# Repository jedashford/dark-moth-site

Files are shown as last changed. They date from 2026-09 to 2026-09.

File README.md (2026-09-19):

# Dark Moth — R6 integrated prototype

R6 combines the confirmed **ESP32-C3 SuperMini**, power electronics and five LED
drivers on one **18-column × 24-row (A–X) isolated-pad carrier**. The case has a
left-side button, the original faceted moth, a removable front diffuser and a
battery bay sized around the user's **67 × 36 × 10 mm, 3000 mAh protected pack**.

[Inspect the complete product](index.html#explore) ·
[Build the carrier in 3D](perfboard.html?board=carrier#workbench) ·
[Exact wiring instructions](CARRIER_GUIDE.md) ·
[Print setup](print.html) ·
[Download the R6 pack](dark-moth-r6-print-pack.zip)

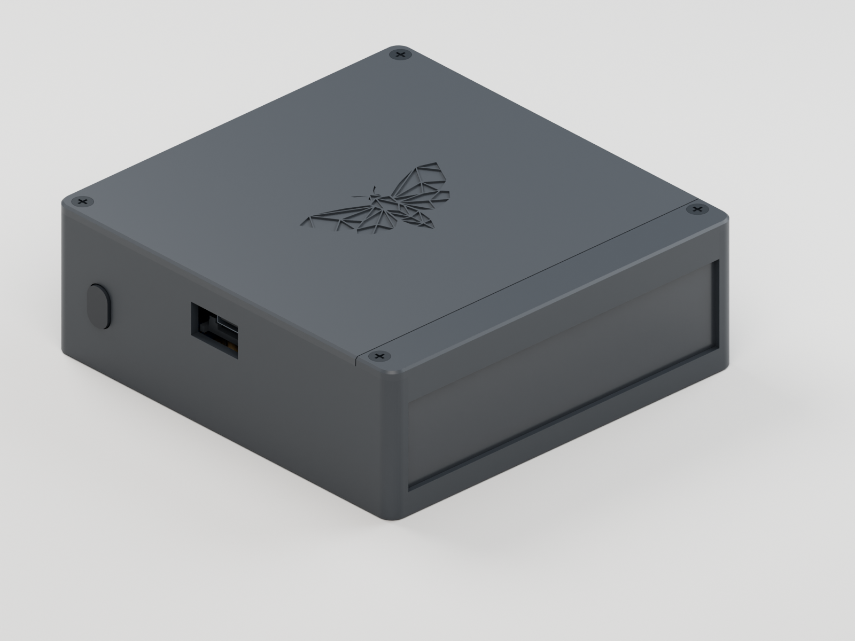
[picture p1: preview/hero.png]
R6 CAD assembly


**Prototype status:** digital checks, source-linked models and firmware builds do
not establish a working physical product. Purchased-part fit, actual battery
lead ratings, low-voltage operation, charging, thermal behavior and optical output
need the bench checks in [the electrical plan](PRODUCT_ELECTRICAL_PLAN.md).
Current evidence is recorded in [VERIFICATION.md](VERIFICATION.md) and
[verification-summary.json](verification-summary.json).

## What changed together

- A removable carrier cassette and raised module supports replace the old
  manufactured latch PCB and separate floor-mounted modules.
- The user's UMLIFE mini USB-C charger, separate regulated 5 V/12 V converters,
  a low-voltage supervisor and low-gate-voltage MOSFETs replace the earlier power arrangement.
  **New parts are required**; use the carrier guide's exact purchasing list.
- Five identical driver groups align on rows C/G/K/O/S. The underside carries
  insulated connections; the guide identifies every solder window and hole.
- The external harness uses **BATTERY 2-pin, BUTTON 2-pin and LIGHTS 6-pin**.
  The light connector is +12 V, green, red, blue, warm white, cool white.
- The ground-contact button uses an isolated active-LOW input. R6 firmware and
  R5 button wiring are incompatible. Flash only the revision you assembled.
- The case retains the original moth and **104 × 28 × 3 mm** removable diffuser.
  A removable insert supports the smaller **42 × 25 × 10 mm** battery.

## Build in this order

1. Read the [carrier guide](CARRIER_GUIDE.md) and check the actual board, module
   markings, battery and connector sizes. The blank is nominally 47.78 × 63.02 mm;
   the user confirmed the hole count, not the measured board outline.
2. Obtain the listed replacements and assemble one board first. Use the 3D
   inspector, hole tables and underside net view together. Shared ground means
   one electrically continuous network; unrelated positive rails and LED returns
   remain separate.
3. Follow the staged, current-limited electrical bring-up before connecting the
   battery. Do not build a batch from an untested first unit.
4. Load [R6 C3 firmware](FIRMWARE_GUIDE.md). Remove the internal 5 V service shunt
   before attaching the ESP's programming USB. The separate charging port faces
   the outside; programming access is with the lid removed.
5. Print and test the [coupon](prints/coupon.stl), then follow the
   [per-part print instructions](PRINT_GUIDE.md). All STL units are millimetres;
   exported files already have their intended bed orientation.
6. Install the carrier, battery restraint, remote button, three plug pairs and
   diffuser. Check the physical wiring and clearances before closing the lid.

## Battery and connectors

The user's battery has a factory 1.25 mm connector. The selected build replaces
only that connector with the kit's two-pin XH-style plug while retaining the
factory wires, protection circuit and sealed pouch. Change one conductor at a
time and insulate its completed contact before cutting the other. Use recessed
contacts on the battery side. Measure polarity before mating; wire colors and
housing orientation do not prove polarity.

The kit marked XH2.54 is not automatically the same geometry or rating as genuine
JST XH (2.5 mm). Use matched contacts/housings from the same kit and confirm their
fit and wire range. The connector model is a nominal fit allowance. Battery and
button are both two-pin: label both mating halves and keep them in their separate
case locations. Never swap them.

## Charge with the device off

Hold the side button for two seconds until the red cue, then release to shut
both regulated rails and the controller down. Only then connect charging USB.
Leave the button alone while charging; disconnect USB before switching the
device on again. A short tap or a Bluetooth "off" command only blacks out the
LEDs and is not the complete shutdown required for charging.

The smaller charger has no implemented automatic USB lockout or system
power-sharing circuit. This is the user-selected **off-while-charging** build.
Its battery terminals B+/B− and system terminals OUT+/OUT− have distinct roles;
the complete carrier ground goes to OUT−, never across the protection path.

Use the electrical guide's supervised open-case first-charge checks. Identify
and measure the actual charge setting, cell temperature, termination and
low-voltage cutoff before enclosing a unit. No pack-temperature sensor is
connected to this generic charger. [The charger review](CHARGER_REVIEW.md)
records the supplied module and limits.

## Print and service

[PRINT_GUIDE.md](PRINT_GUIDE.md) lists supports and orientation for every part.
[cad/parts.json](cad/parts.json) is the printable inventory. The downloadable
native support projects are unsliced reference setups; choose your real printer,
material and nozzle and inspect generated support paths before printing.

The diffuser is **purchased smoked acrylic**. `diffuser.stl` is its cutting/fit
template, not a recommendation to block the light with opaque black PETG.
Remove the two front rail screws to withdraw the sheet without opening the
main electronics lid. The dark stock previously described for the older case
was only about 94.8 mm wide; confirm the actual sheet before cutting 104 mm.

Disconnect battery and charging USB before lifting the electronics cassette.
Printed supports and the insulating liner must never press exposed solder joints
against metal hardware or the battery pouch. Wires need service slack and
strain relief at the plug saddles.

## Reproduce the design

Run from `v3-button/enclosure/`, or the extracted `dark-moth-r6/` directory.
Install OpenSCAD, Blender, Bambu Studio, Arduino CLI/ESP32 core and the Python
requirements. Geometry, slicing, firmware and browser checks use local temporary
workspaces; no command below uploads firmware or sends a print job.

```sh
python tools/build_perfboard_layout.py
python tools/build_perfboard_worksheets.py
python tools/verify_r6_electronics.py
python tools/build_firmware.py
python tools/build.py
python tests/verify.py
python tests/verify_variants.py
python tests/test_printability.py
python tools/slice_check.py
python tools/build_print_project.py
python tools/build_guide.py
/Applications/Blender.app/Contents/MacOS/Blender --background --python tools/render.py
python tests/test_full_assembly.py
python tests/audit_full_assembly.py
node --test tests/test_*.mjs
python tools/package.py
python -m unittest discover -s tests -p 'test_*.py'
```

The browser test requires Playwright and Chromium; set `PLAYWRIGHT_MODULE` if
using an existing installation. The release pack includes the exact compiled
firmware source and rejects stale source hashes or missing verification.

Run `python site/serve.py --port 8000` and open
[the local website](http://localhost:8000/). The deployed site is
[Dark Moth](https://jedashford.github.io/dark-moth-site/).

Historical KiCad files and earlier latch/driver worksheets are reference inputs
only. **CARRIER_GUIDE.md, the R6 carrier data and R6 firmware define this build.**

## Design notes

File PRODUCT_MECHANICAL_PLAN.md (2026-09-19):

# Dark Moth R6 mechanical implementation

This file describes the implemented R6 CAD in `cad/`, replacing the earlier
proposal. It is a **nominal printable prototype**, not a measured fit approval.
The actual purchased perfboard outline, connector housings, C3 clone and battery
remain unmeasured. Digital checks do not certify electrical performance, battery
charging, temperature, optical diffusion, or physical print fit.

The selected UMLIFE mini USB-C charger is used with the complete device off
while charging. The charger holder and model use the seller's provisional
18 × 14 × 5 mm dimensions and 1.5 mm USB overhang. There is no modeled NTC
connection or inherited BQ25185 power-path/temperature function.

## Preserved product features

- Dark faceted moth: original 44 mm mark, 0.5 mm recess.
- Captive side button and removable switch daughterboard carrier.
- Removable 104 × 28 × 3 mm smoked acrylic. Remove the front two screws and rail
  to lift the rigid sheet; the taller rail includes a lower retaining ceiling.
- Existing front LED rib, with a second bottom wire passage on the right.

The interior is 106.2 × 110.2 × 35.2 mm. The 2.4 mm shell/floor/lid produces a
**111 × 115 × 40 mm** closed outer envelope. The extra 12 mm rear space holds
three removable plug pairs; the extra 4 mm height accommodates the module tier.
The unchanged diffuser sits at case `[1.1, -1, 3.2]`, with its 28 mm axis vertical.
The button center moves rearward to `[0, 97, 15.5]`.

## Coordinate and parts contract

Case X points right, Y rearward, Z upward; the inside floor is Z=0. Coordinates
below are millimetres. `cad/parts.json` is the common printable inventory used
by CAD exports, assembled exports, slicing, rendering, and packaging. The full
scene is `preview/full-assembly.glb`; its item metadata is
`preview/assembly-parts.json`. Actual printable STL meshes are imported unchanged
into that scene. Nominal purchased hardware is labeled separately.

<!-- markdownlint-disable MD013 -->

| Item | Case placement / size | Retention and clearance |
| --- | --- | --- |
| Carrier | PCB underside `[3,22,8.2]`; 47.78 × 63.02 × 1.6 | Removable cassette, edge ledges, rear keeper |
| Hole grid | 18 columns × 24 rows, 2.54 pitch, nominal 0.9 drills | 432 isolated pads; X/Y hole origins read independently |
| C3 SuperMini | PCB underside `[2,23,21.8]`; 22.5 × 18 × 1.6 | Insulating rim, left keepers, removable right clamp with USB notch |
| UMLIFE charger | PCB underside `[4,50.875,21.8]`; outline 18 × 14 | Seller envelope, nominal left USB, removable clamp |
| 5 V regulator | PCB underside `[4,76,21.8]`; 13.1 × 8.1 | Separate rim and clamp |
| 12 V regulator | PCB underside `[21,76,21.8]`; 13.1 × 8.1 | Separate rim and clamp |
| Protected battery | `[62,19,1]`; 36 × 67 × 10 | Smooth 1 mm pad, loose bridge and lateral stops |
| Button pair | `[21,92,3]`; reserved 18 × 10 × 8 | Removable insulating strap through saddle slots |
| Battery pair | `[43,92,3]`; reserved 18 × 10 × 8 | Separate labeled saddle position |
| LED pair | `[69,88,3]`; reserved 20 × 20 × 8 | Six contacts; separate labeled saddle position |

<!-- markdownlint-enable MD013 -->

The current board outline assumes a 2.3 mm margin to the outer hole centers.
This **does not establish the purchased blank dimensions**: an 18 × 24 hole
board may have a larger outline. Confirm outside width/length and both edge-to-
first-hole offsets before printing the fitted cassette. Update the canonical
carrier data and CAD capture dimensions together if the stock differs.

All module PCB undersides are 12 mm above the carrier component face. The C3
uses unfitted/removed long headers and insulated pigtails. This geometry does
not fit an arbitrary stack of long module headers. Carrier adapter PCBs stand
3 mm above the carrier, with their total package tops at 5.8 mm; the tallest
specified lower-tier component is the 8.6 mm service header/shunt. The W16/W17
service header sits beside the tier and must be removed before programming USB.

## Printable fixtures and assembly

The inventory contains 17 printable exports: body, lid, rail, button,
switch_carrier, diffuser template, coupon, carrier_tray, carrier_keeper,
module_tier, four module clamps, connector_saddles, battery_bridge, and
battery_insert. The insert is optional and hidden in the normal assembled view.

The tray is fixed at `[24,19]`, `[54.5,25]`, `[54.5,82]`. The carrier rests at
Z=8.2, with a removable 0.4 mm insulating liner at Z=2.2. Its canonical wiring
reserve extends from 5.3 to 1.6 mm below the carrier top, leaving 1.9 mm between
the reserved lowest point and the liner. This reserve already includes wire
radius. Remove the module tier, tray screws and cassette before sliding the
board out through the rear with its keeper removed.

The module tier mounts at `[8,19.5]`, `[46,19.5]`, `[15,87.75]`, and
`[46,87.75]`. Its open rims support PCB edge lands. Retaining lips and removable
clamps capture the edges with nominal 0.25 mm vertical play; clamp screw bosses
have 0.25 mm nominal lateral clearance to the substrate. Inspect actual copper,
solder and components before using these edge lands. The left charger USB edge
is open. Do not clamp a solder joint or place metal screws over the antenna.

The battery bridge has no screw over the pouch. Its roof underside is Z=13.5,
2.5 mm above the nominal pack. Use a smooth removable soft restraint to prevent
rattle without squeezing the pack. Screws sit outside the battery at X60/X100,
Y52. No thermistor is installed: the selected charger exposes no verified
pack-temperature input.
The optional insert positions a 42 × 25 × 10 mm smaller protected pack.
Remove it for the 67 × 36 × 10 mm pack. Pack lead exit and bend space occupy
the rear of the battery bay. Preserve the pack's factory protection and leads when
reterminating its connector, following the electrical guide.

Three mated connector pairs are included in the model. Their dimensions are
**reservations for the user's kit**, not a verified genuine JST XH footprint.
Saddles support the housings; removable insulating straps restrain the housing
rather than loading its latch. Disconnect and release the straps before lifting
the tier. Do not interchange the two similar two-pin pairs.

The model includes 28 nominal screws: four M2.5 × 10 case screws, two M2 × 8
side-switch screws, three M2 × 4 tray screws, four M2 × 6 tier screws,
two M2 × 6
keeper screws, eight M2 × 4 clamp screws, three M2 × 4 connector-saddle screws,
and two M2 × 16 battery-bridge screws. Blind pilots continue 1.8 mm into the
2.4 mm floor, retaining 0.6 mm exterior skin. Actual screw head/thread geometry
and printed pilot fit require the coupon and a trial assembly.

## USB and wiring service

The charger window is 16 × 9 mm centered at Y57.875, Z25.0 in the left wall.
Its USB mouth is provisionally at X2.5, using the seller's stated 1.5 mm
overhang. Shell height, pad locations and cable plug dimensions remain nominal.
C3 programming USB is accessed
with the lid removed, after removing the service shunt. Do not assume exterior
access to this internal right-facing connector.

The full 3D model includes carrier component leads, canonical underside jumpers,
39 intermediate solder joints (32 retained component leads and seven separate
risers), module pigtails, three connector-pair harnesses, LED wiring, battery
leads. These wires reserve volume and service slack. They do not
prove conductor-to-conductor separation or the purchased wire bend radius.
Power and common-ground harnesses use a conservative 1.6 mm outer diameter
reservation. The collision audit fails if any visible wire cannot be tested.

All charger, C3 and Pololu physical pad assignments remain unverified. Their
module harness ends are visibly parked loose above each module and
marked `physical_endpoint_unresolved`. Their logical destinations remain in the
electrical manifest. This prevents a plausible-looking model from inventing a
supplier pinout. Complete these assignments after identifying actual stock.

## Validation and print procedure

Installed tools: OpenSCAD 2026.06.12, Blender 4.5.2 LTS, Bambu Studio 02.08.02.61.
OrcaSlicer is not installed. Python uses the isolated
`/tmp/dark-moth-perfboard-venv` environment with trimesh/manifold/scipy.

The reproducible checks are:

1. `tools/build.py`: export every print and assembly STL from current CAD,
   regenerate the drilled carrier substrate, and create portable plate layouts.
2. `tests/verify.py`: solid/manifold, installed-part clashes, nominal hardware
   clearance, board/keeper motion, button travel, acrylic removal/retention,
   screw access, and portable plate bounds.
3. `tests/test_printability.py` and `tests/verify_variants.py`: orientation,
   first-layer contact, moth recess, and specified fit variants.
4. `tools/slice_check.py`: actually slice every printable part with isolated
   reference P1S / 0.4 mm / PETG / 0.2 mm profiles. Require no slicing warnings
   or effective-setting mismatches. Support is required for body, button and
   carrier_tray. The battery bridge prints roof-down with vertical bores.
5. `tools/build_print_project.py`: create and round-trip the three native
   support-bearing reference projects. Delivered projects contain no G-code.
6. `tools/render.py`, `tests/test_full_assembly.py`, and
   `tests/audit_full_assembly.py`: export real geometry, inspect GLB buffers and
   inventory/positions, audit solid hardware/wires against every installed
   printed obstacle, and render six views from the actual model.

The collision report explicitly lists excluded non-solid label/emitter
surface fragments; carrier copper pads are solid rings. It is a partial audit
against printed parts; it does not certify
module-to-module or conductor-to-conductor fit. Keep the limitations with the
reports and release. Final current results live in `build/verification.json`,
`build/slice/report.json`, `profiles/manifest.json`, `build/full-assembly-tests.json`,
and `build/full-assembly-collision-audit.json`; their hashes must match the
packaged sources.

Before printing the fitted parts, measure board outline/offsets, battery
including seam/protection/lead exit, both connector pair types, C3 USB/header
configuration, actual module underside projections, and acrylic thickness.
Print the coupon first. After fitting, verify plug insertion/removal, tier lift
with service slack, battery restraint without compression, USB access, button
return, and diffuser removal. Electrical bench qualification
is separate and is specified in `PRODUCT_ELECTRICAL_PLAN.md` and `CARRIER_GUIDE.md`.

## Verification state

The compact UMLIFE charger geometry passes 734 nominal CAD/assembly checks,
979 parameter-variant checks, all 17 actual STL slices, and all three native
support-bearing print-project round-trips. Ten actual-GLB tests verify the
169-part inventory, source positions, all 39 intermediate solder-joint contacts,
and the order of the exploded stack. The solid collision audit checks 153
logical parts, including all 55 wire groups, against all 15 installed printed
obstacles with zero intersections. Seven items have excluded label/emitter
surface fragments; no wire group is skipped.

These are digital prototype results. They do not establish the purchased blank
outline, actual connector fit, module pad identities, printer tolerances,
wire-to-wire clearance, temperature or electrical operation. No physical
prototype has been printed. The final render manifest records the current six
views and their source hashes; the release gate verifies those hashes together
with the CAD, slicing, model and browser reports before packaging.

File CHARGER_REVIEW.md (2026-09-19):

# User-supplied mini USB-C charger — compatibility review

**Selected for R6: manually switch the complete device off while charging.** The
user selected this simpler operating mode. The UMLIFE module replaces the
previous Adafruit BQ25185. Current wiring and assembly steps are in
[CARRIER_GUIDE.md](CARRIER_GUIDE.md); low-battery shutdown uses the separate
TLV803EA30DBZR supervisor described in
[PRODUCT_ELECTRICAL_PLAN.md](PRODUCT_ELECTRICAL_PLAN.md).

## What the supplied listing establishes

The supplied screenshot matches the
[UMLIFE B0BRXYZTWN listing](https://www.amazon.com/dp/B0BRXYZTWN). The seller
describes a 14 × 18 × 5 mm board, with the USB-C socket protruding about 1.5 mm.
The screenshot's inch conversions are inconsistent, so the metric dimensions
remain provisional until the actual board is measured.

The seller specifies 1 A linear charging, 4.2 V final voltage, 100 mA
termination, recharge at 4.05 V, and 100 mA precharge below 2.9 V. It also
claims 2.4 V over-discharge protection and a 4 A protection threshold. Those
thresholds are not a continuous-current rating or validation of the purchased
board, battery, connectors or wire. The listing says input power may be needed
to activate the protection circuit initially.

The photograph shows separate B− and OUT− pads, input pads and two positive
pads. This resembles a 4056-family charger plus a separate protection circuit.
The exact IC identity, resistor settings, protection wiring, pad coordinates and
USB-C implementation are not established by the photograph. Do not infer the
right-hand positive pad assignments from perspective alone.

## Why the charging behavior matters

A battery charger with current-based charge termination needs to distinguish
cell charging current from the device's operating load. A system load connected
across the charging output can prevent or disturb termination. The
[Top Power TP4056 datasheet](https://www.toppwr.com/uploadfile/file/20240913/66e3a367981a1.pdf)
establishes the behavior of that particular IC; it does not establish which IC
is fitted to this generic module.
[Microchip AN1149](https://www.microchip.com/en-us/application-notes/an1149)
explains separate system power paths for simultaneous operation and charging.

The selected and rejected operating paths are:

1. **Selected: turn the complete device off while charging.** The smaller module
   may be usable after verifying its actual pads, charge-current setting, cell
   limits and protection behavior. The complete device must be off, not merely
   commanded to black LEDs. The existing latch and separate 5 V / 12 V
   regulators still perform necessary functions.
2. **Not selected: operate the light while charging.** This would need a
   power-path charger or a separately designed and qualified power-sharing
   circuit. The smaller module's protection circuit alone is not evidence of
   this function. A direct USB-to-battery or USB-to-latched-supply jumper is not
   an acceptable substitution.

For a module with battery protection in its negative path, battery-side negative
and protected output negative are distinct circuit nodes. They must not be
casually joined through the carrier ground or programming USB. The protected
battery's external leads remain intact apart from the user-requested connector
replacement; no access to raw cell tabs or removal of pack protection is
required.

## Integration consequences

After identifying the actual pads, the selected protected-module arrangement is
pack external positive/negative to **B+/B−**, output positive to the latch's
**SYS**, and **OUT−** to the carrier's complete system ground. The pack's own
protection does not make module B− and OUT− interchangeable. Confirm whether IN−
is connected to OUT− on the purchased PCB; do not assume it or bridge the two
negative nodes. Check the two positive pads for continuity and their labels
before selecting either one. Programming USB ground must remain on the system
side of the protection path, following the revised service-isolation procedure.

| Required behavior | Minimum change in principle | Qualification still needed |
| --- | --- | --- |
| Manually off during charging, bench prototype | No extra load-sharing components; retain the latch and both regulators. Shut the latch down completely before charging and leave the button alone. | This procedure does not prevent a button press from powering the load. Verify termination with the complete load actually off. |
| Automatically forced off whenever charging USB is attached | A USB-present hardware inhibit that overrides both START and HOLD; merely forcing firmware HOLD LOW does not defeat the held START contact. | The inhibit must respect the module's ground domains. A discrete transistor clamp is a candidate, not an implemented circuit or assigned carrier footprint. |
| Light usable while charging | A separate source-selection/power-path stage, or retain the BQ25185. | A P-channel MOSFET, Schottky diode and pull-down are the core of the [AN1149 approach](https://ww1.microchip.com/downloads/en/appnotes/01149a.pdf); actual device ratings, supply budget and transient behavior require a complete design. These three parts alone do not restore all BQ25185 functions. |

The replacement removes the BQ25185's approximately 3.0 V battery cutoff. The
selected Pololu converters can continue operating below their startup voltage,
down to a specified 1.3 V input. R6 now adds a TLV803EA30DBZR supervisor that
clamps the hold transistor below a specified 3.0184–3.1416 V on the switched
battery rail. Actual trip, rail collapse and absence of restart require bench
qualification; the listing's 2.4 V protection claim is not a substitute. The
clamp works with START released; a held button bypasses it. The MCU has no
battery ADC, and this is not a measured cutoff result.
[Pololu regulator specification](https://www.pololu.com/product/4941)

At the seller's stated 1 A charging current, a linear charger would dissipate
approximately (5 − 3.7) × 1 = **1.3 W** at a 3.7 V cell, before other losses.
This is a calculation, not a measured temperature or proof of sustained current
on the small PCB. The actual chip, charge-setting resistor and thermal behavior
must be identified before prescribing a resistor change. Do not transfer the
BQ25185's 250 mA jumpers, NTC connection, timer or temperature behavior to this
module. The pack's 1C discharge claim does not specify its permitted charge
rate.

For simultaneous use, USB must supply both system load and charging current.
Verify the actual USB-C CC implementation and compatibility with the intended
cable/source; a Type-C receptacle alone establishes neither successful C-to-C
attachment nor an available current budget.

## Purchased-hardware checks before assembly

Verify the actual module's silkscreen, chip marking, dimensions, USB overhang
and charge setting. The small module does not expose an established
pack-temperature connection. No pack temperature sensor or charge inhibit is
fitted. Follow the supervised, open-case, independently monitored 15–30°C
prototype charging procedure until cell limits and thermal behavior are
qualified. Do not transfer BQ25185 pad names, ground arrangement, current
jumpers, NTC or timer claims.

The canonical circuit now uses CHG.OUT+/OUT− for the latch/system supply and
CHG.B+/B− for the factory-protected pack's external leads. Mechanical and viewer
artifacts are regenerated from that contract. Both ground domains remain
distinct, and all physical pad positions remain unmeasured.

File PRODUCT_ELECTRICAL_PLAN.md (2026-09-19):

# R6 electrical design and physical acceptance

The implemented R6 prototype uses the confirmed ESP32-C3 SuperMini, the owned
UMLIFE mini USB-C charger with the complete device off during charging, separate
regulated 5 V and 12 V supplies, a parallel P-MOSFET latch, an isolated
active-LOW button sense stage and five logic-level LED MOSFETs. Its exact holes,
purchasable parts and assembly procedure are in
[CARRIER_GUIDE.md](CARRIER_GUIDE.md). The canonical generated circuit is the
`carrier` board in [perfboard-layout.json](electronics/perfboard-layout.json).
The legacy latch, driver and combined boards remain historical references.

**Status: design and nominal layout verified; physical product qualification
pending.** A render, compiler result or graph check cannot establish working
charging, thermal capacity, minimum dim level or fit of purchased parts.

## Circuit and parts

```text
Protected 1S pack → CHG B+/B−     USB-C → CHG USB (device OFF)
                         CHG OUT+ (SYS)
                              ↓
                    2 × DMP2035U in parallel
                              ↓ SW_SYS
                 ┌────────────┴─────────────┐
           U3V16F5 / 5 V              U3V16F12 / 12 V
                 ↓                         ↓
            service shunt             LED common +
                 ↓                         ↓
          C3 SuperMini VIN          five DMG2302UK sinks
```

Both DMP2035U sources connect to SYS, drains to SW_SYS and gates to P_GATE. A
100 kΩ source-to-gate resistor turns them off. START is pulled to ground by the
remote normally-open button; a 1N4148 (anode P_GATE, cathode through 1 kΩ to
START) initiates power. A 2N3904 pulls the gates down through 1 kΩ while its
base receives ESP HOLD through 10 kΩ; a 100 kΩ base-emitter resistor prevents
floating hold drive. Use the low-leakage 1N4148, not an unqualified power
Schottky whose leakage could falsely pull the floating START node.

Button sensing uses a separate 2N3906 emitter at SYS, base pulled to SYS by 100
kΩ and to START by 22 kΩ. Its collector drives a second 2N3904 base through 10
kΩ, with a 100 kΩ base-emitter resistor. That NPN emitter is grounded and its
collector connects to BUTTON, pulled up **only to ESP 3V3** through 10 kΩ. Thus
the unpowered GPIO has no raw battery divider or steering diode attached.

Each DMG2302UK has gate pin 1 through its own 100 Ω PWM resistor, source pin 2
to ground, drain pin 3 to one LED return and a separate 10 kΩ gate-source
pull-down. The five rows remain aligned. Both selected SOT23 parts have pin
order 1 G, 2 S, 3 D. TO92 stock parts require manufacturer-specific pinout
identification and formed/sleeved role leads.

Final external plugs are BATTERY 2 (+/−), BUTTON 2 (START/GND), LED 6
(+12V/G/R/B/WW/CW). The former OUT+/BTN_N button harness is incompatible. System
ground is **CHG.OUT−**; the protected pack external negative connects only to
**CHG.B−**. These negative domains must not be bridged. A removable 5 V shunt at
W16/W17 isolates REG5 from ESP VIN before USB programming; no reverse-current
blocking is assumed for the clone.

## Module and adapter evidence

| Part | Selected source | Established fact and limit |
| --- | --- | --- |
| CHG | [UMLIFE owned module](https://www.amazon.com/dp/B0BRXYZTWN) | Seller claims 18 × 14 × 5 mm, 1.5 mm USB overhang, 1 A charging; actual pads, settings, limits and dimensions unmeasured. |
| REG5 | [Pololu U3V16F5 #4941](https://www.pololu.com/product/4941) | 5 V, 13.1 × 8.1 × 3 mm without headers; output-current graphs are typical and depend on input and temperature. |
| REG12 | [Pololu U3V16F12 #4945](https://www.pololu.com/product/4945) | 12 V version, same envelope; 2.7 V startup requirement. |
| QP ×2 | [Diodes DMP2035U-7](https://www.diodes.com/datasheet/download/DMP2035U.pdf) | RDS(on) maximum 45 mΩ at −2.5 V and 62 mΩ at −1.8 V under the 25°C test conditions. |
| LED Q ×5 | [Diodes DMG2302UK-7](https://www.diodes.com/datasheet/download/DMG2302UK.pdf) | RDS(on) maximum 120 mΩ at 2.5 V; Qg 1.4 nC typical at 4.5 V, Ciss 130 pF typical. |
| Adapters ×7 | [Adafruit 1230](https://www.adafruit.com/product/1230) | Each retail set includes five SOT23 boards; buy two sets for one product, or ceil(7 × product count / 5) for a batch. |
| Service header | [Harwin M20-9990246](https://www.harwin.com/products/M20-9990246) | 2-pin 2.54 mm header; separately obtain matching shunt and check its actual height. |
| UUV | [TI TLV803EA30DBZR](https://www.ti.com/product/TLV803E/part-details/TLV803EA30DBZR) | Standard DBZ open-drain supervisor, 3.08 V nominal falling threshold; 100 nF ceramic supply bypass. |

The
[adapter Eagle drawing](https://github.com/adafruit/Adafruit-SMT-Breakout-PCBs/blob/9c2437974968b6cbf8347792d0e2a7c5c77a9249/6-pin%20SOT-23.brd)
establishes its 10.16 × 7.62 mm outline, header grid and actual Q1/Q2 net
mapping. Copper traces are 0.3048 mm wide; thickness is unspecified. There is
**no manufacturer adapter current/thermal rating** to transfer to this assembly.
Ideal equal sharing at 2 A total and 45 mΩ per device gives 0.09 W total channel
loss at 25°C; this calculation excludes traces, joints, unequal sharing and hot
RDS(on). A package absolute current rating does not qualify adapter copper.

The charger uses an 18 mm USB-axis length and 14 mm transverse width from the
supplied seller image. The inch conversions in that image are wrong; metric
dimensions, 5 mm total height and 1.5 mm USB overhang remain nominal. USB faces
left; no physical pad centre or chip identity is inferred. All four modules sit
on a removable tier with PCB undersides 12 mm above the carrier top. C3 antenna
keepout and purchased module fit require physical checks.

## Hardware low-battery cutoff

UUV is **TLV803EA30DBZR**, the standard SOT23 DBZ pinout: pin 1 GND at Q4, pin 2
active-LOW open-drain RESET at R4/H_BASE, pin 3 VDD at R7/SW_SYS. The R/V pinout
alternatives and push-pull TLV809E are not substitutes. CUV, a nonpolar 100 nF
ceramic capacitor at U7/U8, bypasses SW_SYS to GND. No battery ADC or extra GPIO
is connected.

The [TI datasheet](https://www.ti.com/lit/ds/symlink/tlv803e.pdf) specifies 3.08
V nominal falling threshold, ±2% across its stated temperature range
(**3.0184–3.1416 V**), 0.9–1.5% hysteresis and 130–270 ms release delay. Its
open-drain output specifies at most 0.3 V at 500 µA with VDD=1.7 V; RH=10 kΩ
supplies at most 330 µA from 3.3 V. It clamps the hold transistor's base without
driving it high. The selected supply is downstream of the latch, so loss of the
held supply continues to hold RESET low while the rail collapses. Below 0.7 V
the output state is unspecified; qualification must verify the ESP hold signal
has collapsed and no restart occurs.

This is a circuit design inference from the specified parts: with START
released, the clamp turns QH off and lets RKEEP turn QP off. Confirm it with
actual transistor leakage, rail capacitance, load transients and temperature. A
held START contact can bypass the clamp; do not keep holding the button or
repeatedly restart a depleted pack. Startup requires holding about one second,
including the supervisor release delay and firmware boot. The module's claimed
2.4 V protection threshold is a backup limit, not the normal cutoff.

## Load, battery and charging limits

The local supplier PDF
`old/yuji_rgbww50505/F318000x.26-2.3_YJ-BC-HRB-RGBWW5050-xxV.pdf`, page 9,
implies 2.88 W typical and 3.19 W table-maximum for 100 mm of the specified 12 V
RGBWW strip. Reserve 0.27 A at 12 V including simultaneous five-channel
operation. This is a supplier-derived expectation, not measured strip current.
Reserve 0.5 A at 5 V for ESP startup/transients until measured. The 5.69 W
combined budget at **assumed** 85% conversion efficiency and 3.3 V requires
about 2.03 A before charger, switch and wiring losses. Qualify the complete path
for at least 2.5 A and measure actual peak/inrush; otherwise reduce the
permitted brightness/load according to measured limits.

The user-selected JLJLUP LP103665 listing states protected 1S, 3.7 V, 3000
mAh/11.1 Wh, 1C and 67 × 36 × 10 mm. That listing does not qualify the factory
wire, protector or replacement contacts. The user authorized replacing the
factory connector with their XH-style 2-pin connector while preserving factory
leads, protection and pouch. The guide records one-conductor-at-a-time
termination, insulated/recessed battery contacts and polarity verification.

The charger is used only with the complete device switched off. A black LED
command is insufficient because ESP and converter load can disturb charge
termination. There is no automatic USB-present lockout. Release the shutdown
button, verify both regulated supplies are off, then plug in charger USB; unplug
it before switching on. See [CHARGER_REVIEW.md](CHARGER_REVIEW.md).

The seller claims 4.2 V charging at 1 A, 100 mA termination and protection at
2.4 V/4 A. These are not validated specifications for the purchased unit or
continuous-current ratings. At 5 V input and 3.7 V cell, 1 A linear charging
implies about 1.3 W chip dissipation before other losses; this calculation is
not a temperature measurement. Identify actual IC/current setting and confirm
the pack's permitted charge rate before prescribing resistor changes. No
previous BQ25185 jumper, 250 mA, timer or pack-NTC instruction applies.

No pack temperature sensor is fitted. Until actual cell charge limits and module
thermal behavior are qualified, charge **open-case and supervised, with
independently monitored pack temperature at 15–30°C**, stopping outside that
range. Enclosed/unattended charging remains unqualified. Measure off-state
battery current with charging USB absent/present and at full/low battery;
charger/protector standby draw and indicator behavior remain unmeasured.

## Firmware contract and rejected alternatives

C3 GPIOs are HOLD 3, BUTTON 4, G 5, R 6, B 7, WW 10, CW 20. HOLD is active HIGH
and must assert before serial/BLE delays. BUTTON is digital active LOW; old ADC
thresholds are obsolete. Keep gates LOW during boot. Consume the boot press
until release. Long-hold shutdown takes effect on release because a held START
contact forces power on. A firmware crash with HOLD high needs battery
disconnection; crash-independent forced-off requires a different controller.

The retained 2 kHz/14-bit PWM has a 30.5 ns least pulse. Datasheet DC resistance
and compiler success cannot establish optical response at that pulse width.
Measure gate, drain and optical output, select the minimum reliable pulse and
recalibrate. Battery percentage remains unavailable without a separately safe
measurement circuit; do not connect raw battery to an unpowered ADC.

| Alternative | Decision |
| --- | --- |
| SS8550 main pass | Existing base drive does not guarantee low loss at the expected current. |
| Raw 1S to ESP VIN / 3V3 | VIN regulator headroom is unestablished; 4.2 V on 3V3 exceeds chip supply limits. |
| BS170 directly from 3V3 | No applicable guaranteed on-resistance. |
| BS170 with three dual gate-driver DIP ICs | Can be engineered but requires more parts, decoupling and area than the selected adapters. |
| AO3400A output MOSFET | DC-capable alternative with larger typical gate charge; not selected. |
| Simultaneous use with the mini charger | Not selected by user; would need a separately designed power path and source budget. |
| One combined 5 V charger/boost feeding 12 V | Shared 1 A-class output reduces headroom compared with separate branches. |
| Historic 24 V manufactured PCB BOM | Different assembly; it is not evidence that this hand-built circuit works. |

## Bench acceptance record required

Use a current-limited source for initial SYS tests with cell/charger detached. A
sink-capable battery simulator is required for charger tests; an ordinary
source-only bench supply must not absorb charging current.

| Check | Record and acceptance |
| --- | --- |
| Unpowered | Verify every named pad/net; no copper short across PWM resistors, between supply outputs, or across removed JSV. Confirm diode/FET orientation and connector polarity. |
| Latch/button | Repeat starts at 4.2/3.7/3.3 V, short/held/bouncing presses; release holds power, shutdown removes both rails, GPIO remains within device limits throughout. |
| ESP supply | Scope VIN/3V3 at boot, BLE radio activity and LED load steps. Target 3V3 3.15–3.45 V without resets, subject to exact board specifications. |
| LED supply | 12 V meets strip/module limits for individual and all-channel load. Record current, ripple, inrush and lowest functioning battery voltage. |
| QP/adapter | Measure each branch current, total drop and temperature at low-cell maximum load. No claimed rating from the SOT23 absolute current limit. |
| Optical | Measure minimum reliable pulse/light, monotonicity, zero-state glow and transitions; re-run calibration for the new MOSFETs. |
| Low battery  | Sweep loaded SW_SYS through 3.0184–3.1416 V; record actual trip, rail collapse and no automatic restart after rebound with START released. |
| Charging | Verify actual charge current, pack limits, termination/recharge, off-state USB insertion/removal and temperatures; no operation while charging. |
| Temperature  | Test final allowed load/charging modes to equilibrium at declared maximum ambient; measure pack, charger, converters, adapter and case with margin to exact limits. |
| Service/off  | Measure off current, GPIO/USB backfeed and repeated flashing with JSV removed; verify reconnect procedure. |
| Mechanics/RF | Actual parts fit, protected wires, no cell compression, accessible shunt, antenna keepout and closed-case BLE. |

[verification.json](electronics/verification.json) reports independent
declared-net, role and nominal-envelope checks with input hashes. It explicitly
retains `physical_validation: false` until real measurements are recorded
separately.

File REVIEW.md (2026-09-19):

# Dark Moth R6 — design review

R6 integrates the 18 × 24 carrier, selected C3, compact UMLIFE charger, two
regulated supplies and three removable plugs into the Dark Moth case. The
original faceted moth, side button and removable smoked diffuser are retained.
The larger protected battery has a dedicated bay, smooth pad, removable bridge
and an optional insert for the smaller pack.

## Mechanical decisions

<!-- markdownlint-disable MD013 -->

| Requirement | Implemented R6 decision |
| --- | --- |
| Preserve the original appearance | Original 44-path moth, 44 mm wide and 0.5 mm recessed; dark case and smoked front sheet. |
| Fit the integrated carrier | Removable tray, insulating liner and rear keeper for the nominal 47.78 × 63.02 × 1.6 mm board; no invented carrier mounting holes. |
| Fit the selected modules above the discrete circuit | Open insulating tier with individual rims and removable clamps; PCB undersides 12 mm above the carrier top. |
| Use the user's compact charger | Nominal UMLIFE 18 × 14 × 5 mm envelope, left-facing USB, compact holder. Full device must be off while charging. |
| Fit the larger protected pack | 67 × 36 × 10 mm nominal pack with 1 mm smooth pad, restraint screws outside the pouch and rear lead clearance. |
| Make external connections removable | Two-pin battery, two-pin button and six-pin LED plug pairs, each labeled and retained in a saddle. |
| Keep the side control serviceable | Captive key centered at Y97, Z15.5; 0.35 mm nominal travel and a separate retained switch daughterboard. |
| Replace the diffuser independently | 104 × 28 × 3 mm sheet in side grooves and a lower stop; remove two front screws and the rail. |
| Avoid a long printed front bridge | Open-top body window; the removable rail supplies its lintel. |
| Show every specified assembly item | One canonical model inventory with 169 selectable groups, including 33 carrier assemblies, 28 screws, six plug halves and 55 wire groups. |
| Keep print exports and rendering consistent | Import exact assembly STLs into the full model; shared `cad/parts.json` drives print and assembled-part inventories. |

<!-- markdownlint-enable MD013 -->

The case is 111 × 115 × 40 mm outside. The original 9.2 mm LED-to-acrylic gap
is retained without claiming optical uniformity. The side charger window is
16 × 9 mm; ESP programming USB is reached with the lid off and service shunt
removed. [The mechanical plan](PRODUCT_MECHANICAL_PLAN.md) records placements,
fixture details and outstanding measurements.

## Electrical representation

The current source is the integrated carrier in `electronics/perfboard-layout.json`.
The model contains its 432 drilled isolated pads, all 33 placed component
assemblies and their leads, 17 underside conductors, and all 39 intermediate
solder joints. The seven added riser wires are distinct from the 32 retained
component leads. A low-battery supervisor and nonpolar bypass capacitor are
included in the revised carrier.

The current build no longer uses the manufactured KiCad main PCB, BQ25185
charger, its NTC arrangement, or the former TP4056/MT3608 placement. The UMLIFE
module has distinct battery and output negative nodes; the model and guide
preserve that distinction. The authoritative instructions are
[CARRIER_GUIDE.md](CARRIER_GUIDE.md) and
[PRODUCT_ELECTRICAL_PLAN.md](PRODUCT_ELECTRICAL_PLAN.md).

Purchased modules, connector housings, screws and wiring are nominal models.
The C3 details are illustrative clone geometry; the charger and regulator
models do not invent unidentified chips or physical pad coordinates. Module
wire ends are explicitly marked unresolved and parked loose above each module
until the actual labeled pads are identified. The complete device must be
switched off before charging; no automatic charging lockout is claimed.

The full model preserves every wire. The Inside view hides wiring to expose
the mechanical arrangement, while the wiring and exploded views retain it.
The exploded stack is checked so modules appear above their tier and clamps
above the modules. Rendered smoke/transmission and other materials are
illustrative; the views are unlit geometry evidence.

## Verification and physical boundary

Current compact-charger checks pass: 734 default geometry checks, 979 parameter
checks, 17 actual slices and three support-project round-trips. Ten GLB tests
inspect actual mesh buffers for inventory, placement, drill rings, component
leads, solder-joint contacts and the exploded order.

The solid collision audit checks 153 logical groups, including **all 55 wire
groups**, against all 15 installed printed parts, with zero intersections above
0.01 mm³. Seven items contain excluded label/emitter surface fragments; no wire
is skipped. This is a partial check against printed obstacles, not a supplier
fit or conductor-to-conductor clearance certificate.

All 17 printable exports are connected solids with connected first layers.
[Printability](PRINTABILITY.md) identifies the three support-bearing parts and
[Verification](VERIFICATION.md) links the reports. Actual carrier outline,
module projections, connector dimensions, screw forms, acrylic thickness and
battery seams/lead exit still require measurement and dry fit. The retained
nominal carrier outline must not be inferred solely from the 18 × 24 hole count.

No physical print or operating electrical prototype has been qualified.
Charging, cutoff behavior, temperature, switch feel, connector retention,
support removal and light output require the staged physical checks in the
build guides. This release supplies a digitally checked prototype for that
first-build process.

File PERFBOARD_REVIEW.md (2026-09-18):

# Perfboard circuit review

This is an electrical review of the inherited R5 circuit, not a new circuit design or physical approval. The perfboard layout transfers its existing connections to isolated solder pads. Follow [the build guide](PERFBOARD_GUIDE.md) for assembly; use this review to qualify one powered prototype before repeating it.

## What is established

- The corrected KiCad board's 34 pads match [pcb-pads.json](electronics/pcb-pads.json). Its component roles, values and net names are the source for the latch layout.
- The five independent low-side drivers and both MCU pin maps are recorded in [interconnects.json](electronics/interconnects.json). The [driver reference layout](electronics/driver-layout.json) defines its component holes.
- The R5 firmware reads the 100 kΩ / 100 kΩ button divider through the ADC, with 1000 mV press and 500 mV release thresholds. It initializes attenuation before reading and disables optional battery telemetry by default.
- No physical perfboard assembly, measured cold start, full-load thermal test or batch qualification has been supplied. A connectivity check or a 3D model does not establish those results.

## 1. SS8550 load and voltage loss

QP carries **both the boost input current and the ESP supply current**. Its 330 Ω base resistor allows less than `4.2 V / 330 Ω = 12.7 mA` even before subtracting transistor voltage drops. The [onsemi SS8550 datasheet](https://www.onsemi.com/download/data-sheet/pdf/ss8550-d.pdf), page 2, specifies its 800 mA saturation voltage using **80 mA base current**. Therefore that saturation voltage is not guaranteed by this circuit. The 1.5 A absolute current rating is not proof of low loss or acceptable enclosed temperature.

The repository's primary Yuji strip datasheet, `old/yuji_rgbww50505/F318000x.26-2.3_YJ-BC-HRB-RGBWW5050-xxV.pdf`, page 9, gives 7.2 W/m typical per white channel and 4.8 W/m per RGB channel. For the specified 100 mm strip, all five together are **2.88 W typical**, or **3.19 W** using that table's maxima.

At an **assumed, unmeasured** 90% boost efficiency, 2.88 W requires about 0.865 A from 3.7 V or 1.067 A from 3.0 V. That excludes the ESP and any reduction in boost input voltage caused by QP. Actual conversion efficiency, strip current and simultaneous channel settings must be measured. The older claim that total battery draw is “well under 1 A” is not an established limit.

Measure QP emitter-to-collector loss, input current and temperature across the intended battery/load range. Unstable operation, excessive loss or temperature requires resolving the circuit limitation before batch construction; a brief successful light-up is insufficient.

## 2. ESP power through its VIN regulator

The inherited path is `protected cell OUT+ → QP → VSW → ESP 5V/VIN → onboard regulator → 3V3`. Its margin depends on the exact clone's regulator, any series diode and wiring loss. A regulator intended to deliver 3.3 V needs its specified input headroom after those losses.

The [ESP32-C3 datasheet](https://documentation.espressif.com/ESP32-C3_Datasheet_en.pdf) and [ESP32-S3 datasheet](https://www.espressif.com/sites/default/files/documentation/esp32-s3_datasheet_en.pdf) specify the chips' supply requirements. They do **not** qualify an unidentified SuperMini board's VIN path. Identify the regulator and measure 3V3 during cold boot, BLE activity and changing LED load, including the lowest intended cell voltage.

Do not substitute a raw-cell connection to 3V3: a charged 1S cell reaches 4.2 V. Keep external power disconnected during USB flashing until the actual module's reverse-power behavior is established.

## 3. Button voltage reaches an unpowered GPIO

While pressed, the existing path is `OUT+ → switch → Db → Rbtn 1 kΩ → GATE`. GATE is connected to **both QL gate and the ESP latch GPIO**. It receives voltage before ESP power has risen. The 100 kΩ / 100 kΩ SENSE divider also receives button voltage during startup.

Rbtn limits current but provides neither isolation nor a defined logic-voltage clamp. Unpowered GPIO behavior can affect startup and may back-power the ESP. At full cell voltage, the direct latch input also needs checking after the ESP has started. The ESP datasheets give powered input-voltage limits relative to the relevant VDD domain; this review has not established an allowed power-off injection current for this arrangement.

Measure latch-GPIO voltage, its current path and the 3V3 rail during cold start and full-charge button presses. Do not treat an observed protection-diode clamp as proof of safe operation. Correct firmware button sensing does not resolve this hardware question. Battery telemetry is disabled, avoiding an additional raw-cell divider path into an unpowered input.

## 4. BS170 drivers at 3.3 V

The [onsemi BS170 datasheet](https://www.onsemi.com/download/data-sheet/pdf/mmbf170-d.pdf), page 2, specifies on-resistance at **10 V gate drive and 200 mA drain current**. Its 0.8–3 V threshold range is tested at only **1 mA**. Neither provides a guaranteed low on-resistance at ESP gate voltage. Its 500 mA absolute current limit is not a 3.3 V drive rating.

For the specified 100 mm strip, the primary Yuji typical figures imply about **60 mA per white channel and 40 mA per RGB channel at 12 V**. This is a source-derived expectation, not a measurement of the user's strip or MOSFETs. Verify the actual manufacturer, part marking and pin assignment, then measure each channel's drain-to-source voltage, current and temperature at its intended maximum output. QL is also a BS170, so its actual gate drive and resulting PNP base current need measurement.

Do not reuse the older assertion that a BS170 is generally good for 0.2–0.3 A at 3.3 V. The current guide retains the source circuit but makes no such guarantee.

## Qualify one prototype

Use a current-limited bench supply in place of the battery for initial circuit tests. Leave all untested modules disconnected and record the settings and readings for the actual parts.

| Stage | Test and record |
| --- | --- |
| Unpowered | Every listed jumper has continuity; no unintended solder bridges; component values, diode stripe and transistor roles match; switch opens on release |
| Latch alone | Feed protected-supply input OUT+/GND at intended cell-range voltages; check QP/QL nodes and VSW while pressing/releasing; record current |
| Latch plus ESP | Boost disconnected; observe startup GPIO and 3V3 behavior before and during boot, release-to-latch, repeated cold starts, short press and long-hold-release shutdown |
| Boost separately | Adjust and measure 12.0 V before attaching the strip; confirm terminal polarity |
| One channel at a time | Confirm channel identity, true off, current, drain voltage and temperature; begin at low brightness and increase gradually |
| Combined intended load | Record input current, QP voltage loss, 3V3 stability, boost output and component temperatures at the intended supply range and duty cycle; repeat after thermal stabilization |
| Off state | Verify shutdown and measure remaining current; check for power arriving through USB or a signal wire |
| Battery/charger separately | Identify cell specification and charger current setting; confirm protected outputs; initially charge with the light off |

Compare recorded values with the identified parts' operating limits, allowing margin for temperature and part variation. Resolve out-of-spec or unexplained results before approving the assembly for repetition. This review does not prescribe a replacement transistor, new resistor value or revised supply arrangement.

## Connections that must remain distinct

System GND is the protected charger's **OUT−**. The protection MOSFETs operate in the cell-negative path: connecting **BAT− directly to OUT− bypasses that switching**. The manufacturer's [DW01A application circuit](https://www.ic-fortune.com/upload/Download/DW01A-DS-12_EN.pdf) illustrates the intended separation. Confirm the actual TP4056 module includes that protection circuit and separately marked battery/output terminals.

Each LED driver's gate and drain are private to that channel. Share the source ground bus, not gate resistors or pulldowns. The remote button connects **OUT+ to BTN_N**, not GND. The +12 V strip common never connects to an ESP or latch terminal.

The copied printed PCB's `SW` footprint has a repeated-pad-number/contact-group conflict; R5 leaves it empty and uses a verified remote contact pair. A fresh perfboard has no such copper footprint, so do not recreate that conflict. Identify the actual switch's normally-open pair with a meter.

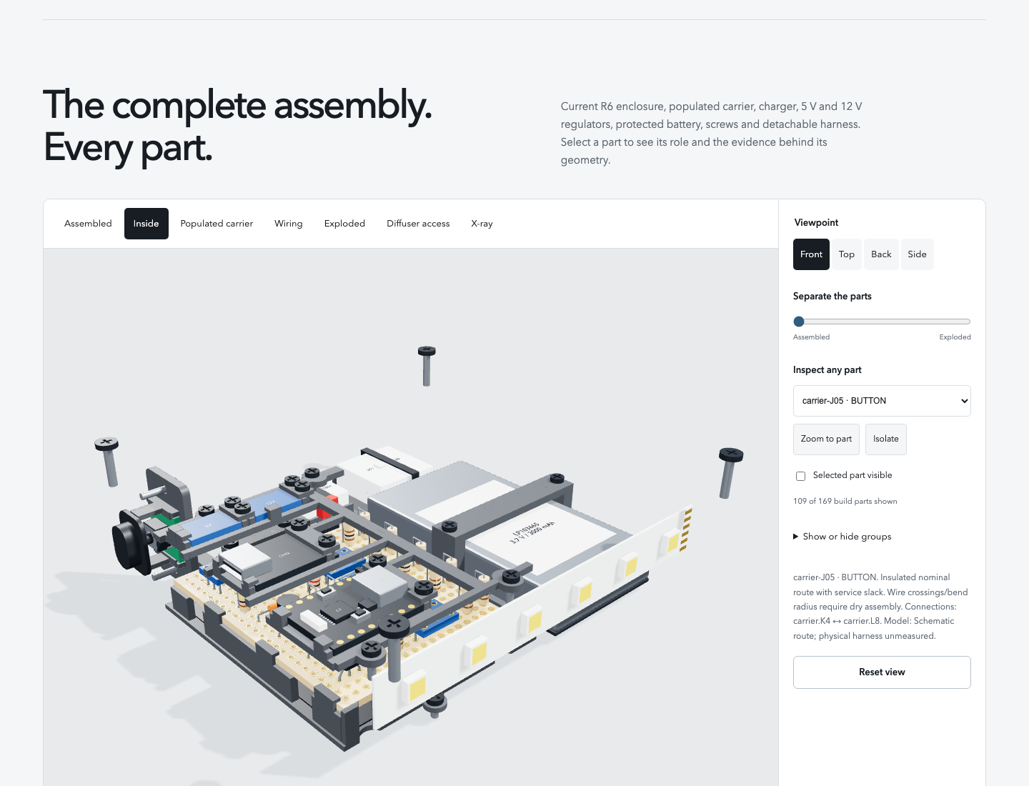
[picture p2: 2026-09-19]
preview/site/r6/internals.png

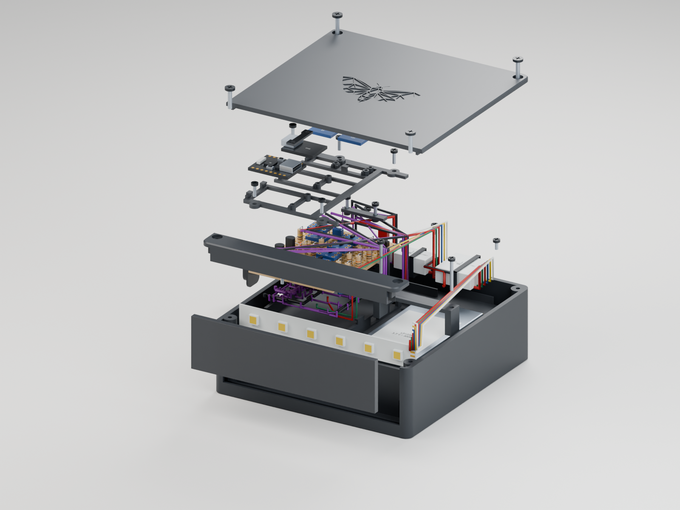
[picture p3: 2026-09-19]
preview/exploded.png

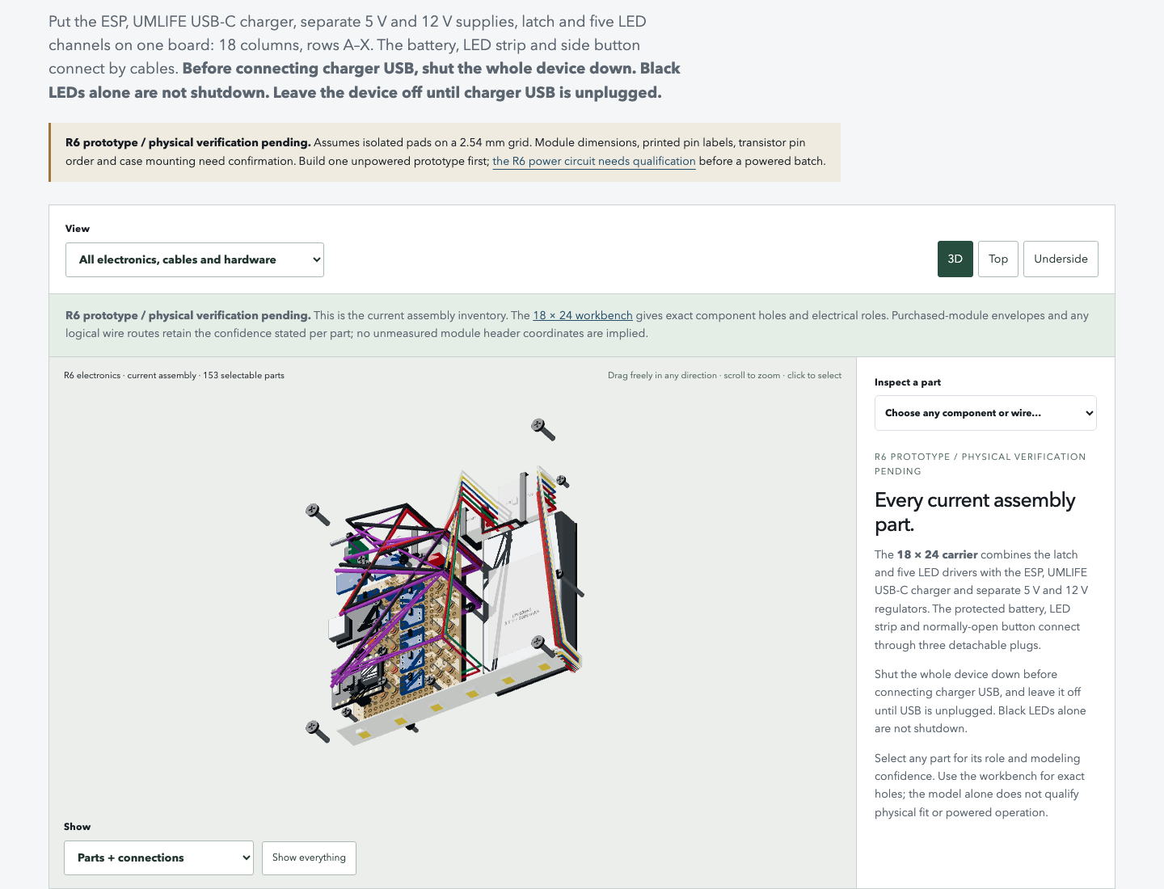
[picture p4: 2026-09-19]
preview/site/perfboard/system.png

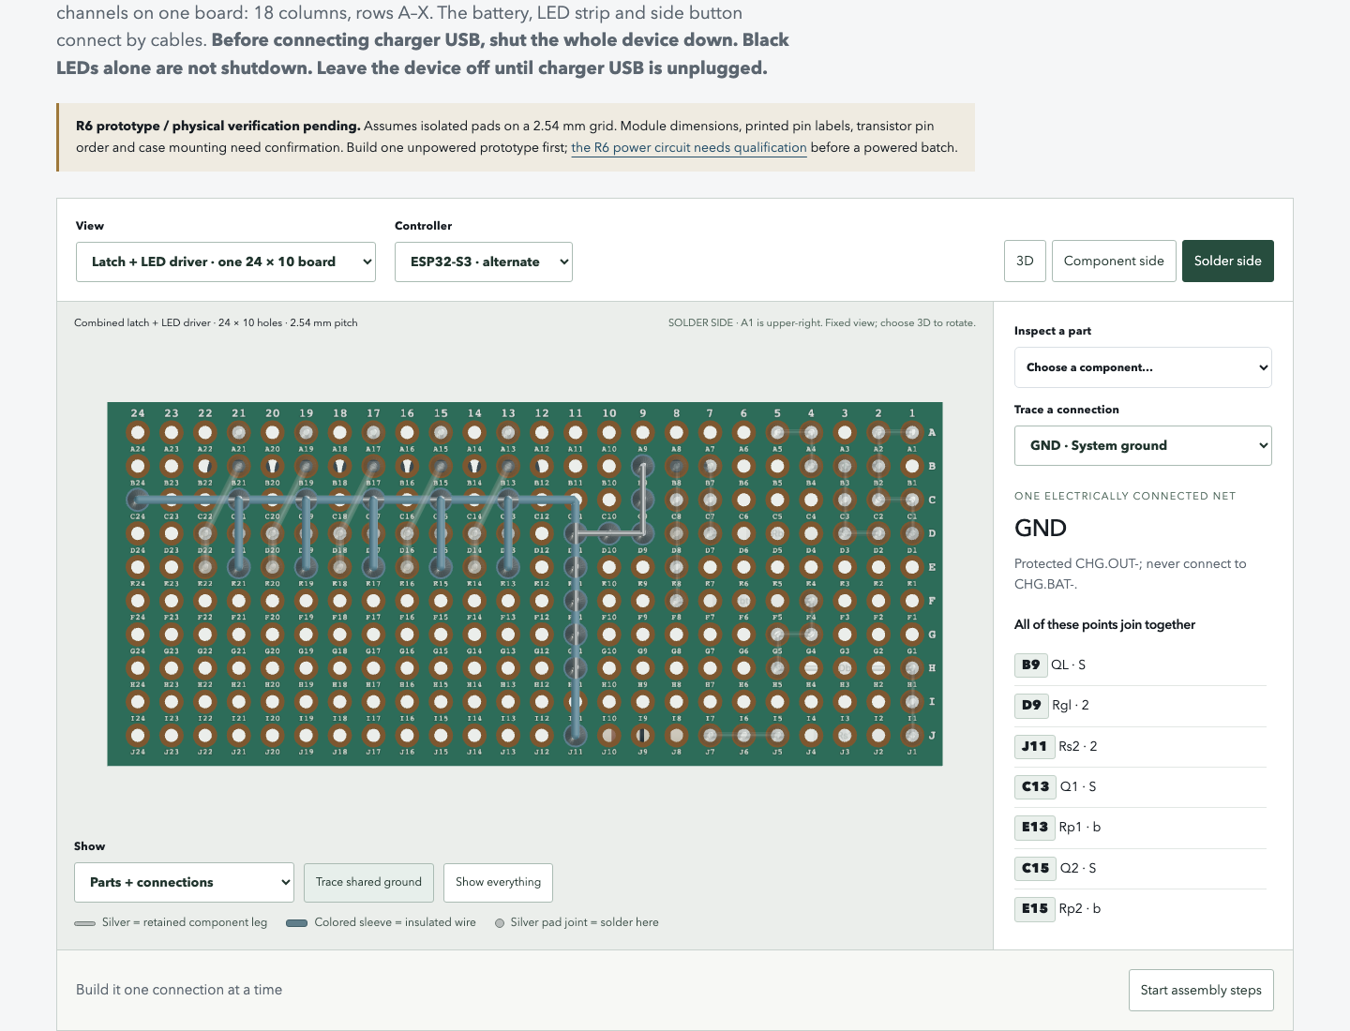
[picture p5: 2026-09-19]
preview/site/perfboard/combined-ground-bottom.png

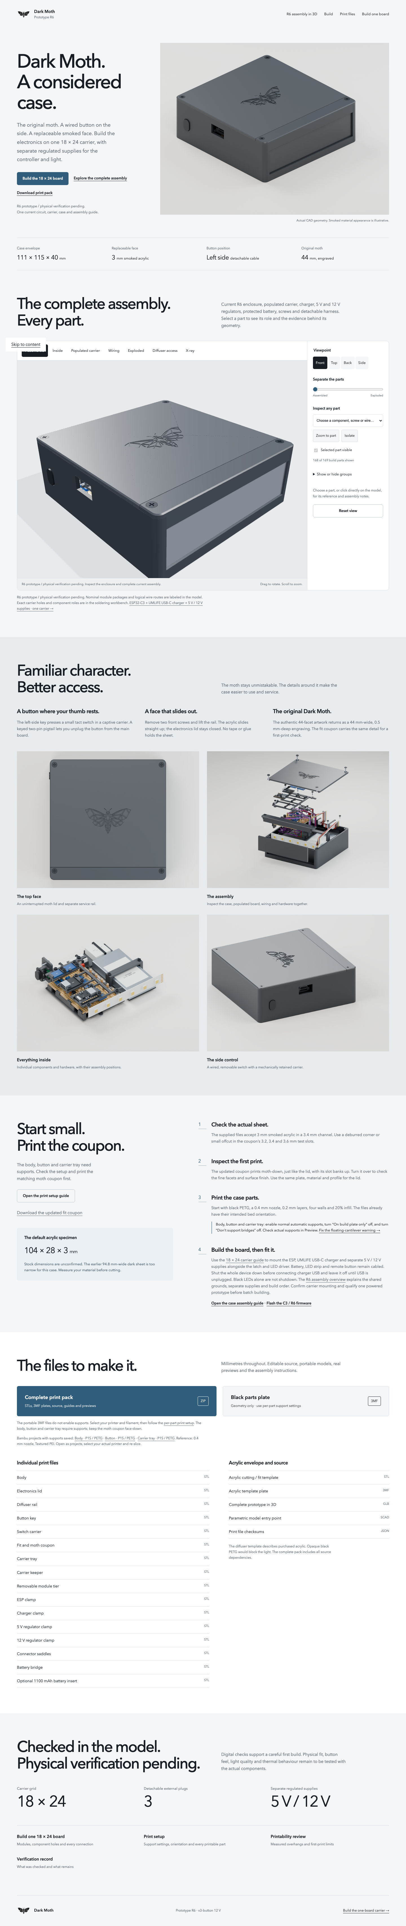
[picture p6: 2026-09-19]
preview/site/r6/desktop.png

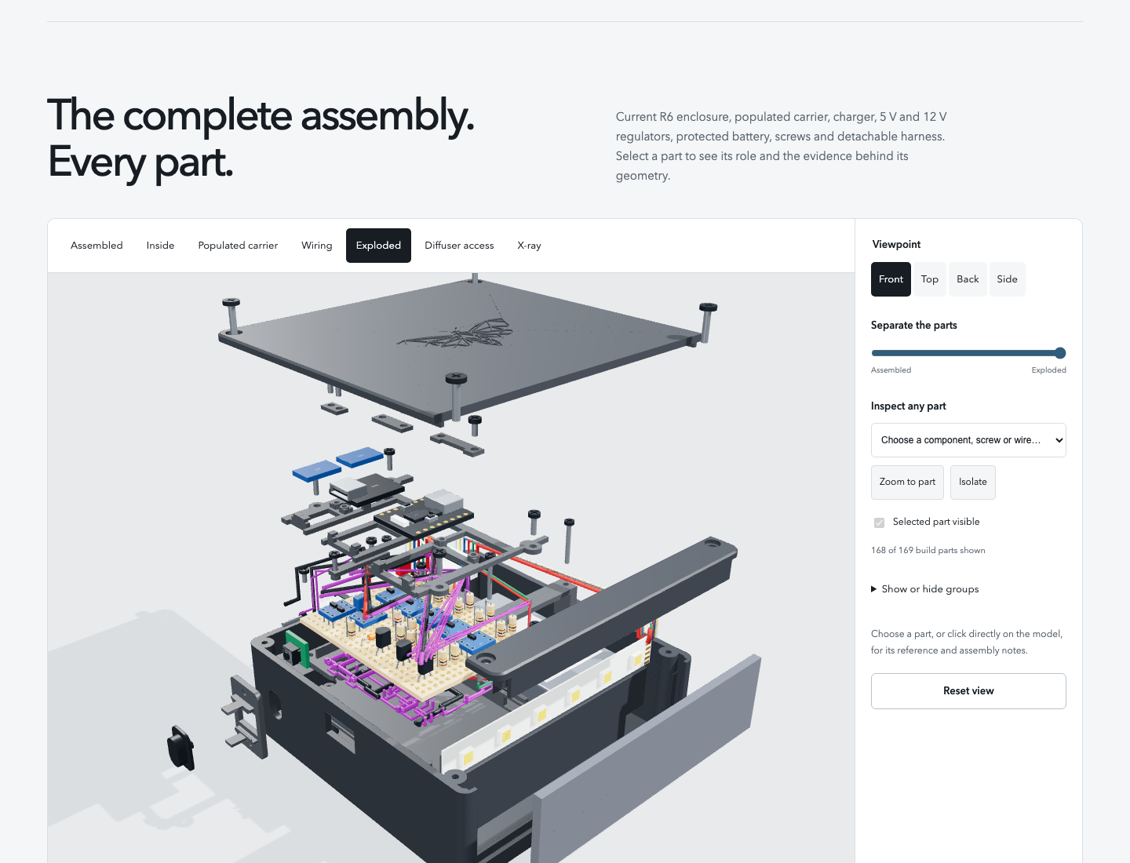
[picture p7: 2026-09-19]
preview/site/r6/exploded.png

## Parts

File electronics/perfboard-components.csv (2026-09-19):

board | ref | value | kind | role | hole | net | orientation_notes
latch | QP | SS8550 | TO92 | E | B2 | OUT+ | formed_role_leads; PNP high-side switch: E to protected OUT+, B to PB, C to VSW.; Identify actual manufacturer pin roles before insertion. The drawing does not specify flat-face left-to-right order. Form and insulate leads to the role-labelled holes; visual body entry points are schematic.; ; Do not trim E; retain at least 7.08 mm below the seated board for latch-L02. Use an insulated link if too short.; Do not trim B; retain at least 7.08 mm below the seated board for latch-L04. Use an insulated link if too short.; Do not trim C; retain at least 7.08 mm below the seated board for latch-L05. Use an insulated link if too short.
latch | QP | SS8550 | TO92 | B | B3 | PB | formed_role_leads; PNP high-side switch: E to protected OUT+, B to PB, C to VSW.; Identify actual manufacturer pin roles before insertion. The drawing does not specify flat-face left-to-right order. Form and insulate leads to the role-labelled holes; visual body entry points are schematic.; ; Do not trim E; retain at least 7.08 mm below the seated board for latch-L02. Use an insulated link if too short.; Do not trim B; retain at least 7.08 mm below the seated board for latch-L04. Use an insulated link if too short.; Do not trim C; retain at least 7.08 mm below the seated board for latch-L05. Use an insulated link if too short.
latch | QP | SS8550 | TO92 | C | B4 | VSW | formed_role_leads; PNP high-side switch: E to protected OUT+, B to PB, C to VSW.; Identify actual manufacturer pin roles before insertion. The drawing does not specify flat-face left-to-right order. Form and insulate leads to the role-labelled holes; visual body entry points are schematic.; ; Do not trim E; retain at least 7.08 mm below the seated board for latch-L02. Use an insulated link if too short.; Do not trim B; retain at least 7.08 mm below the seated board for latch-L04. Use an insulated link if too short.; Do not trim C; retain at least 7.08 mm below the seated board for latch-L05. Use an insulated link if too short.
latch | QL | BS170 | TO92 | D | B7 | LDRV | formed_role_leads; Latch MOSFET: D sinks LDRV, G is latch control, S is system GND.; Identify actual manufacturer pin roles before insertion. The drawing does not specify flat-face left-to-right order. Form and insulate leads to the role-labelled holes; visual body entry points are schematic.; ; Do not trim G; retain at least 7.08 mm below the seated board for latch-L07. Use an insulated link if too short.; Do not trim S; retain at least 7.08 mm below the seated board for latch-L09. Use an insulated link if too short.
latch | QL | BS170 | TO92 | G | B8 | GATE | formed_role_leads; Latch MOSFET: D sinks LDRV, G is latch control, S is system GND.; Identify actual manufacturer pin roles before insertion. The drawing does not specify flat-face left-to-right order. Form and insulate leads to the role-labelled holes; visual body entry points are schematic.; ; Do not trim G; retain at least 7.08 mm below the seated board for latch-L07. Use an insulated link if too short.; Do not trim S; retain at least 7.08 mm below the seated board for latch-L09. Use an insulated link if too short.
latch | QL | BS170 | TO92 | S | B9 | GND | formed_role_leads; Latch MOSFET: D sinks LDRV, G is latch control, S is system GND.; Identify actual manufacturer pin roles before insertion. The drawing does not specify flat-face left-to-right order. Form and insulate leads to the role-labelled holes; visual body entry points are schematic.; ; Do not trim G; retain at least 7.08 mm below the seated board for latch-L07. Use an insulated link if too short.; Do not trim S; retain at least 7.08 mm below the seated board for latch-L09. Use an insulated link if too short.
latch | Rbe | 100k | axial_resistor | 1 | D1 | OUT+ | upright; 100k pulls QP base toward its emitter to turn power off.; ; ; Do not trim 1; retain at least 9.62 mm below the seated board for latch-L01. Use an insulated link if too short.; Do not trim 2; retain at least 4.54 mm below the seated board for latch-L03. Use an insulated link if too short.
latch | Rbe | 100k | axial_resistor | 2 | D2 | PB | upright; 100k pulls QP base toward its emitter to turn power off.; ; ; Do not trim 1; retain at least 9.62 mm below the seated board for latch-L01. Use an insulated link if too short.; Do not trim 2; retain at least 4.54 mm below the seated board for latch-L03. Use an insulated link if too short.
latch | Rb | 330 | axial_resistor | 1 | D3 | PB | horizontal; 330 ohm limits QP base current between PB and LDRV.; ; ; Do not trim 2; retain at least 7.08 mm below the seated board for latch-L06. Use an insulated link if too short.
latch | Rb | 330 | axial_resistor | 2 | D7 | LDRV | horizontal; 330 ohm limits QP base current between PB and LDRV.; ; ; Do not trim 2; retain at least 7.08 mm below the seated board for latch-L06. Use an insulated link if too short.
latch | Rgl | 100k | axial_resistor | 1 | D8 | GATE | upright; 100k pulls the latch gate to GND when not driven.; ; ; Do not trim 2; retain at least 7.08 mm below the seated board for latch-L10. Use an insulated link if too short.
latch | Rgl | 100k | axial_resistor | 2 | D9 | GND | upright; 100k pulls the latch gate to GND when not driven.; ; ; Do not trim 2; retain at least 7.08 mm below the seated board for latch-L10. Use an insulated link if too short.
latch | Rbtn | 1k | axial_resistor | 1 | F8 | GATE | horizontal; 1k limits button-to-latch gate current.; ; ; Do not trim 1; retain at least 7.08 mm below the seated board for latch-L08. Use an insulated link if too short.; Do not trim 2; retain at least 9.62 mm below the seated board for latch-L11. Use an insulated link if too short.
latch | Rbtn | 1k | axial_resistor | 2 | F4 | BTN_DIO | horizontal; 1k limits button-to-latch gate current.; ; ; Do not trim 1; retain at least 7.08 mm below the seated board for latch-L08. Use an insulated link if too short.; Do not trim 2; retain at least 9.62 mm below the seated board for latch-L11. Use an insulated link if too short.
latch | Db | 1N4148 | axial_diode | K | H5 | BTN_DIO | horizontal; Black band = cathode K at H5 (BTN_DIO); unbanded anode A at H1 (BTN_N).; ; ; Do not trim A; retain at least 7.08 mm below the seated board for latch-L12. Use an insulated link if too short.
latch | Db | 1N4148 | axial_diode | A | H1 | BTN_N | horizontal; Black band = cathode K at H5 (BTN_DIO); unbanded anode A at H1 (BTN_N).; ; ; Do not trim A; retain at least 7.08 mm below the seated board for latch-L12. Use an insulated link if too short.
latch | Rs1 | 100k | axial_resistor | 1 | J1 | BTN_N | horizontal; 100k upper half of the analog button divider.; ; ; Do not trim 2; retain at least 7.08 mm below the seated board for latch-L13. Use an insulated link if too short.
latch | Rs1 | 100k | axial_resistor | 2 | J5 | SENSE | horizontal; 100k upper half of the analog button divider.; ; ; Do not trim 2; retain at least 7.08 mm below the seated board for latch-L13. Use an insulated link if too short.
latch | Rs2 | 100k | axial_resistor | 1 | J7 | SENSE | horizontal; 100k lower half of the analog button divider.
latch | Rs2 | 100k | axial_resistor | 2 | J11 | GND | horizontal; 100k lower half of the analog button divider.
driver | Q1 | BS170 | TO92 | D | A2 | LED_G | formed_role_leads; Low-side switch: drain to LED return, source to GND.; Identify actual manufacturer pin roles before insertion. The drawing does not specify flat-face left-to-right order. Form and insulate leads to the role-labelled holes; visual body entry points are schematic.
driver | Q1 | BS170 | TO92 | G | B2 | GATE_G | formed_role_leads; Low-side switch: drain to LED return, source to GND.; Identify actual manufacturer pin roles before insertion. The drawing does not specify flat-face left-to-right order. Form and insulate leads to the role-labelled holes; visual body entry points are schematic.
driver | Q1 | BS170 | TO92 | S | C2 | GND | formed_role_leads; Low-side switch: drain to LED return, source to GND.; Identify actual manufacturer pin roles before insertion. The drawing does not specify flat-face left-to-right order. Form and insulate leads to the role-labelled holes; visual body entry points are schematic.
driver | Rg1 | 100 | axial_resistor | a | D2 | PWM_G | upright; 100 ohm gate series resistor. Body at a; insulated return leg at b. Either electrical direction.
driver | Rg1 | 100 | axial_resistor | b | D3 | GATE_G | upright; 100 ohm gate series resistor. Body at a; insulated return leg at b. Either electrical direction.
driver | Rp1 | 10k | axial_resistor | a | E3 | GATE_G | upright; 10k gate pulldown. Body at a; insulated return leg at b. Either electrical direction.
driver | Rp1 | 10k | axial_resistor | b | E2 | GND | upright; 10k gate pulldown. Body at a; insulated return leg at b. Either electrical direction.
driver | Q2 | BS170 | TO92 | D | A4 | LED_R | formed_role_leads; Low-side switch: drain to LED return, source to GND.; Identify actual manufacturer pin roles before insertion. The drawing does not specify flat-face left-to-right order. Form and insulate leads to the role-labelled holes; visual body entry points are schematic.
driver | Q2 | BS170 | TO92 | G | B4 | GATE_R | formed_role_leads; Low-side switch: drain to LED return, source to GND.; Identify actual manufacturer pin roles before insertion. The drawing does not specify flat-face left-to-right order. Form and insulate leads to the role-labelled holes; visual body entry points are schematic.
driver | Q2 | BS170 | TO92 | S | C4 | GND | formed_role_leads; Low-side switch: drain to LED return, source to GND.; Identify actual manufacturer pin roles before insertion. The drawing does not specify flat-face left-to-right order. Form and insulate leads to the role-labelled holes; visual body entry points are schematic.
driver | Rg2 | 100 | axial_resistor | a | D4 | PWM_R | upright; 100 ohm gate series resistor. Body at a; insulated return leg at b. Either electrical direction.
driver | Rg2 | 100 | axial_resistor | b | D5 | GATE_R | upright; 100 ohm gate series resistor. Body at a; insulated return leg at b. Either electrical direction.
driver | Rp2 | 10k | axial_resistor | a | E5 | GATE_R | upright; 10k gate pulldown. Body at a; insulated return leg at b. Either electrical direction.
driver | Rp2 | 10k | axial_resistor | b | E4 | GND | upright; 10k gate pulldown. Body at a; insulated return leg at b. Either electrical direction.
driver | Q3 | BS170 | TO92 | D | A6 | LED_B | formed_role_leads; Low-side switch: drain to LED return, source to GND.; Identify actual manufacturer pin roles before insertion. The drawing does not specify flat-face left-to-right order. Form and insulate leads to the role-labelled holes; visual body entry points are schematic.
driver | Q3 | BS170 | TO92 | G | B6 | GATE_B | formed_role_leads; Low-side switch: drain to LED return, source to GND.; Identify actual manufacturer pin roles before insertion. The drawing does not specify flat-face left-to-right order. Form and insulate leads to the role-labelled holes; visual body entry points are schematic.
driver | Q3 | BS170 | TO92 | S | C6 | GND | formed_role_leads; Low-side switch: drain to LED return, source to GND.; Identify actual manufacturer pin roles before insertion. The drawing does not specify flat-face left-to-right order. Form and insulate leads to the role-labelled holes; visual body entry points are schematic.
driver | Rg3 | 100 | axial_resistor | a | D6 | PWM_B | upright; 100 ohm gate series resistor. Body at a; insulated return leg at b. Either electrical direction.
driver | Rg3 | 100 | axial_resistor | b | D7 | GATE_B | upright; 100 ohm gate series resistor. Body at a; insulated return leg at b. Either electrical direction.
driver | Rp3 | 10k | axial_resistor | a | E7 | GATE_B | upright; 10k gate pulldown. Body at a; insulated return leg at b. Either electrical direction.
driver | Rp3 | 10k | axial_resistor | b | E6 | GND | upright; 10k gate pulldown. Body at a; insulated return leg at b. Either electrical direction.
driver | Q4 | BS170 | TO92 | D | A8 | LED_WW | formed_role_leads; Low-side switch: drain to LED return, source to GND.; Identify actual manufacturer pin roles before insertion. The drawing does not specify flat-face left-to-right order. Form and insulate leads to the role-labelled holes; visual body entry points are schematic.
driver | Q4 | BS170 | TO92 | G | B8 | GATE_WW | formed_role_leads; Low-side switch: drain to LED return, source to GND.; Identify actual manufacturer pin roles before insertion. The drawing does not specify flat-face left-to-right order. Form and insulate leads to the role-labelled holes; visual body entry points are schematic.
driver | Q4 | BS170 | TO92 | S | C8 | GND | formed_role_leads; Low-side switch: drain to LED return, source to GND.; Identify actual manufacturer pin roles before insertion. The drawing does not specify flat-face left-to-right order. Form and insulate leads to the role-labelled holes; visual body entry points are schematic.
driver | Rg4 | 100 | axial_resistor | a | D8 | PWM_WW | upright; 100 ohm gate series resistor. Body at a; insulated return leg at b. Either electrical direction.
driver | Rg4 | 100 | axial_resistor | b | D9 | GATE_WW | upright; 100 ohm gate series resistor. Body at a; insulated return leg at b. Either electrical direction.
driver | Rp4 | 10k | axial_resistor | a | E9 | GATE_WW | upright; 10k gate pulldown. Body at a; insulated return leg at b. Either electrical direction.
driver | Rp4 | 10k | axial_resistor | b | E8 | GND | upright; 10k gate pulldown. Body at a; insulated return leg at b. Either electrical direction.
driver | Q5 | BS170 | TO92 | D | A10 | LED_CW | formed_role_leads; Low-side switch: drain to LED return, source to GND.; Identify actual manufacturer pin roles before insertion. The drawing does not specify flat-face left-to-right order. Form and insulate leads to the role-labelled holes; visual body entry points are schematic.
driver | Q5 | BS170 | TO92 | G | B10 | GATE_CW | formed_role_leads; Low-side switch: drain to LED return, source to GND.; Identify actual manufacturer pin roles before insertion. The drawing does not specify flat-face left-to-right order. Form and insulate leads to the role-labelled holes; visual body entry points are schematic.
driver | Q5 | BS170 | TO92 | S | C10 | GND | formed_role_leads; Low-side switch: drain to LED return, source to GND.; Identify actual manufacturer pin roles before insertion. The drawing does not specify flat-face left-to-right order. Form and insulate leads to the role-labelled holes; visual body entry points are schematic.
driver | Rg5 | 100 | axial_resistor | a | D10 | PWM_CW | upright; 100 ohm gate series resistor. Body at a; insulated return leg at b. Either electrical direction.
driver | Rg5 | 100 | axial_resistor | b | D11 | GATE_CW | upright; 100 ohm gate series resistor. Body at a; insulated return leg at b. Either electrical direction.
driver | Rp5 | 10k | axial_resistor | a | E11 | GATE_CW | upright; 10k gate pulldown. Body at a; insulated return leg at b. Either electrical direction.
driver | Rp5 | 10k | axial_resistor | b | E10 | GND | upright; 10k gate pulldown. Body at a; insulated return leg at b. Either electrical direction.
combined | QP | SS8550 | TO92 | E | B2 | OUT+ | formed_role_leads; PNP high-side switch: E to protected OUT+, B to PB, C to VSW.; Identify actual manufacturer pin roles before insertion. The drawing does not specify flat-face left-to-right order. Form and insulate leads to the role-labelled holes; visual body entry points are schematic.; ; Do not trim E; retain at least 7.08 mm below the seated board for combined-L02. Use an insulated link if too short.; Do not trim B; retain at least 7.08 mm below the seated board for combined-L04. Use an insulated link if too short.; Do not trim C; retain at least 7.08 mm below the seated board for combined-L05. Use an insulated link if too short.
combined | QP | SS8550 | TO92 | B | B3 | PB | formed_role_leads; PNP high-side switch: E to protected OUT+, B to PB, C to VSW.; Identify actual manufacturer pin roles before insertion. The drawing does not specify flat-face left-to-right order. Form and insulate leads to the role-labelled holes; visual body entry points are schematic.; ; Do not trim E; retain at least 7.08 mm below the seated board for combined-L02. Use an insulated link if too short.; Do not trim B; retain at least 7.08 mm below the seated board for combined-L04. Use an insulated link if too short.; Do not trim C; retain at least 7.08 mm below the seated board for combined-L05. Use an insulated link if too short.
combined | QP | SS8550 | TO92 | C | B4 | VSW | formed_role_leads; PNP high-side switch: E to protected OUT+, B to PB, C to VSW.; Identify actual manufacturer pin roles before insertion. The drawing does not specify flat-face left-to-right order. Form and insulate leads to the role-labelled holes; visual body entry points are schematic.; ; Do not trim E; retain at least 7.08 mm below the seated board for combined-L02. Use an insulated link if too short.; Do not trim B; retain at least 7.08 mm below the seated board for combined-L04. Use an insulated link if too short.; Do not trim C; retain at least 7.08 mm below the seated board for combined-L05. Use an insulated link if too short.
combined | QL | BS170 | TO92 | D | B7 | LDRV | formed_role_leads; Latch MOSFET: D sinks LDRV, G is latch control, S is system GND.; Identify actual manufacturer pin roles before insertion. The drawing does not specify flat-face left-to-right order. Form and insulate leads to the role-labelled holes; visual body entry points are schematic.; ; Do not trim G; retain at least 7.08 mm below the seated board for combined-L07. Use an insulated link if too short.; Do not trim S; retain at least 7.08 mm below the seated board for combined-L09. Use an insulated link if too short.
combined | QL | BS170 | TO92 | G | B8 | GATE | formed_role_leads; Latch MOSFET: D sinks LDRV, G is latch control, S is system GND.; Identify actual manufacturer pin roles before insertion. The drawing does not specify flat-face left-to-right order. Form and insulate leads to the role-labelled holes; visual body entry points are schematic.; ; Do not trim G; retain at least 7.08 mm below the seated board for combined-L07. Use an insulated link if too short.; Do not trim S; retain at least 7.08 mm below the seated board for combined-L09. Use an insulated link if too short.
combined | QL | BS170 | TO92 | S | B9 | GND | formed_role_leads; Latch MOSFET: D sinks LDRV, G is latch control, S is system GND.; Identify actual manufacturer pin roles before insertion. The drawing does not specify flat-face left-to-right order. Form and insulate leads to the role-labelled holes; visual body entry points are schematic.; ; Do not trim G; retain at least 7.08 mm below the seated board for combined-L07. Use an insulated link if too short.; Do not trim S; retain at least 7.08 mm below the seated board for combined-L09. Use an insulated link if too short.
combined | Rbe | 100k | axial_resistor | 1 | D1 | OUT+ | upright; 100k pulls QP base toward its emitter to turn power off.; ; ; Do not trim 1; retain at least 9.62 mm below the seated board for combined-L01. Use an insulated link if too short.; Do not trim 2; retain at least 4.54 mm below the seated board for combined-L03. Use an insulated link if too short.
combined | Rbe | 100k | axial_resistor | 2 | D2 | PB | upright; 100k pulls QP base toward its emitter to turn power off.; ; ; Do not trim 1; retain at least 9.62 mm below the seated board for combined-L01. Use an insulated link if too short.; Do not trim 2; retain at least 4.54 mm below the seated board for combined-L03. Use an insulated link if too short.
combined | Rb | 330 | axial_resistor | 1 | D3 | PB | horizontal; 330 ohm limits QP base current between PB and LDRV.; ; ; Do not trim 2; retain at least 7.08 mm below the seated board for combined-L06. Use an insulated link if too short.
combined | Rb | 330 | axial_resistor | 2 | D7 | LDRV | horizontal; 330 ohm limits QP base current between PB and LDRV.; ; ; Do not trim 2; retain at least 7.08 mm below the seated board for combined-L06. Use an insulated link if too short.
combined | Rgl | 100k | axial_resistor | 1 | D8 | GATE | upright; 100k pulls the latch gate to GND when not driven.; ; ; Do not trim 2; retain at least 7.08 mm below the seated board for combined-L10. Use an insulated link if too short.
combined | Rgl | 100k | axial_resistor | 2 | D9 | GND | upright; 100k pulls the latch gate to GND when not driven.; ; ; Do not trim 2; retain at least 7.08 mm below the seated board for combined-L10. Use an insulated link if too short.
combined | Rbtn | 1k | axial_resistor | 1 | F8 | GATE | horizontal; 1k limits button-to-latch gate current.; ; ; Do not trim 1; retain at least 7.08 mm below the seated board for combined-L08. Use an insulated link if too short.; Do not trim 2; retain at least 9.62 mm below the seated board for combined-L11. Use an insulated link if too short.
combined | Rbtn | 1k | axial_resistor | 2 | F4 | BTN_DIO | horizontal; 1k limits button-to-latch gate current.; ; ; Do not trim 1; retain at least 7.08 mm below the seated board for combined-L08. Use an insulated link if too short.; Do not trim 2; retain at least 9.62 mm below the seated board for combined-L11. Use an insulated link if too short.
combined | Db | 1N4148 | axial_diode | K | H5 | BTN_DIO | horizontal; Black band = cathode K at H5 (BTN_DIO); unbanded anode A at H1 (BTN_N).; ; ; Do not trim A; retain at least 7.08 mm below the seated board for combined-L12. Use an insulated link if too short.
combined | Db | 1N4148 | axial_diode | A | H1 | BTN_N | horizontal; Black band = cathode K at H5 (BTN_DIO); unbanded anode A at H1 (BTN_N).; ; ; Do not trim A; retain at least 7.08 mm below the seated board for combined-L12. Use an insulated link if too short.
combined | Rs1 | 100k | axial_resistor | 1 | J1 | BTN_N | horizontal; 100k upper half of the analog button divider.; ; ; Do not trim 2; retain at least 7.08 mm below the seated board for combined-L13. Use an insulated link if too short.
combined | Rs1 | 100k | axial_resistor | 2 | J5 | SENSE | horizontal; 100k upper half of the analog button divider.; ; ; Do not trim 2; retain at least 7.08 mm below the seated board for combined-L13. Use an insulated link if too short.
combined | Rs2 | 100k | axial_resistor | 1 | J7 | SENSE | horizontal; 100k lower half of the analog button divider.
combined | Rs2 | 100k | axial_resistor | 2 | J11 | GND | horizontal; 100k lower half of the analog button divider.
combined | Q1 | BS170 | TO92 | D | A13 | LED_G | formed_role_leads; Low-side switch: drain to LED return, source to GND.; Identify actual manufacturer pin roles before insertion. The drawing does not specify flat-face left-to-right order. Form and insulate leads to the role-labelled holes; visual body entry points are schematic.
combined | Q1 | BS170 | TO92 | G | B13 | GATE_G | formed_role_leads; Low-side switch: drain to LED return, source to GND.; Identify actual manufacturer pin roles before insertion. The drawing does not specify flat-face left-to-right order. Form and insulate leads to the role-labelled holes; visual body entry points are schematic.
combined | Q1 | BS170 | TO92 | S | C13 | GND | formed_role_leads; Low-side switch: drain to LED return, source to GND.; Identify actual manufacturer pin roles before insertion. The drawing does not specify flat-face left-to-right order. Form and insulate leads to the role-labelled holes; visual body entry points are schematic.
combined | Rg1 | 100 | axial_resistor | a | D13 | PWM_G | upright; 100 ohm gate series resistor. Body at a; insulated return leg at b. Either electrical direction.
combined | Rg1 | 100 | axial_resistor | b | D14 | GATE_G | upright; 100 ohm gate series resistor. Body at a; insulated return leg at b. Either electrical direction.
combined | Rp1 | 10k | axial_resistor | a | E14 | GATE_G | upright; 10k gate pulldown. Body at a; insulated return leg at b. Either electrical direction.
combined | Rp1 | 10k | axial_resistor | b | E13 | GND | upright; 10k gate pulldown. Body at a; insulated return leg at b. Either electrical direction.
combined | Q2 | BS170 | TO92 | D | A15 | LED_R | formed_role_leads; Low-side switch: drain to LED return, source to GND.; Identify actual manufacturer pin roles before insertion. The drawing does not specify flat-face left-to-right order. Form and insulate leads to the role-labelled holes; visual body entry points are schematic.
combined | Q2 | BS170 | TO92 | G | B15 | GATE_R | formed_role_leads; Low-side switch: drain to LED return, source to GND.; Identify actual manufacturer pin roles before insertion. The drawing does not specify flat-face left-to-right order. Form and insulate leads to the role-labelled holes; visual body entry points are schematic.
combined | Q2 | BS170 | TO92 | S | C15 | GND | formed_role_leads; Low-side switch: drain to LED return, source to GND.; Identify actual manufacturer pin roles before insertion. The drawing does not specify flat-face left-to-right order. Form and insulate leads to the role-labelled holes; visual body entry points are schematic.
combined | Rg2 | 100 | axial_resistor | a | D15 | PWM_R | upright; 100 ohm gate series resistor. Body at a; insulated return leg at b. Either electrical direction.
combined | Rg2 | 100 | axial_resistor | b | D16 | GATE_R | upright; 100 ohm gate series resistor. Body at a; insulated return leg at b. Either electrical direction.
combined | Rp2 | 10k | axial_resistor | a | E16 | GATE_R | upright; 10k gate pulldown. Body at a; insulated return leg at b. Either electrical direction.
combined | Rp2 | 10k | axial_resistor | b | E15 | GND | upright; 10k gate pulldown. Body at a; insulated return leg at b. Either electrical direction.
combined | Q3 | BS170 | TO92 | D | A17 | LED_B | formed_role_leads; Low-side switch: drain to LED return, source to GND.; Identify actual manufacturer pin roles before insertion. The drawing does not specify flat-face left-to-right order. Form and insulate leads to the role-labelled holes; visual body entry points are schematic.
combined | Q3 | BS170 | TO92 | G | B17 | GATE_B | formed_role_leads; Low-side switch: drain to LED return, source to GND.; Identify actual manufacturer pin roles before insertion. The drawing does not specify flat-face left-to-right order. Form and insulate leads to the role-labelled holes; visual body entry points are schematic.
combined | Q3 | BS170 | TO92 | S | C17 | GND | formed_role_leads; Low-side switch: drain to LED return, source to GND.; Identify actual manufacturer pin roles before insertion. The drawing does not specify flat-face left-to-right order. Form and insulate leads to the role-labelled holes; visual body entry points are schematic.
combined | Rg3 | 100 | axial_resistor | a | D17 | PWM_B | upright; 100 ohm gate series resistor. Body at a; insulated return leg at b. Either electrical direction.
combined | Rg3 | 100 | axial_resistor | b | D18 | GATE_B | upright; 100 ohm gate series resistor. Body at a; insulated return leg at b. Either electrical direction.
combined | Rp3 | 10k | axial_resistor | a | E18 | GATE_B | upright; 10k gate pulldown. Body at a; insulated return leg at b. Either electrical direction.
combined | Rp3 | 10k | axial_resistor | b | E17 | GND | upright; 10k gate pulldown. Body at a; insulated return leg at b. Either electrical direction.
combined | Q4 | BS170 | TO92 | D | A19 | LED_WW | formed_role_leads; Low-side switch: drain to LED return, source to GND.; Identify actual manufacturer pin roles before insertion. The drawing does not specify flat-face left-to-right order. Form and insulate leads to the role-labelled holes; visual body entry points are schematic.
combined | Q4 | BS170 | TO92 | G | B19 | GATE_WW | formed_role_leads; Low-side switch: drain to LED return, source to GND.; Identify actual manufacturer pin roles before insertion. The drawing does not specify flat-face left-to-right order. Form and insulate leads to the role-labelled holes; visual body entry points are schematic.
combined | Q4 | BS170 | TO92 | S | C19 | GND | formed_role_leads; Low-side switch: drain to LED return, source to GND.; Identify actual manufacturer pin roles before insertion. The drawing does not specify flat-face left-to-right order. Form and insulate leads to the role-labelled holes; visual body entry points are schematic.
combined | Rg4 | 100 | axial_resistor | a | D19 | PWM_WW | upright; 100 ohm gate series resistor. Body at a; insulated return leg at b. Either electrical direction.
combined | Rg4 | 100 | axial_resistor | b | D20 | GATE_WW | upright; 100 ohm gate series resistor. Body at a; insulated return leg at b. Either electrical direction.
combined | Rp4 | 10k | axial_resistor | a | E20 | GATE_WW | upright; 10k gate pulldown. Body at a; insulated return leg at b. Either electrical direction.
combined | Rp4 | 10k | axial_resistor | b | E19 | GND | upright; 10k gate pulldown. Body at a; insulated return leg at b. Either electrical direction.
combined | Q5 | BS170 | TO92 | D | A21 | LED_CW | formed_role_leads; Low-side switch: drain to LED return, source to GND.; Identify actual manufacturer pin roles before insertion. The drawing does not specify flat-face left-to-right order. Form and insulate leads to the role-labelled holes; visual body entry points are schematic.
combined | Q5 | BS170 | TO92 | G | B21 | GATE_CW | formed_role_leads; Low-side switch: drain to LED return, source to GND.; Identify actual manufacturer pin roles before insertion. The drawing does not specify flat-face left-to-right order. Form and insulate leads to the role-labelled holes; visual body entry points are schematic.
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

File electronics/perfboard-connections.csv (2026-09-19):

board | kind | id | net | from | to_C3 | to_S3 | side | notes | conductor_id | joined_holes | source_pin | retained_lead_mm
latch | retained component leg | latch-L01 | OUT+ | latch.D1 | latch.B2 | latch.B2 | bottom | Reuse Rbe.1; retain at least 9.62 mm below the seated board. Bend and solder at ALL named holes: D1 → C1 → C2 → B2. Trim only beyond the final joint after soldering. If too short or stiff, use an insulated link. Crossings do not join unless listed. | latch-L01 | D1 → C1 → C2 → B2 | Rbe.1 | 9.62
latch | retained component leg | latch-L02 | OUT+ | latch.B2 | latch.A1 | latch.A1 | bottom | Reuse QP.E; retain at least 7.08 mm below the seated board. Bend and solder at ALL named holes: B2 → A2 → A1. Trim only beyond the final joint after soldering. If too short or stiff, use an insulated link. Crossings do not join unless listed. | latch-L02 | B2 → A2 → A1 | QP.E | 7.08
latch | retained component leg | latch-L03 | PB | latch.D2 | latch.D3 | latch.D3 | bottom | Reuse Rbe.2; retain at least 4.54 mm below the seated board. Bend and solder at ALL named holes: D2 → D3. Trim only beyond the final joint after soldering. If too short or stiff, use an insulated link. Crossings do not join unless listed. | latch-L03 | D2 → D3 | Rbe.2 | 4.54
latch | retained component leg | latch-L04 | PB | latch.B3 | latch.D3 | latch.D3 | bottom | Reuse QP.B; retain at least 7.08 mm below the seated board. Bend and solder at ALL named holes: B3 → C3 → D3. Trim only beyond the final joint after soldering. If too short or stiff, use an insulated link. Crossings do not join unless listed. | latch-L04 | B3 → C3 → D3 | QP.B | 7.08
latch | retained component leg | latch-L05 | VSW | latch.B4 | latch.A5 | latch.A5 | bottom | Reuse QP.C; retain at least 7.08 mm below the seated board. Bend and solder at ALL named holes: B4 → A4 → A5. Trim only beyond the final joint after soldering. If too short or stiff, use an insulated link. Crossings do not join unless listed. | latch-L05 | B4 → A4 → A5 | QP.C | 7.08
latch | retained component leg | latch-L06 | LDRV | latch.D7 | latch.B7 | latch.B7 | bottom | Reuse Rb.2; retain at least 7.08 mm below the seated board. Bend and solder at ALL named holes: D7 → C7 → B7. Trim only beyond the final joint after soldering. If too short or stiff, use an insulated link. Crossings do not join unless listed. | latch-L06 | D7 → C7 → B7 | Rb.2 | 7.08
latch | retained component leg | latch-L07 | GATE | latch.B8 | latch.D8 | latch.D8 | bottom | Reuse QL.G; retain at least 7.08 mm below the seated board. Bend and solder at ALL named holes: B8 → C8 → D8. Trim only beyond the final joint after soldering. If too short or stiff, use an insulated link. Crossings do not join unless listed. | latch-L07 | B8 → C8 → D8 | QL.G | 7.08
latch | retained component leg | latch-L08 | GATE | latch.F8 | latch.D8 | latch.D8 | bottom | Reuse Rbtn.1; retain at least 7.08 mm below the seated board. Bend and solder at ALL named holes: F8 → E8 → D8. Trim only beyond the final joint after soldering. If too short or stiff, use an insulated link. Crossings do not join unless listed. | latch-L08 | F8 → E8 → D8 | Rbtn.1 | 7.08
latch | retained component leg | latch-L09 | GND | latch.B9 | latch.D9 | latch.D9 | bottom | Reuse QL.S; retain at least 7.08 mm below the seated board. Bend and solder at ALL named holes: B9 → C9 → D9. Trim only beyond the final joint after soldering. If too short or stiff, use an insulated link. Crossings do not join unless listed. | latch-L09 | B9 → C9 → D9 | QL.S | 7.08
latch | retained component leg | latch-L10 | GND | latch.D9 | latch.D11 | latch.D11 | bottom | Reuse Rgl.2; retain at least 7.08 mm below the seated board. Bend and solder at ALL named holes: D9 → D10 → D11. Trim only beyond the final joint after soldering. If too short or stiff, use an insulated link. Crossings do not join unless listed. | latch-L10 | D9 → D10 → D11 | Rgl.2 | 7.08
latch | retained component leg | latch-L11 | BTN_DIO | latch.F4 | latch.H5 | latch.H5 | bottom | Reuse Rbtn.2; retain at least 9.62 mm below the seated board. Bend and solder at ALL named holes: F4 → G4 → G5 → H5. Trim only beyond the final joint after soldering. If too short or stiff, use an insulated link. Crossings do not join unless listed. | latch-L11 | F4 → G4 → G5 → H5 | Rbtn.2 | 9.62
latch | retained component leg | latch-L12 | BTN_N | latch.H1 | latch.J1 | latch.J1 | bottom | Reuse Db.A; retain at least 7.08 mm below the seated board. Bend and solder at ALL named holes: H1 → I1 → J1. Trim only beyond the final joint after soldering. If too short or stiff, use an insulated link. Crossings do not join unless listed. | latch-L12 | H1 → I1 → J1 | Db.A | 7.08
latch | retained component leg | latch-L13 | SENSE | latch.J5 | latch.J7 | latch.J7 | bottom | Reuse Rs1.2; retain at least 7.08 mm below the seated board. Bend and solder at ALL named holes: J5 → J6 → J7. Trim only beyond the final joint after soldering. If too short or stiff, use an insulated link. Crossings do not join unless listed. | latch-L13 | J5 → J6 → J7 | Rs1.2 | 7.08
latch | ground bus | latch-ground | GND | latch.J11 | latch.D11 | latch.D11 | bottom | One dedicated ground conductor; solder windows/taps at J11 → I11 → H11 → G11 → F11 → E11 → D11. Keep spans insulated and size the conductor for measured return current; do not use a resistor leg as the load-current backbone. | latch-ground | J11 → I11 → H11 → G11 → F11 → E11 → D11
latch | terminal | CHARGER_POS | OUT+ | latch.A1 | CHG.OUT+ | CHG.OUT+ | external harness | Lap-solder at this joint; one inserted component leg per hole. Strain-relieve the insulated harness wire.; insulate and strain-relieve the wire. Reciprocal board-terminal rows describe the same cable, not a second cable.
latch | terminal | BUTTON_PLUS | OUT+ | latch.A2 | BUTTON_PLUG.OUT+ → SW_REMOTE.contact_A | BUTTON_PLUG.OUT+ → SW_REMOTE.contact_A | external harness | Lap-solder at this joint; one inserted component leg per hole. Strain-relieve the insulated harness wire.; insulate and strain-relieve the wire. Reciprocal board-terminal rows describe the same cable, not a second cable.
latch | terminal | BOOST_POS | VSW | latch.A4 | BOOST.VIN+ | BOOST.VIN+ | external harness | Lap-solder at this joint; one inserted component leg per hole. Strain-relieve the insulated harness wire.; insulate and strain-relieve the wire. Reciprocal board-terminal rows describe the same cable, not a second cable.
latch | terminal | ESP_POWER | VSW | latch.A5 | ESP.5V / VIN | ESP.5V / VIN | external harness | Lap-solder at this joint; one inserted component leg per hole. Strain-relieve the insulated harness wire.; insulate and strain-relieve the wire. Reciprocal board-terminal rows describe the same cable, not a second cable.
latch | terminal | BUTTON_RETURN | BTN_N | latch.H1 | BUTTON_PLUG.BTN_N → SW_REMOTE.contact_B | BUTTON_PLUG.BTN_N → SW_REMOTE.contact_B | external harness | Lap-solder at this joint; one inserted component leg per hole. Strain-relieve the insulated harness wire.; insulate and strain-relieve the wire. Reciprocal board-terminal rows describe the same cable, not a second cable.
latch | terminal | CHARGER_GND | GND | latch.E11 | CHG.OUT- (not BAT-) | CHG.OUT- (not BAT-) | external harness | Lap-solder at this joint; one inserted component leg per hole. Strain-relieve the insulated harness wire.; insulate and strain-relieve the wire. Reciprocal board-terminal rows describe the same cable, not a second cable.
latch | terminal | ESP_GND | GND | latch.F11 | ESP.GND | ESP.GND | external harness | Lap-solder at this joint; one inserted component leg per hole. Strain-relieve the insulated harness wire.; insulate and strain-relieve the wire. Reciprocal board-terminal rows describe the same cable, not a second cable.
latch | terminal | BOOST_GND | GND | latch.G11 | BOOST.VIN- | BOOST.VIN- | external harness | Lap-solder at this joint; one inserted component leg per hole. Strain-relieve the insulated harness wire.; insulate and strain-relieve the wire. Reciprocal board-terminal rows describe the same cable, not a second cable.
latch | terminal | BOOST_OUT_GND | GND | latch.H11 | BOOST.VOUT- | BOOST.VOUT- | external harness | Lap-solder at this joint; one inserted component leg per hole. Strain-relieve the insulated harness wire.; insulate and strain-relieve the wire. Reciprocal board-terminal rows describe the same cable, not a second cable.
latch | terminal | DRIVER_GND | GND | latch.I11 | Driver C13 / GND | Driver C13 / GND | external harness | Lap-solder at this joint; one inserted component leg per hole. Strain-relieve the insulated harness wire.; insulate and strain-relieve the wire. Reciprocal board-terminal rows describe the same cable, not a second cable.
latch | terminal | LATCH_GPIO | GATE | latch.B8 | ESP GPIO3 | ESP GPIO9 | external harness | Lap-solder at this joint; one inserted component leg per hole. Strain-relieve the insulated harness wire.; insulate and strain-relieve the wire. Reciprocal board-terminal rows describe the same cable, not a second cable.
latch | terminal | SENSE_GPIO | SENSE | latch.J7 | ESP GPIO4 | ESP GPIO8 | external harness | Lap-solder at this joint; one inserted component leg per hole. Strain-relieve the insulated harness wire.; insulate and strain-relieve the wire. Reciprocal board-terminal rows describe the same cable, not a second cable.
driver | insulated wire | driver-J01 | GATE_G | driver.B2 | driver.D3 | driver.D3 | bottom | Insulated span; solder only the two named pads. Crossings do not join. | driver-J01 | B2 → D3
driver | insulated wire | driver-J02 | GATE_G | driver.D3 | driver.E3 | driver.E3 | bottom | Insulated span; solder only the two named pads. Crossings do not join. | driver-J02 | D3 → E3
driver | insulated wire | driver-J03 | GND | driver.C2 | driver.E2 | driver.E2 | bottom | Insulated span; solder only the two named pads. Crossings do not join. | driver-J03 | C2 → E2
driver | insulated wire | driver-J04 | GATE_R | driver.B4 | driver.D5 | driver.D5 | bottom | Insulated span; solder only the two named pads. Crossings do not join. | driver-J04 | B4 → D5
driver | insulated wire | driver-J05 | GATE_R | driver.D5 | driver.E5 | driver.E5 | bottom | Insulated span; solder only the two named pads. Crossings do not join. | driver-J05 | D5 → E5
driver | insulated wire | driver-J06 | GND | driver.C4 | driver.E4 | driver.E4 | bottom | Insulated span; solder only the two named pads. Crossings do not join. | driver-J06 | C4 → E4
driver | insulated wire | driver-J07 | GATE_B | driver.B6 | driver.D7 | driver.D7 | bottom | Insulated span; solder only the two named pads. Crossings do not join. | driver-J07 | B6 → D7
driver | insulated wire | driver-J08 | GATE_B | driver.D7 | driver.E7 | driver.E7 | bottom | Insulated span; solder only the two named pads. Crossings do not join. | driver-J08 | D7 → E7
driver | insulated wire | driver-J09 | GND | driver.C6 | driver.E6 | driver.E6 | bottom | Insulated span; solder only the two named pads. Crossings do not join. | driver-J09 | C6 → E6
driver | insulated wire | driver-J10 | GATE_WW | driver.B8 | driver.D9 | driver.D9 | bottom | Insulated span; solder only the two named pads. Crossings do not join. | driver-J10 | B8 → D9
driver | insulated wire | driver-J11 | GATE_WW | driver.D9 | driver.E9 | driver.E9 | bottom | Insulated span; solder only the two named pads. Crossings do not join. | driver-J11 | D9 → E9
driver | insulated wire | driver-J12 | GND | driver.C8 | driver.E8 | driver.E8 | bottom | Insulated span; solder only the two named pads. Crossings do not join. | driver-J12 | C8 → E8
driver | insulated wire | driver-J13 | GATE_CW | driver.B10 | driver.D11 | driver.D11 | bottom | Insulated span; solder only the two named pads. Crossings do not join. | driver-J13 | B10 → D11
driver | insulated wire | driver-J14 | GATE_CW | driver.D11 | driver.E11 | driver.E11 | bottom | Insulated span; solder only the two named pads. Crossings do not join. | driver-J14 | D11 → E11
driver | insulated wire | driver-J15 | GND | driver.C10 | driver.E10 | driver.E10 | bottom | Insulated span; solder only the two named pads. Crossings do not join. | driver-J15 | C10 → E10
driver | ground bus | driver-J16 | GND | driver.C2 | driver.C13 | driver.C13 | bottom | One dedicated ground conductor; solder windows/taps at C2 → C4 → C6 → C8 → C10 → C13. Keep spans insulated and size the conductor for measured return current; do not use a resistor leg as the load-current backbone. | driver-ground | C2 → C4 → C6 → C8 → C10 → C13
driver | terminal | PWM_G | PWM_G | driver.D2 | ESP GPIO5 | ESP GPIO5 | external harness | lap-solder to the resistor lead underneath; no second inserted conductor; insulate and strain-relieve the wire. Reciprocal board-terminal rows describe the same cable, not a second cable.
driver | terminal | LED_G | LED_G | driver.A2 | LED.G | LED.G | external harness | lap-solder to drain lead underneath; no second inserted conductor; insulate and strain-relieve the wire. Reciprocal board-terminal rows describe the same cable, not a second cable.
driver | terminal | PWM_R | PWM_R | driver.D4 | ESP GPIO6 | ESP GPIO4 | external harness | lap-solder to the resistor lead underneath; no second inserted conductor; insulate and strain-relieve the wire. Reciprocal board-terminal rows describe the same cable, not a second cable.
driver | terminal | LED_R | LED_R | driver.A4 | LED.R | LED.R | external harness | lap-solder to drain lead underneath; no second inserted conductor; insulate and strain-relieve the wire. Reciprocal board-terminal rows describe the same cable, not a second cable.
driver | terminal | PWM_B | PWM_B | driver.D6 | ESP GPIO7 | ESP GPIO6 | external harness | lap-solder to the resistor lead underneath; no second inserted conductor; insulate and strain-relieve the wire. Reciprocal board-terminal rows describe the same cable, not a second cable.
driver | terminal | LED_B | LED_B | driver.A6 | LED.B | LED.B | external harness | lap-solder to drain lead underneath; no second inserted conductor; insulate and strain-relieve the wire. Reciprocal board-terminal rows describe the same cable, not a second cable.
driver | terminal | PWM_WW | PWM_WW | driver.D8 | ESP GPIO10 | ESP GPIO10 | external harness | lap-solder to the resistor lead underneath; no second inserted conductor; insulate and strain-relieve the wire. Reciprocal board-terminal rows describe the same cable, not a second cable.
driver | terminal | LED_WW | LED_WW | driver.A8 | LED.WW | LED.WW | external harness | lap-solder to drain lead underneath; no second inserted conductor; insulate and strain-relieve the wire. Reciprocal board-terminal rows describe the same cable, not a second cable.
driver | terminal | PWM_CW | PWM_CW | driver.D10 | ESP GPIO20 | ESP GPIO11 | external harness | lap-solder to the resistor lead underneath; no second inserted conductor; insulate and strain-relieve the wire. Reciprocal board-terminal rows describe the same cable, not a second cable.
driver | terminal | LED_CW | LED_CW | driver.A10 | LED.CW | LED.CW | external harness | lap-solder to drain lead underneath; no second inserted conductor; insulate and strain-relieve the wire. Reciprocal board-terminal rows describe the same cable, not a second cable.
driver | terminal | SYSTEM_GND | GND | driver.C13 | Compact latch I11 / protected CHG.OUT- | Compact latch I11 / protected CHG.OUT- | external harness | dedicated solder pad; insulate and strain-relieve the wire. Reciprocal board-terminal rows describe the same cable, not a second cable.
combined | retained component leg | combined-L01 | OUT+ | combined.D1 | combined.B2 | combined.B2 | bottom | Reuse Rbe.1; retain at least 9.62 mm below the seated board. Bend and solder at ALL named holes: D1 → C1 → C2 → B2. Trim only beyond the final joint after soldering. If too short or stiff, use an insulated link. Crossings do not join unless listed. | combined-L01 | D1 → C1 → C2 → B2 | Rbe.1 | 9.62
combined | retained component leg | combined-L02 | OUT+ | combined.B2 | combined.A1 | combined.A1 | bottom | Reuse QP.E; retain at least 7.08 mm below the seated board. Bend and solder at ALL named holes: B2 → A2 → A1. Trim only beyond the final joint after soldering. If too short or stiff, use an insulated link. Crossings do not join unless listed. | combined-L02 | B2 → A2 → A1 | QP.E | 7.08
combined | retained component leg | combined-L03 | PB | combined.D2 | combined.D3 | combined.D3 | bottom | Reuse Rbe.2; retain at least 4.54 mm below the seated board. Bend and solder at ALL named holes: D2 → D3. Trim only beyond the final joint after soldering. If too short or stiff, use an insulated link. Crossings do not join unless listed. | combined-L03 | D2 → D3 | Rbe.2 | 4.54
combined | retained component leg | combined-L04 | PB | combined.B3 | combined.D3 | combined.D3 | bottom | Reuse QP.B; retain at least 7.08 mm below the seated board. Bend and solder at ALL named holes: B3 → C3 → D3. Trim only beyond the final joint after soldering. If too short or stiff, use an insulated link. Crossings do not join unless listed. | combined-L04 | B3 → C3 → D3 | QP.B | 7.08
combined | retained component leg | combined-L05 | VSW | combined.B4 | combined.A5 | combined.A5 | bottom | Reuse QP.C; retain at least 7.08 mm below the seated board. Bend and solder at ALL named holes: B4 → A4 → A5. Trim only beyond the final joint after soldering. If too short or stiff, use an insulated link. Crossings do not join unless listed. | combined-L05 | B4 → A4 → A5 | QP.C | 7.08
combined | retained component leg | combined-L06 | LDRV | combined.D7 | combined.B7 | combined.B7 | bottom | Reuse Rb.2; retain at least 7.08 mm below the seated board. Bend and solder at ALL named holes: D7 → C7 → B7. Trim only beyond the final joint after soldering. If too short or stiff, use an insulated link. Crossings do not join unless listed. | combined-L06 | D7 → C7 → B7 | Rb.2 | 7.08
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

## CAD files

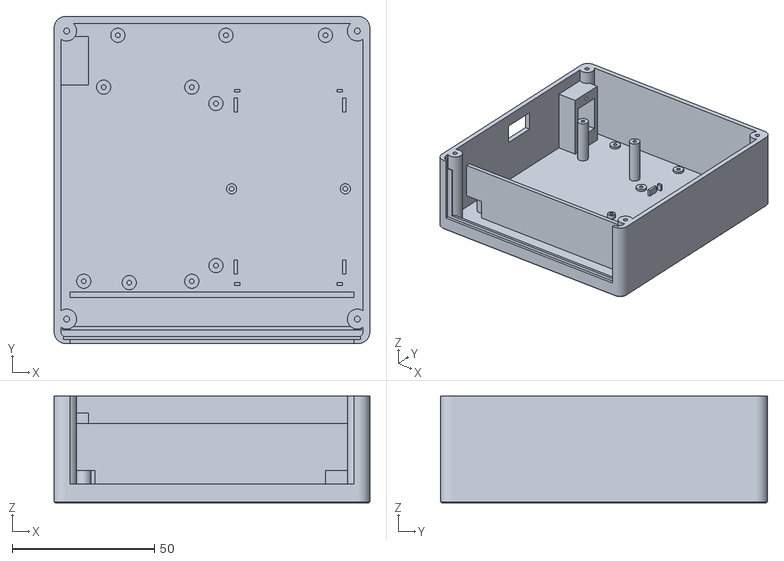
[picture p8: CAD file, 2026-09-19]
prints/body.stl
111.0 x 115.0 x 37.6

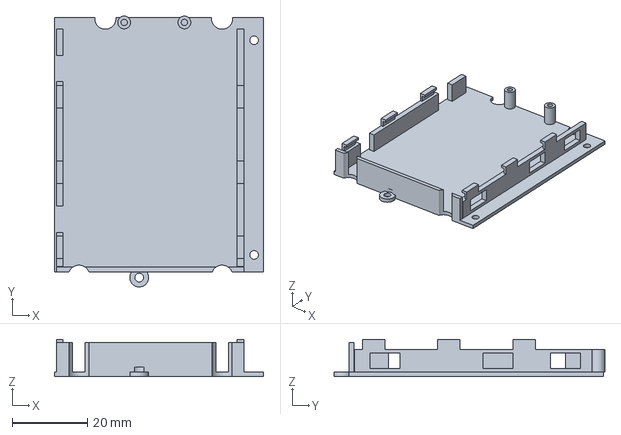
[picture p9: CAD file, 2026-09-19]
profiles/carrier_tray-p1s-petg.3mf
55.5 x 71.9 x 9.85 mm

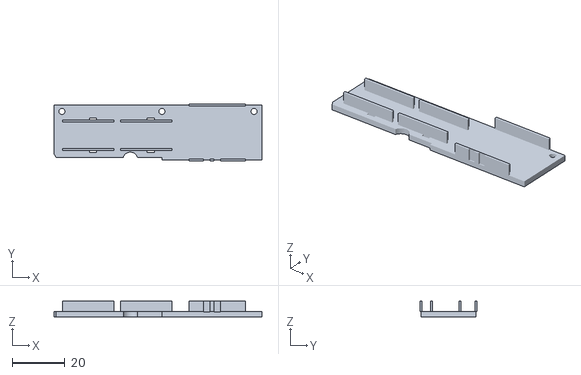
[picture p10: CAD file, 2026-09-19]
prints/connector_saddles.stl
79.0 x 21.6 x 6.00

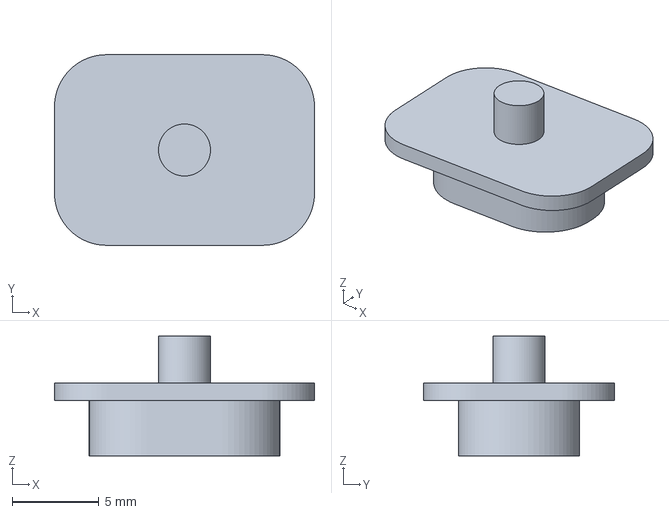
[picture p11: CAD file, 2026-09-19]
profiles/button-p1s-petg.3mf
15.0 x 11.0 x 6.90 mm

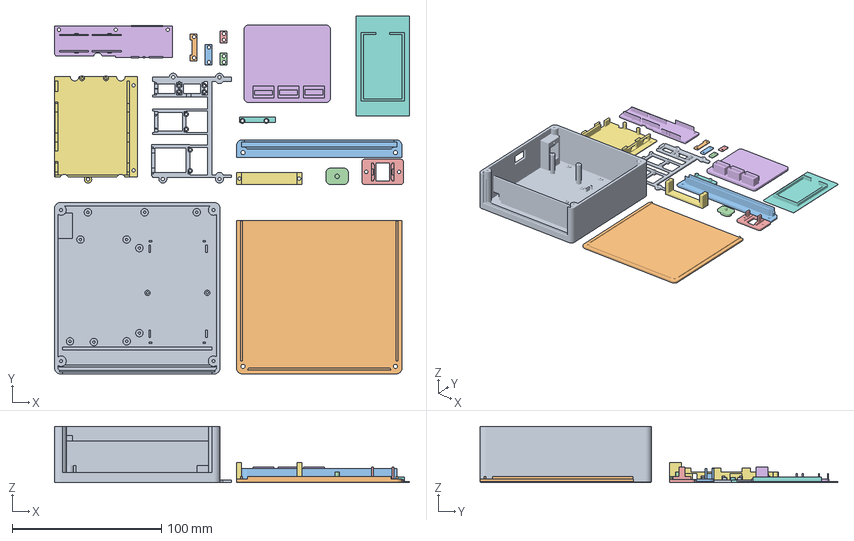
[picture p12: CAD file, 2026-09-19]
prints/black-parts.3mf
238.0 x 240.0 x 37.6 mm
lid
rail
button
switch_carrier
coupon
carrier_tray
carrier_keeper
module_tier
clamp_esp
clamp_charger
clamp_reg5
clamp_reg12
connector_saddles
battery_bridge
battery_insert

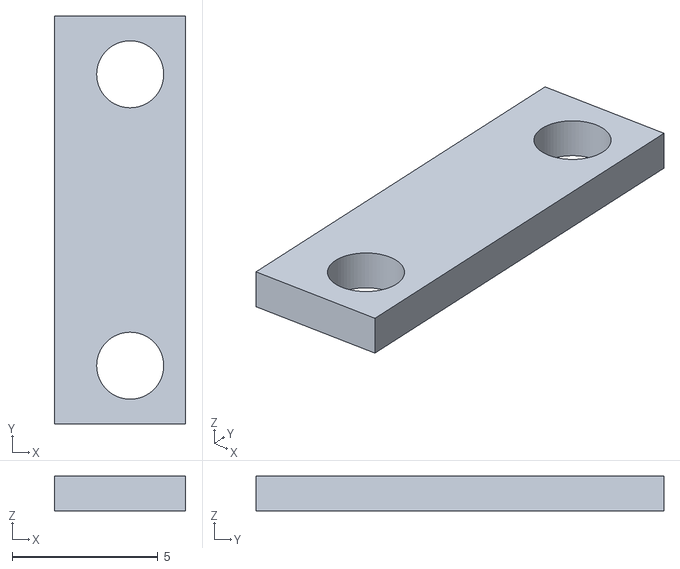
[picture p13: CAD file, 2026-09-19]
prints/clamp_charger.stl
4.50 x 14.0 x 1.20

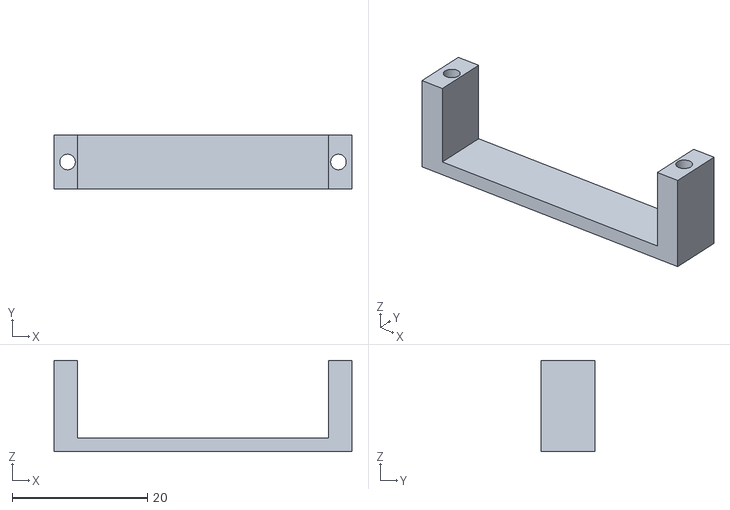
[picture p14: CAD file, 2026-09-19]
prints/battery_bridge.stl
44.0 x 8.00 x 13.5

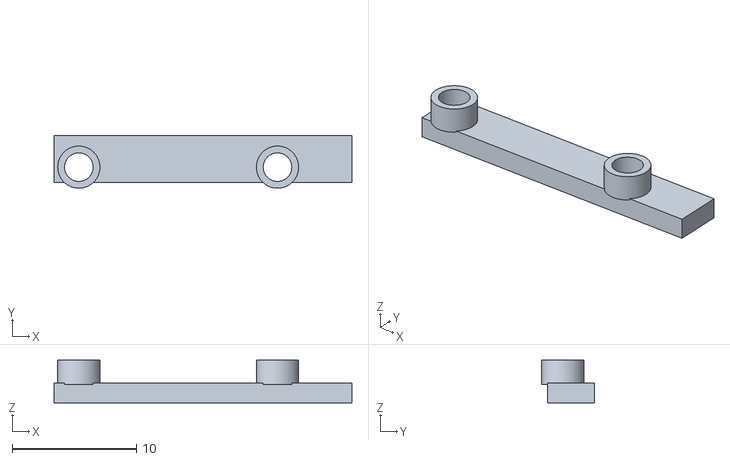
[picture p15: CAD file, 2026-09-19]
prints/carrier_keeper.stl
24.0 x 4.23 x 3.45

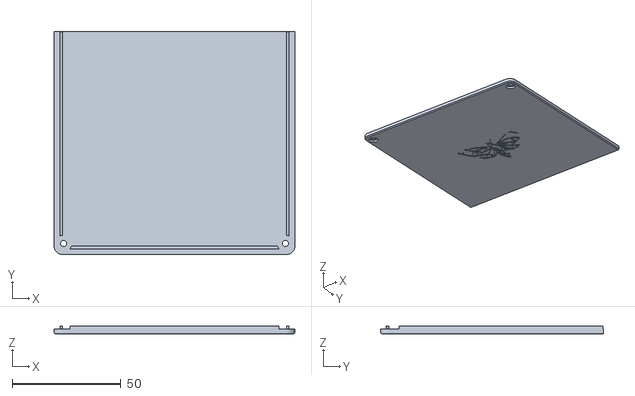
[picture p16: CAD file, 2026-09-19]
prints/lid.stl
111.0 x 102.7 x 3.90

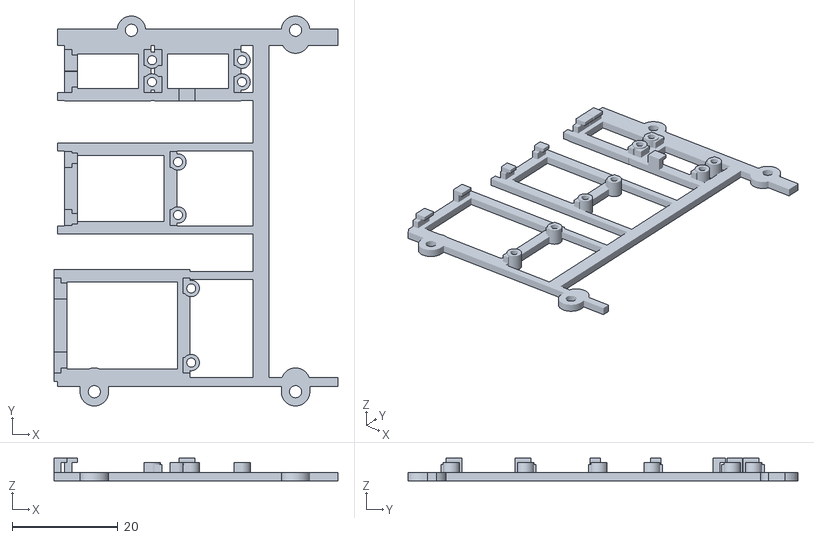
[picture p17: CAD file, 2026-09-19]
prints/module_tier.stl
53.6 x 73.6 x 4.25

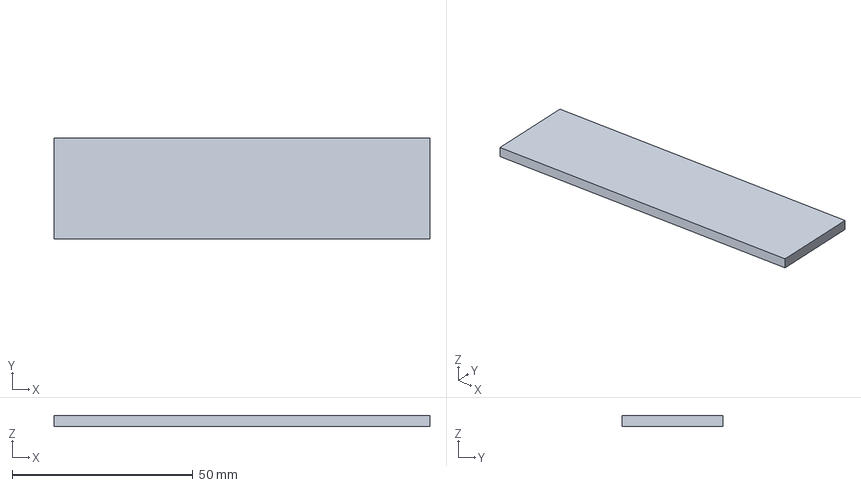
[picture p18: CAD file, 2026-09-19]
prints/diffuser-template.3mf
104.0 x 28.0 x 3.00 mm

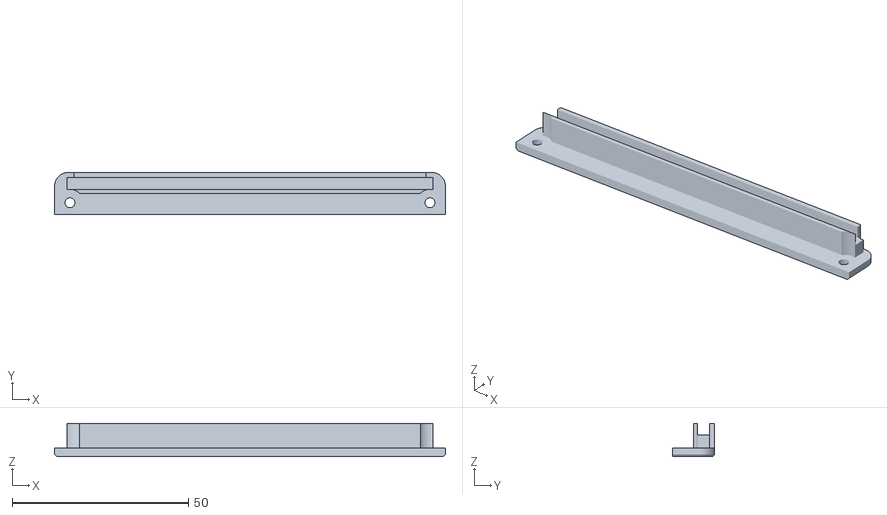
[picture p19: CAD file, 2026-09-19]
prints/rail.stl
111.0 x 12.0 x 9.40

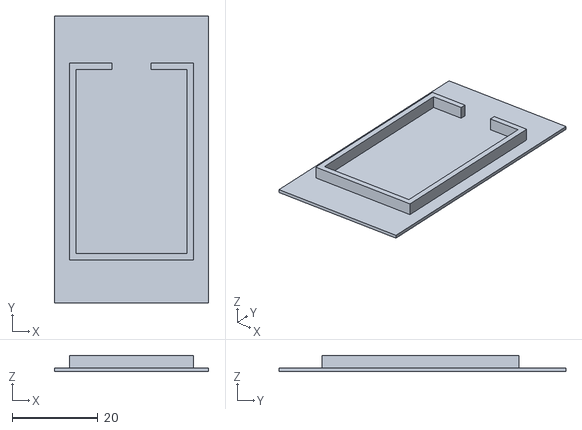
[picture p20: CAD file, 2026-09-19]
prints/battery_insert.stl
36.0 x 67.0 x 3.80

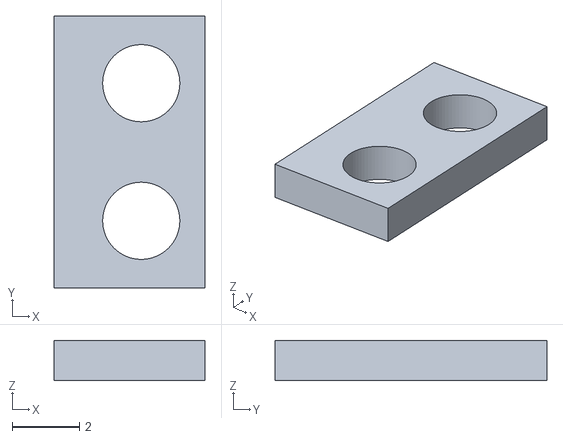
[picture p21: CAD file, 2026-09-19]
prints/clamp_reg12.stl
4.50 x 8.10 x 1.20

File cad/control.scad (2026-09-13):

module control_frame() {
    translate([key_x,key_y,key_z]) rotate([0,-90,0]) children();
}
module button_local() {
    // Captive between the sidewall and carrier; press toward local -w / global +X.
    translate([0,0,-key_flange_t]) prism(key_flange_w,key_flange_d,key_flange_t,3);
    translate([0,0,-0.01]) prism(key_w,key_d,wall+key_proud+0.01,3.3);
    translate([0,0,key_tip]) cylinder(d=3,h=-key_flange_t-key_tip+0.05);
}
module button() { control_frame() button_local(); }
module button_opening() {
    control_frame() translate([0,0,-0.1])
        prism(key_w+2*fit,key_d+2*fit,wall+0.2,3.5);
}
module switch_carrier_local() {
    difference() {
        union() {
            translate([0,0,carrier_bottom]) prism(carrier_w,carrier_d,carrier_t,2);
            // Slide a 12 mm daughterboard under these retaining lips from either end.
            // Body cradle rails close the ends when this carrier is screwed in place.
            for(s=[-1,1]) {
                translate([s*6.85-0.6,-6,carrier_bottom+carrier_t-0.02])
                    cube([1.2,12,2.02]);
                translate([s > 0 ? 5.5 : -7.45,-5,carrier_bottom+carrier_t+remote_pcb_t+0.1])
                    cube([1.95,10,0.5]);
                // Hard stops under key flange; key_travel sets maximum inward motion.
                translate([s*6.85-0.6,-2,carrier_bottom+carrier_t-0.02])
                    cube([1.2,4,key_stop-carrier_bottom-carrier_t+0.02]);
            }
        }
        for(u=[-mount_offset,mount_offset]) translate([u,0,carrier_bottom-0.1])
            cylinder(d=2.3,h=carrier_t+0.2);
        // Lead/solder clearance below the center, board rests at its edges.
        translate([-4.5,-6.1,carrier_bottom-0.1]) cube([9,12.2,carrier_t+0.2]);
    }
}
module switch_carrier() { control_frame() switch_carrier_local(); }
module control_cradle() {
    // Floor-rooted rails support a 12.5 mm bridge above the key, keeping overhangs
    // short without blocking the plunger or electronics. Pilot bores face inward.
    difference() {
        union() {
            for(s=[-1,1]) translate([-0.2,key_y+(s>0 ? cradle_inner : -cradle_outer),-0.1])
                cube([cradle_depth+0.2,cradle_outer-cradle_inner,cradle_top+0.1]);
            translate([-0.2,key_y-cradle_inner,-0.1])
                cube([cradle_depth+0.2,2*cradle_inner,key_z-mount_offset+mount_radius+0.1]);
            translate([-0.2,key_y-cradle_inner,key_z+mount_offset-mount_radius])
                cube([cradle_depth+0.2,2*cradle_inner,2*mount_radius]);
        }
        for(z=[key_z-mount_offset,key_z+mount_offset])
            translate([cradle_depth+0.1,key_y,z]) rotate([0,-90,0]) cylinder(d=1.7,h=6.3);
    }
}
module diffuser() {
    translate([cx-sheet_w/2,sheet_y,sheet_z]) cube([sheet_w,sheet_t,sheet_h]);
}
module coupon() {
    difference() {
        translate([0,0,0]) prism(58,52,2.4,3);
        // Match the lid's bed-facing 0.5 mm recess, including its printed Y flip.
        // Slot banks stay upright; inspect the moth on the underside after printing.
        translate([0,4,-0.1]) linear_extrude(logo_depth+0.1)
            mirror([0,1,0]) moth();
    }
    // Slot bank: insert a corner of real stock; nominal thickness + 0.2/0.4/0.6.
    for(i=[0:2]) translate([-23+i*17,-23,2.4]) difference() {
        cube([14,8,8]);
        translate([1,2,2]) cube([12,sheet_t+0.2+i*0.2,7]);
    }
}

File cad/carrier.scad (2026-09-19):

// R6 removable carrier, insulating module tier and service fixtures.
// Supports touch PCB edge lands only. All sockets, wires and fitted stock need dry fit.
module small_post(p,h,r=2.5) {
    translate([p[0],p[1],0]) difference() {
        cylinder(r=r,h=h);
        translate([0,0,-1.8]) cylinder(d=1.7,h=h+1.9);
    }
}
module product_body_mounts() {
    for(p=tray_mounts) small_post(p,1);
    for(p=tier_mounts) small_post(p,tier_z-1.6);
    for(p=battery_mounts) small_post(p,2,r=1.8);
    for(p=connector_mounts) small_post(p,1);
    // Smooth low pouch stops: no clamp pressure or screws over the pouch.
    for(p=[[61,18],[97,18],[61,86],[97,86]])
        translate([p[0],p[1],0]) cube([2,1,3]);
    for(x=[60.8,99]) for(y=[22,79])
        translate([x,y,0]) cube([1.2,5,3]);
}
module carrier_tray() {
    difference() {
        union() {
            translate([1.5,20.5,1]) cube([55.5,67.5,1.2]);
            for(p=tray_mounts) translate([p[0],p[1],1]) cylinder(r=2.5,h=1.2);
            // Lower ledges and outside walls, interrupted at body retaining tabs.
            for(range=[[22,31],[38,71],[78,85.02]])
                translate([2.0,range[0],2.2]) cube([1.8,range[1]-range[0],bz-2.2]);
            translate([49.98,22,2.2]) cube([1.8,63.02,bz-2.2]);
            for(y=[24,44,64]) {
                translate([2.0,y,bz]) cube([0.75,6,2.15]);
                translate([2.0,y,bz+bt+fit]) cube([1.8,6,0.8]);
                translate([51.03,y,bz]) cube([0.75,6,2.15]);
                translate([49.98,y,bz+bt+fit]) cube([1.8,6,0.8]);
            }
            // Closed front end; rear keeper is removable.
            translate([2,20.5,2.2]) cube([49.78,1.25,bz+bt+fit-2.2]);
            for(x=[20,36]) translate([x,86.75,2.2]) difference() {
                cylinder(r=1.7,h=bz-2.2);
                cylinder(d=1.7,h=12);
            }
        }
        for(p=tray_mounts) {
            translate([p[0],p[1],0.9]) cylinder(d=2.3,h=2);
            translate([p[0],p[1],2.2]) cylinder(r=2.0,h=1.4);
        }
        for(y=[26,56,74]) translate([49, y, 3.2]) cube([4,8,4]);
        // Tier supports rise from case independently of the removable cassette.
        for(p=tier_mounts) translate([p[0],p[1],0]) cylinder(r=2.8,h=40);
    }
}
module carrier_keeper() {
    difference() {
        union() {
            translate([18,84.22,bz+bt+fit]) cube([24,3.78,1.6]);
            for(x=[20,36]) translate([x,86.75,bz]) cylinder(r=1.7,h=bt+fit+0.1);
        }
        for(x=[20,36]) translate([x,86.75,bz-0.1]) cylinder(d=2.3,h=5);
    }
}
module seat_rim(s) {
    x=s[0]; y=s[1]; w=s[2]; d=s[3];
    difference() {
        translate([x-1.6,y-1.6,tier_z-1.6]) cube([w+3.2,d+3.2,1.6]);
        translate([x+0.8,y+0.8,tier_z-1.7]) cube([w-1.6,d-1.6,1.8]);
    }
    // Short charger keepers leave its left-facing USB mouth unobstructed.
    keeper_l=(s==module_seats[1]) ? 2 : 3;
    keeper_inset=(s==module_seats[1]) ? 0.25 : 1;
    if(x < 20) for(yy=[y+keeper_inset,y+d-keeper_inset-keeper_l]) {
        translate([x-1.6,yy,tier_z]) cube([1.35,keeper_l,2.65]);
        translate([x-1.6,yy,tier_z+1.85]) cube([2.4,keeper_l,0.8]);
    }
    else {
        translate([x+3,y-1.6,tier_z]) cube([3,1.35,2.65]);
        translate([x+3,y-1.6,tier_z+1.85]) cube([3,2.4,0.8]);
    }
    // Corner guides stop below the board top. Pigtails leave through open sides.
    for(xx=[x-1.6,x+w+fit]) for(yy=[y,y+d-3])
        translate([xx,yy,tier_z]) cube([1.35,3,1.5]);
}
module module_tier() {
    difference() {
        union() {
            for(s=module_seats) seat_rim(s);
            // One connected insulating perimeter, with the left USB edge open.
            translate([1,20.5,tier_z-1.6]) cube([53,1.7,1.6]);
            translate([38,20.5,tier_z-1.6]) cube([3,67.5,1.6]);
            translate([1,84.9,tier_z-1.6]) cube([53,3.1,1.6]);
            for(y=[40.7,module_seats[1][1]-1.6,module_seats[1][1]+module_seats[1][3]+0.1,74.5,85])
                translate([1,y,tier_z-1.6]) cube([40,1.5,1.6]);
            for(p=tier_mounts) hull() {
                translate([p[0],p[1],tier_z-1.6]) cylinder(r=2.7,h=1.6);
                translate([p[0],p[1]<22 ? 21.3 : 86.1,tier_z-1.6]) cylinder(r=2.7,h=1.6);
            }
            for(s=module_seats) for(y=[s[1]+2,s[1]+s[3]-2])
                translate([s[0]+s[2]+1.8,y,tier_z-1.6]) cylinder(r=1.55,h=3.45);
        }
        for(p=tier_mounts) translate([p[0],p[1],tier_z-2]) cylinder(d=2.3,h=8);
        for(s=module_seats) for(y=[s[1]+2,s[1]+s[3]-2])
            translate([s[0]+s[2]+1.8,y,tier_z-2]) cylinder(d=1.7,h=8);
        // Keep edge overhangs within the left inside face of the body.
        translate([-20,0,0]) cube([20.15,120,50]);
    }
}
module module_clamp(i) {
    s=module_seats[i];
    difference() {
        translate([s[0]+s[2]-0.8,s[1],tier_z+1.85]) cube([4.5,s[3],1.2]);
        if(i==0) translate([s[0]+s[2]-1,s[1]+4,tier_z+1.7]) cube([1.3,10,2]);
        for(y=[s[1]+2,s[1]+s[3]-2])
            translate([s[0]+s[2]+1.8,y,tier_z+1.5]) cylinder(d=2.3,h=4);
    }
}
module connector_saddles() {
    difference() {
        union() {
            translate([17,87.5,1]) cube([79,21,2]);
            for(s=[[21,92,18,10],[43,92,18,10],[69,88,20,20]]) {
                translate([s[0]-0.8,s[1]-0.8,3]) cube([s[2]+1.6,0.8,4]);
                translate([s[0]-0.8,s[1]+s[3],3]) cube([s[2]+1.6,0.8,4]);
                // Open ends allow withdrawal; insulated tie secures housing, not latch.
            }
        }
        for(p=connector_mounts) translate([p[0],p[1],0.9]) cylinder(d=2.3,h=8);
        // Clearance for the two 1.6 mm pack leads ahead of the LED housing.
        for(x=[75,79]) translate([x-1.2,87.1,2.9]) cube([2.4,0.8,4.3]);
        translate([16,87,0.8]) cube([42,1.5,3]);
        for(p=tier_mounts) translate([p[0],p[1],0]) cylinder(r=2.8,h=10);
        for(s=[[21,92,18,10],[43,92,18,10],[69,88,20,20]])
            for(y=[s[1]-1.6,s[1]+s[3]+0.8])
                translate([s[0]+s[2]/2+0.4,y,0.8]) cube([2.8,0.8,2.4]);
    }
}
module battery_bridge() {
    difference() {
        union() {
            translate([58,48,13.5]) cube([44,8,2]);
            translate([58,48,2]) cube([3.5,8,11.5]);
            translate([98.5,48,2]) cube([3.5,8,11.5]);
        }
        for(p=battery_mounts) translate([p[0],p[1],1.9]) cylinder(d=2.3,h=16);
    }
}
module battery_insert() {
    // Optional 42 x 25 x 10 mm pack insert; remove for the 3000 mAh pack.
    translate([62,19,1]) cube([36,67,0.8]);
    translate([65.5,29,1.8]) difference() {
        cube([29,46,3]);
        translate([1.5,1.5,-0.1]) cube([26,43,3.2]);
        translate([10,43,-0.1]) cube([9,4,3.2]);
    }
}
module product_part(p) {
    if(p=="carrier_tray") carrier_tray();
    else if(p=="carrier_keeper") carrier_keeper();
    else if(p=="module_tier") module_tier();
    else if(p=="clamp_esp") module_clamp(0);
    else if(p=="clamp_charger") module_clamp(1);
    else if(p=="clamp_reg5") module_clamp(2);
    else if(p=="clamp_reg12") module_clamp(3);
    else if(p=="connector_saddles") connector_saddles();
    else if(p=="battery_bridge") battery_bridge();
    else if(p=="battery_insert") battery_insert();
}
module product_print(p) {
    if(p=="carrier_tray" || p=="connector_saddles" || p=="battery_insert") translate([0,0,-1]) product_part(p);
    else if(p=="carrier_keeper") translate([0,90,bz+bt+fit+1.6]) rotate([180,0,0]) product_part(p);
    else if(p=="module_tier") translate([0,0,-tier_z+1.6]) product_part(p);
    else if(p=="battery_bridge") translate([0,56,15.5]) rotate([180,0,0]) product_part(p);
    else translate([0,0,-tier_z-1.85]) product_part(p);
}

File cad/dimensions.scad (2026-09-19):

// Dark Moth enclosure R6. Nominal purchased-part dimensions require dry fit.
// X right, Y rearward, Z upward. Interior floor is Z=0; front inside face Y=0.
wall=2.4;
floor_t=2.4;
lid_t=2.4;
ix=106.2;
iy=110.2;
iz=35.2;
corner_r=4;
edge_chamfer=0.6;
seam=0.25;
rail_end=9.6;
lap_h=1.5;
fit=0.25;
// One integrated perfboard; its component face points upward.
bx=3;
by=22;
bz=8.2;
bw=47.78;
bd=63.02;
bt=1.6;
case_holes=[[2,6.2],[104.2,6.2],[2,107.5],[104.2,107.5]];
battery=[62,19,1,36,67,10];
tray_mounts=[[24,19],[54.5,25],[54.5,82]];
tier_mounts=[[8,19.5],[46,19.5],[15,87.75],[46,87.75]];
battery_mounts=[[60,52],[100,52]];
connector_mounts=[[20,106],[58,106],[93,106]];
tier_z=bz+bt+12;
// PCB bottoms at tier_z; module support pockets have an open underside.
module_seats=[[2,23,22.5,18],[4,50.875,18,14],[4,76,13.1,8.1],[21,76,13.1,8.1]];
// Charger USB opening is provisional until the purchased module is measured.
charge_y=57.875;
charge_z=tier_z+3.2;
charge_w=16;
charge_h=9;
// Removable sheet. Default is cut stock, NOT the old pre-cut 94.8 mm sheet.
sheet_w=104;
sheet_h=28;
sheet_t=3;
sheet_z=3.2;
sheet_y=-1;
slot_clear=0.4;
window_w=100;
window_bottom=4.2;
window_top=28.2;
strip_y=11.2; // 9.2 mm behind 3 mm acrylic; optical uniformity requires bench testing.
strip_t=2.5;
rib_y=13.7;
rib_h=25.5;
// Left-side key: local u -> +Z, v -> +Y, w -> -X (outward).
// Local w=0 is the inner sidewall. The two-wire daughterboard faces -X.
key_x=0;
key_y=97;
key_z=15.5;
key_w=11;
key_d=7;
key_proud=0.8;
key_flange_w=15;
key_flange_d=11;
key_flange_t=1;
key_travel=0.35; // 0.25 mm nominal switch depression after the 0.1 mm gap; measure actual tact.
carrier_depth=11.7;
carrier_bottom=-carrier_depth;
carrier_t=2;
carrier_w=28;
carrier_d=17;
mount_offset=11;
mount_radius=2.8;
cradle_inner=6.25;
cradle_outer=carrier_d/2;
cradle_depth=carrier_depth-carrier_t;
cradle_top=key_z+mount_offset+mount_radius;
remote_pcb_t=1.6;
switch_h=4.3;
switch_gap=0.1;
key_tip=carrier_bottom+carrier_t+remote_pcb_t+switch_h+switch_gap;
key_stop=-key_flange_t-key_travel;
logo_w=44;
logo_depth=0.5;
logo_y=54;
cx=ix/2;
cy=iy/2;
outer_w=ix+2*wall;
outer_d=iy+2*wall;

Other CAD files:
prints/carrier_tray.stl
profiles/body-p1s-petg.3mf
prints/clamp_esp.stl
prints/clamp_reg5.stl
cad/enclosure.scad
cad/primitives.scad
cad/shell.scad
prints/button.stl
prints/coupon.stl
prints/diffuser.stl
prints/switch_carrier.stl

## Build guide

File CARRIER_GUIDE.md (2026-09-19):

# R6 carrier build guide

**Revision carrier-r6-2026-09 · ESP32-C3 SuperMini · physical verification
pending.** Use one 18-column × 24-row isolated-pad carrier. The nominal outline
is 47.78 × 63.02 × 1.6 mm at 2.54 mm pitch. Check the actual blank, component
markings and pinouts before assembly. This revision replaces the SS8550, BS170
and MT3608 arrangement and the previous BQ25185 version. The owned UMLIFE
charger requires the complete device to be off while charging.

[Interactive carrier](perfboard.html?board=carrier#workbench) ·
[Component side](electronics/perfboard-carrier-top.svg) ·
[Solder side](electronics/perfboard-carrier-bottom.svg) ·
[Module wiring](electronics/perfboard-carrier-modules.svg) ·
[Electrical decisions and bench checks](PRODUCT_ELECTRICAL_PLAN.md)

## Parts to obtain

| Reference | Part | Quantity | Notes |
| --- | --- | --- | --- |
| CHG | [User-owned UMLIFE mini USB-C charger](https://www.amazon.com/dp/B0BRXYZTWN) | 1 | Owned part; fully switch off before charging. Seller claims 1 A; actual IC, current, pads and cell charge limits require verification. No automatic lockout. |
| REG5 | [Pololu U3V16F5](https://www.pololu.com/product/4941) | 1 | |
| REG12 | [Pololu U3V16F12](https://www.pololu.com/product/4945) | 1 | |
| QP | [Diodes DMP2035U-7](https://www.diodes.com/datasheet/download/DMP2035U.pdf) | 2 | Both footprints of one adapter in parallel; measured current sharing and thermal qualification required. |
| Q1–Q5 | [Diodes DMG2302UK-7](https://www.diodes.com/datasheet/download/DMG2302UK.pdf) | 5 | |
| ADAPTER | [Adafruit 1230 adapter sets (five SOT23 boards per set)](https://www.adafruit.com/product/1230) | 2 | Seven individual SOT23 boards required; two supplier sets provide ten. No SOT23-6 devices fitted. |
| JSV | [Harwin M20-9990246 two-pin 2.54 mm header and matching shunt](https://www.harwin.com/products/M20-9990246) | 1 | Internal 5 V programming disconnect; remove shunt before ESP USB. |
| UUV | [TI TLV803EA30DBZR supervisor](https://www.ti.com/product/TLV803E/part-details/TLV803EA30DBZR) | 1 | Standard DBZ, pin1GND/pin2RESET/pin3VDD; 3.08 V falling threshold and 200 ms typical release. Mount on seventh SOT23 adapter. |
| CUV | 100 nF nonpolar ceramic capacitor, ≥16 V | 1 | Body must fit 5 × 3 × 5 mm reservation; 2.54 mm formed lead pitch. Bypass UUV VDD to GND. |
| STOCK | 2N3904 ×2, 2N3906 ×1, 1N4148 ×1, 20 axial resistors, NO button | 1 | Identify manufacturer pinouts and values. Reuse only correct parts. |
| BATT | User JLJLUP LP103665 protected 1S 3000 mAh | 1 | User image 67 × 36 × 10 mm, 1C / 3 A listing; actual factory wire and protection ratings unverified. Authorized XH re-termination preserves factory wires/protection/pouch. |

Also obtain suitable three-pin/2.54 mm straight header contacts for the seven
adapters (24 populated contacts total), a mating service shunt, insulated 22 AWG
power/return wire, lighter insulated signal wire, sleeving, and the matched
XH-style kit contacts/housings: two 2-pin pairs and one 6-pin pair. Power wire
outer diameter must fit the 1.6 mm reservation; signal wire must fit 1.0 mm.
These are selection limits, not measurements of existing wire.

The 20 resistors are five 100 Ω, two 1 kΩ, eight 10 kΩ, one 22 kΩ and four 100
kΩ. Confirm values by meter. TO92 lead order varies by manufacturer: form and
sleeve E/B/C leads into the role-labelled holes below.

## Adapter preparation and orientation

Use the **Adafruit 1230 SOT23 board**, 10.16 × 7.62 mm, with its SOT23 side up
and the opposite SOT23-6 footprint empty. Two retail sets provide ten SOT23
boards; seven are needed. This is a specified purchased adapter, not an
interchangeable generic breakout. Its
[supplier PCB drawing](https://github.com/adafruit/Adafruit-SMT-Breakout-PCBs/blob/9c2437974968b6cbf8347792d0e2a7c5c77a9249/6-pin%20SOT-23.brd)
defines the following orientation viewed from the component side:

- Q1 footprint is below the board centre. Gate is the middle left header, source
  bottom left, drain bottom right. For each LED adapter populate Q1 only and
  install only these three header contacts; leave the other holes empty.
  Continuity-check before installing the MOSFET.
- Q2 footprint is above centre. Gate is middle right, source top right, drain
  top left. Populate both Q1 and Q2 on the latch adapter QP with DMP2035U
  devices. All six contacts are used and each matching role is joined by the
  carrier wiring. Do not join different roles.
- Both selected SOT23 MOSFETs have physical pins 1 G, 2 S, 3 D. UUV uses the
  same footprint with different roles: standard DBZ pin 1 GND, pin 2 RESET and
  pin 3 VDD. Fit it only on the adapter at Q4/R4/R7. The package lead positions
  and header positions are different objects. Place adapter PCB undersides 3 mm
  above the carrier top; inspect the soldered SMD joints under magnification
  before fitting the adapter.

The adapter has 0.3048 mm-wide traces. The supplier does not specify copper
thickness or a current/thermal rating. Parallel QP devices reduce ideal
conduction loss but do not establish a 2.5 A adapter rating. Measure sharing,
source-to-drain drop and temperature with the actual assembled adapters. Use
separate matched-length 22 AWG connections to each QP source/drain branch where
practical; the listed joints remain mandatory.

## Exact component holes

A1 is upper-left viewed from the component side. On the mirrored solder side it
is upper-right; hole names never change. All five driver adapters share columns
10–13 and rows C/G/K/O/S. Their series resistors are in column 16 and pull-downs
in column 18. Upright resistor bodies sit at the first listed hole; insulate
their folded return leads. Only one component lead passes through each hole.
Pigtails lap-solder onto the same net underneath.

| Assembly | Value | Hole: role / net |
| --- | --- | --- |
| UUV | TLV803EA30DBZR | **Q4**: GND / GND; **R4**: RESET / H_BASE; **R7**: VDD / SW_SYS |
| CUV | 100nF ≥16V ceramic | **U7**: 1 / SW_SYS; **U8**: 2 / GND |
| QP | 2 × DMP2035U | **U2**: G1 / P_GATE; **V2**: S1 / SYS; **V5**: D1 / SW_SYS; **U5**: G2 / P_GATE; **T5**: S2 / SYS; **T2**: D2 / SW_SYS |
| QH | 2N3904 | **C2**: E / GND; **C3**: B / H_BASE; **C4**: C / H_COLL |
| QSP | 2N3906 | **G2**: E / SYS; **G3**: B / SP_BASE; **G4**: C / SP_COLL |
| QSN | 2N3904 | **K2**: E / GND; **K3**: B / SN_BASE; **K4**: C / BUTTON |
| RH | 10k | **C6**: a / HOLD; **D6**: b / H_BASE |
| RHP | 100k | **C8**: a / H_BASE; **D8**: b / GND |
| RHC | 1k | **E6**: a / P_GATE; **F6**: b / H_COLL |
| RSP | 100k | **G6**: a / SYS; **H6**: b / SP_BASE |
| RSW | 22k | **G8**: a / SP_BASE; **H8**: b / START |
| RSN | 10k | **I6**: a / SP_COLL; **J6**: b / SN_BASE |
| RSNP | 100k | **K6**: a / SN_BASE; **L6**: b / GND |
| RBU | 10k | **K8**: a / +3V3; **L8**: b / BUTTON |
| RSTART | 1k | **N8**: a / START_D; **O8**: b / START |
| RKEEP | 100k | **P2**: a / SYS; **Q2**: b / P_GATE |
| DSTART | 1N4148 | **N2**: A / P_GATE; **N6**: K / START_D |
| Q1 | DMG2302UK | **C10**: G / GATE_G; **D10**: S / GND; **D13**: D / LED_G |
| Rg1 | 100 | **C16**: a / PWM_G; **D16**: b / GATE_G |
| Rp1 | 10k | **C18**: a / GATE_G; **D18**: b / GND |
| Q2 | DMG2302UK | **G10**: G / GATE_R; **H10**: S / GND; **H13**: D / LED_R |
| Rg2 | 100 | **G16**: a / PWM_R; **H16**: b / GATE_R |
| Rp2 | 10k | **G18**: a / GATE_R; **H18**: b / GND |
| Q3 | DMG2302UK | **K10**: G / GATE_B; **L10**: S / GND; **L13**: D / LED_B |
| Rg3 | 100 | **K16**: a / PWM_B; **L16**: b / GATE_B |
| Rp3 | 10k | **K18**: a / GATE_B; **L18**: b / GND |
| Q4 | DMG2302UK | **O10**: G / GATE_WW; **P10**: S / GND; **P13**: D / LED_WW |
| Rg4 | 100 | **O16**: a / PWM_WW; **P16**: b / GATE_WW |
| Rp4 | 10k | **O18**: a / GATE_WW; **P18**: b / GND |
| Q5 | DMG2302UK | **S10**: G / GATE_CW; **T10**: S / GND; **T13**: D / LED_CW |
| Rg5 | 100 | **S16**: a / PWM_CW; **T16**: b / GATE_CW |
| Rp5 | 10k | **S18**: a / GATE_CW; **T18**: b / GND |
| JSV | 5 V service shunt  | **W16**: 1 / +5V_REG; **W17**: 2 / +5V_ESP |

DSTART stripe/cathode belongs at N6. JSV W16/W17 is the removable **5 V service
connection**, beside the raised modules for access. Do not add a permanent wire
between its two pads. Its two nets are intentionally separate.

## Underside conductors

Every row below is one electrically continuous net. Solder at **every** listed
hole; keep all other passed pads and wire crossings insulated. The drawing is a
wiring schematic, not a measured cut length or proof that wire envelopes never
overlap. Dry-route, secure and inspect the actual wires. There are no bare
horizontal retained-lead bridges. Each intermediate bus window has an explicit
vertical solder joint so it reaches the board:

- Leave component leads/header tails long until the bus is fitted. At each
  intermediate component hole, retain its lead down to the bus window: 1.5 mm
  below the carrier underside for GND/SYS/SW_SYS, or 2.9 mm for signal nets.
  Solder that lead to the stripped window, then trim only the excess below it.
  The model includes these 32 retained vertical leads. If a supplied lead cannot
  reach, use a soldered sleeved extension and recheck physical clearance.
- At the seven otherwise empty terminal holes **P6, P8, R8, T6, T8, V8 and
  V10**, fit one short solid 22 AWG riser, solder it to the pad, and lap-solder
  its lower end to the same-net bus window 1.5 mm below the board underside.
  Lap-solder module/button pigtails at the named pad; do not add another wire
  through that hole. These are seven extra short wire pieces, not resistors.
- The endpoint wires already rise directly to their pads. At every joint, strip
  only the solder window and keep adjacent spans insulated. Confirm
  metal-to-metal contact before soldering and continuity afterward.
- The nominal orthogonal lanes pass between other-net pin centres. Their 0.7 mm
  lead/riser envelope has at least 0.12 mm computed clearance to the thickest
  modeled insulated lane; actual solder fillets, lead forming, insulation and
  wire crossings still require inspection. Do not leave unmapped long bare tails
  or squeeze wires against neighbouring leads.

| Wire | Net | Solder windows, in route order |
| --- | --- | --- |
| carrier-J05 | BUTTON  | K4 → L8 |
| carrier-J06 | GATE_B  | K10 → L16 → K18 |
| carrier-J07 | GATE_CW | S10 → T16 → S18 |
| carrier-J08 | GATE_G  | C10 → D16 → C18 |
| carrier-J09 | GATE_R  | G10 → H16 → G18 |
| carrier-J10 | GATE_WW | O10 → P16 → O18 |
| carrier-J11 | GND | C2 → D8 → D10 → H10 → L10 → L6 → K2 → Q4 → P8 → R8 → T8 → U8 → V8 → V10 → T10 → P10 → P18 → L18 → H18 → D18 → T18 |
| carrier-J13 | H_BASE  | C3 → D6 → C8 → R4 |
| carrier-J14 | H_COLL  | C4 → F6 |
| carrier-J25 | P_GATE  | E6 → N2 → Q2 → U2 → U5 |
| carrier-J26 | SN_BASE | J6 → K6 → K3 |
| carrier-J27 | SP_BASE | G3 → H6 → G8 |
| carrier-J28 | SP_COLL | G4 → I6 |
| carrier-J29 | START | H8 → O8 |
| carrier-J30 | START_D | N6 → N8 |
| carrier-J31 | SW_SYS  | R6 → R7 → T6 → U7 → V5 → T2 |
| carrier-J32 | SYS | G2 → G6 → P6 → P2 → T5 → V2 |

Use one insulated ground backbone with the listed solder windows. All sources,
pull-downs and module returns join it; no ground enters the LED plug. SYS and
SW_SYS also use 22 AWG. The design reserves wire centre layers at −3.1 mm
(power/ground) and −4.5 mm (signals), measured from the carrier top. The −5.3 mm
lower assembly envelope includes radius and clearance allowance. Clip lead tails
and cover joints without exceeding that envelope. Confirm clearance to the
actual tray and liner before connecting the battery.

## Module tier and pigtails

All four modules attach to removable insulating edge cradles with their PCB
undersides 12 mm above the carrier top. No long downward module headers are
specified. Remove clips and lift the tier with service slack to inspect the
carrier. No drilled module mounting holes or guessed electrical pad coordinates
are used. Labels in the table are electrical destinations; identify the actual
marked module terminal before attaching a wire.

| Module | Carrier-relative envelope XY | USB |
| --- | --- | ----- |
| ESP — ESP32-C3 SuperMini | [-1, 1, 22.5, 18] mm | right |
| CHG — UMLIFE mini USB-C charger | [1, 28.875, 18, 14] mm | left  |
| REG5 — Pololu U3V16F5 · 5 V | [1, 54, 13.1, 8.1] mm | none  |
| REG12 — Pololu U3V16F12 · 12 V  | [18, 54, 13.1, 8.1] mm | none  |

The ESP envelope is nominal for the user-selected clone and still unmeasured.
Its antenna end overhang does not prove RF clearance: identify the antenna
keepout and clear underlying copper/metal before final qualification. Charger
dimensions come from the seller and are unmeasured. Adapter outlines come from
supplier drawings. Regulator envelopes come from supplier specifications;
lead/service clearance remains a fit check.

| Carrier hole | Net | Module terminal or external endpoint |
| --- | --- | --- |
| P6 | SYS | CHG.OUT+ |
| P8 | GND | CHG.OUT- |
| R6 | SW_SYS  | REG5.VIN |
| R8 | GND | REG5.GND |
| W16 | +5V_REG | REG5.VOUT |
| T6 | SW_SYS  | REG12.VIN |
| T8 | GND | REG12.GND |
| W12 | +12V | REG12.VOUT |
| W17 | +5V_ESP | ESP.5V / VIN |
| K8 | +3V3 | ESP.3V3 |
| V8 | GND | ESP.GND |
| O8 | START | BUTTON pin1 → remote contact A |
| V10 | GND | BUTTON pin2 → remote contact B |
| W12 | +12V | LED pin1 → strip +12V |
| C6 | HOLD | ESP GPIO3 |
| K4 | BUTTON  | ESP GPIO4 |
| C16 | PWM_G | ESP GPIO5 |
| D13 | LED_G | LED.G |
| G16 | PWM_R | ESP GPIO6 |
| H13 | LED_R | LED.R |
| K16 | PWM_B | ESP GPIO7 |
| L13 | LED_B | LED.B |
| O16 | PWM_WW  | ESP GPIO10 |
| P13 | LED_WW  | LED.WW |
| S16 | PWM_CW  | ESP GPIO20 |
| T13 | LED_CW  | LED.CW |

Connect BATTERY pin 1 to **CHG.B+**, pin 2 to **CHG.B−**. The battery's factory
protection and external leads remain intact. **System GND connects to CHG.OUT−,
never CHG.B−.** Do not bridge these negative nodes, including through test
equipment or USB grounds. Check actual silkscreen and meter continuity to
identify the two positive pads; do not guess from the render. The model
deliberately assigns no physical charger pad coordinates.

CHG.OUT+ feeds SYS. The parallel P-MOSFET latch feeds both regulator inputs;
REG5 and REG12 outputs remain separate. The charger has no selected pack sensor
or automatic charging lockout. Do not apply previous BQ25185 TH, jumper,
charge-current or timer instructions to it.

UUV senses **SW_SYS** at R7 and sinks **H_BASE** at R4 during undervoltage. Its
ground is Q4. CUV is a nonpolar 100 nF ceramic capacitor between U7 and U8;
either capacitor orientation is electrically valid. Use short insulated
supply/ground branches to the supervisor, without changing the named nets.
Verify actual capacitor body fits the 5 × 3 × 5 mm reservation.

## Three detachable plugs

The kit is described as XH 2.54 mm; genuine JST XH is 2.5 mm. Use matched halves
and contacts from the same kit. Housing appearance is not proof of pitch, mating
compatibility or contact/wire current rating. Contact numbers below are this
project's convention: looking into the board-side mating opening, latch/key up,
count left to right. The opposite face is mirrored. Check mating contacts with a
meter before powering.

| Plug | Project contact order |
| --- | --- |
| BATTERY 2 | 1 protected pack positive / CHG.B+; 2 protected pack negative / CHG.B− |
| BUTTON 2  | 1 START / O8; 2 GND / V10; normally-open switch |
| LED 6 | 1 +12V / W12; 2 G / D13; 3 R / H13; 4 B / L13; 5 WW / P13; 6 CW / T13  |

No ground wire or split-positive splice belongs in the LED plug. Its positive
contact carries the total channel current. Label both halves of BATTERY and
BUTTON and keep them physically distinct to prevent interchanging two 2-pin
plugs.

The user authorized replacing the factory battery connector only. Preserve
factory leads, protection and pouch. Work on **one conductor at a time**: finish
and insulate its contact before cutting the other wire. Use contacts suited to
the actual wire, recessed contacts on the battery side, correct crimp tooling
and strain relief. Verify polarity with a meter before mating. The battery
listing's 1C claim does not qualify the original wires or new contacts.

## Unpowered checks and first power

1. Unplug battery, both USB ports, LED plug and module pigtails; remove JSV.
   Verify isolated blank pads and the adapter mapping before population. With
   parts installed, check every conductor's listed pads are continuous. Use
   resistance/diode readings where components are present: MOSFET body diodes
   and resistors mean a continuity beep alone is not a short diagnosis.
2. Confirm W16 and W17 have no copper connection with JSV removed. Neither may
   have a copper short to W12 (+12 V), SYS, SW_SYS or ground. Check each
   PWM-to-gate path contains its 100 Ω resistor, each gate-to-ground path its 10
   kΩ resistor, and each drain remains distinct from other channels.
3. Confirm START O8 is separate from BUTTON K4. The remote switch closes O8 to
   V10 only when pressed. No raw supply/START conductor touches an ESP signal
   pad. Confirm DSTART orientation and each transistor role.
4. Initially leave charger/cell disconnected and substitute a current-limited
   supply at SYS P6 / GND P8. Begin without LEDs, test latch and regulator
   rails, then attach ESP through JSV. Record startup, radio transients and
   shutdown. Follow the detailed acceptance table in the electrical plan.
5. Before any ESP USB connection, disconnect the battery and charging USB,
   remove JSV, and verify it is removed. Then connect ESP USB for programming.
   USB boot asserts HOLD and can energize the 12 V branch if the battery or
   charging supply remains connected, even with JSV removed. Unplug ESP USB
   before refitting JSV and restoring battery power. Clone reverse-power
   isolation is not assumed.
6. At 4.2, 3.7 and 3.3 V bench input, hold the startup button for about one
   second, then release. UUV keeps the hold transistor disabled for 130–270 ms
   after its supply recovers. A short tap may therefore fail to latch. Sweep the
   loaded SW_SYS rail down slowly: the specified falling threshold is
   **3.0184–3.1416 V**. Record actual shutdown voltage, rail collapse, and no
   repeated restart after rebound. A button held down bypasses the cutoff;
   release it if the device will not remain on, and recharge instead of
   repeatedly restarting. These are required physical tests, not reported
   results.
7. Identify the charger's actual IC, pads and charge-setting resistor. The
   seller claims 1 A charging; this has not been verified and is not a
   demonstrated permitted charge rate for the pack. Use a sink-capable battery
   simulator for charger tests; a source-only supply must not absorb charging
   current. Check termination, recharge, temperature and operation with the
   intended USB cable/source before using the pack.
8. **Fully switch off, release the button, and verify shutdown before plugging
   in charging USB. Do not press the button or use the light while charging.**
   Black LEDs alone do not establish shutdown; both regulated rails must be off
   in the bench check. There is no hardware lockout. Unplug charging USB before
   turning the device on.
9. Until the pack's charge limits and actual board temperatures are qualified,
   charge **open-case, supervised, with pack temperature independently monitored
   at 15–30°C**. Stop outside that range. No pack temperature sensor or
   thermal-charge inhibit is fitted; no unattended or enclosed charging is
   qualified. The former BQ25185 250 mA and six-hour timer claims do not apply
   to this module.
10. Measure battery current with the latch off, both without charging USB and
    with it connected, near full charge and near cutoff. Charger/protector
    current and possible indicator glow remain unmeasured. Do not assume zero
    standby current or a particular storage life. Leave its components fitted.

The generated report checks declared wiring and nominal clearances only. No
assembled current capacity, charging behavior, thermal limit, low-battery
cutoff, radio performance or optical calibration has been measured here.

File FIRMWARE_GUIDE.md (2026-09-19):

# R6 firmware — C3 SuperMini

Use this firmware with the R6 carrier only. Its button input is digital active
LOW and its HOLD output is active HIGH. The historical R5 battery-divider button
wiring is incompatible.

## Pins

| C3 label | Connect to |
| --- | --- |
| 5V | REG5 regulated output through the removable service link |
| GND | Common system ground |
| 3V3 | Button sense pull-up only; never battery positive |
| GPIO3 | HOLD resistor → QH base |
| GPIO4 | Isolated QSN collector / button sense |
| GPIO5 | Green gate resistor |
| GPIO6 | Red gate resistor |
| GPIO7 | Blue gate resistor |
| GPIO10 | Warm-white gate resistor |
| GPIO20 | Cool-white gate resistor |

Use the module's printed labels to identify pins. Do not count pins from a
mirrored underside picture. The carrier guide gives the matching perfboard holes.

## Flash and start

1. Disconnect the battery and charging USB. Remove the REG5-to-ESP 5V service
   link before connecting a computer to the ESP USB. This avoids joining two
   supplies through an unidentified clone's USB/VIN circuit.
2. Unzip `electronics/dark-moth-r6-firmware.zip`. Keep every `.h` file beside
   `dark_moth_ble_v3.ino` in the `dark_moth_ble_v3` folder.
3. Compile for the C3 with USB CDC enabled. Arduino ESP32 core 3.3.8 is the
   build environment used for this release.

   ```sh
   arduino-cli compile --fqbn esp32:esp32:esp32c3:CDCOnBoot=cdc dark_moth_ble_v3
   arduino-cli upload --fqbn esp32:esp32:esp32c3:CDCOnBoot=cdc -p YOUR_PORT dark_moth_ble_v3
   ```

4. Disconnect the computer USB before restoring the service link. Complete the
   electrical guide's current-limited bring-up before installing the battery.
5. With charging USB disconnected, hold the side button for about one second
   to allow controller startup and the voltage supervisor’s release delay, then
   release. The initial press is consumed. The light starts off; a subsequent short tap turns it on.

## Charging is a complete shutdown

Hold the button for two seconds, wait for the red cue and release **before**
connecting the charger USB. Leave the button alone until charging USB is
unplugged. A short tap or the Bluetooth power-off value turns the LEDs black
but leaves the controller powered; neither is the charging shutdown.

The firmware does not detect charger USB or automatically inhibit startup.
The user-selected smaller charger is used only with the whole device off.
Follow [CARRIER_GUIDE.md](CARRIER_GUIDE.md) for its distinct B− and OUT− nodes,
first-charge checks and the hardware voltage-supervisor behavior.

## Controls and limits

- Tap for up to 0.5 seconds to toggle the light while leaving Bluetooth available.
- Hold for 2 seconds for the red cue, then release to shut the device off.
- Five minutes with the light off and no phone connected also shuts it off.
- The simple latch cannot force a crashed MCU off; the accessible battery plug
  is the service disconnect. Charging USB must also be removed for full isolation.
- A USB-powered board can remain alive after shutdown. The firmware leaves HOLD
  LOW and the LEDs off; reset it to restart a USB-only bench session.
- Battery telemetry is unavailable. No unpowered GPIO is connected to a raw-cell
  divider. A separate voltage supervisor controls the low-battery latch cutoff;
  the charger and pack protection remain separate from that operating cutoff.
- 2 kHz / 14-bit PWM describes the requested digital signal. Minimum reliable
  brightness and optical color accuracy still require measurements on R6.
- White mixing uses the strip's nominal 2700–6500 K endpoints and an unmeasured
  mired crossfade. No new calibration or measured color accuracy is claimed.

The existing Bluetooth service and characteristic UUIDs and serial commands are
retained. `electronics/firmware-builds.json` records the actual compilation and
host-test results. No firmware has been uploaded or physically tested by this
design process.

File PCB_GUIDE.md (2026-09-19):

# Dark Moth R6 — assemble the one-board device

**R6 prototype / physical verification pending.** This is the current build. Use the **18-column × 24-row isolated-pad carrier**, with rows A–X. No manufactured PCB with built-in copper tracks is required. The older R5 KiCad board, MT3608 supply, TO92 MOSFET circuit and OUT+/BTN_N button wiring are incompatible with this revision.

[Open the complete carrier in 3D](perfboard.html?board=carrier#workbench) · [Detailed carrier instructions](CARRIER_GUIDE.md) · [Firmware and USB procedure](FIRMWARE_GUIDE.md) · [Current print instructions](print.html)

## Start with the parts and connections

The carrier contains 33 component assemblies and four purchased modules: **ESP32-C3 SuperMini**, **UMLIFE 18 × 14 × 5 mm mini USB-C charger**, **Pololu U3V16F5 regulated 5 V supply**, and **Pololu U3V16F12 regulated 12 V supply**. The 5 V and 12 V positive rails never join. The battery, remote button and LED strip stay outside the carrier on three detachable cable plugs.

Use the [current shopping list and ordered checks](perfboard.html?board=carrier#carrier-shopping). Fit only the specified packages: the five LED MOSFETs and the two parallel high-side MOSFETs use sourced **SOT23 adapter boards**, not the earlier TO92 packages. The interactive inspector names each adapter role, each component leg, and its exact carrier hole.

[Component-side hole map](electronics/perfboard-carrier-top.svg) · [Mirrored solder-side hole map](electronics/perfboard-carrier-bottom.svg) · [Module pad labels and cables](electronics/perfboard-carrier-modules.svg) · [Component CSV](electronics/perfboard-components.csv) · [Connection CSV](electronics/perfboard-connections.csv)

## Read a connection before soldering it

The green board has isolated copper pads. Two parts do not connect merely because they are near each other. Put each component leg into its named hole; then add the specified insulated wire underneath. A wire's list of **joined holes** names every place that needs a solder joint, including intermediate joints. Leave insulation intact at all other crossings.

All points named **GND** share one electrical net, but each needs an actual solder joint to the ground conductor. Route the LED/regulator power return to the supply-ground junction without passing its current through the ESP's small return lead. System **GND connects to CHG OUT−**. The protected battery pack's external negative connects only to **CHG B−**. Do not bridge B− to OUT−: that would bypass the charger board's protection. Never bypass the pack's own protection to raw cell negative.

Each of the five LED channels keeps its **own 100 Ω gate resistor and 10 kΩ gate pulldown**. Do not share one resistor across several gates. Each channel return remains separate until its own MOSFET switches it to ground. The LED connector has one common +12 V contact and five separate channel-return contacts; it has no direct GND contact.

Module labels such as `ESP GPIO5`, `CHG.OUT+` and `REG12.VOUT` identify electrical destinations. The dashed 3D module callouts are not measured header locations. Match the printed label on your actual module and leave enough pigtail slack to lift the removable tier.

## Build and check one prototype

1. Mark A1 on the actual board. Check 2.54 mm pitch, isolated pads and cut edges. Match the front and mirrored rear maps to the same physical holes.
2. Place the components using the interactive sequence. Verify every adapter role and actual transistor lead assignment. DSTART's stripe faces **N6**. Inspect each solder joint before covering it with a module.
3. Add every internal conductor and every named intermediate joint. Check continuity within each net and check for unintended bridges between nets, particularly the different positive rails.
4. Mount the four modules on the insulating removable tier, with the ESP's long headers removed or unfitted. Wire the 18 module pigtails to the actual printed labels. Connect the battery to CHG B+/B− as shown in the module sheet; keep its negative separate from system OUT−.
5. Assemble the three matched connector pairs using the numbered face diagrams in the workbench. The button closes **START to GND**. Verify mating-contact continuity and polarity with a meter before connecting a battery or USB.
6. Follow the [ordered bring-up checks](perfboard.html?board=carrier#carrier-bringup). Remove the **JSV service shunt at W16/W17 before connecting ESP USB**, and follow the [firmware guide](FIRMWARE_GUIDE.md). Confirm the regulated 5 V and 12 V supplies before connecting their loads.
7. Qualify one current-limited prototype before making a batch: check startup, shutoff, each LED channel, maximum-current behavior, temperature, charging and physical clearances. Software checks and nominal geometry do not establish these results.

The **UUV voltage supervisor** uses its own SOT23 adapter with GND, RESET and VDD roles; it is not a MOSFET. Its reset output releases the latch at low supply voltage. Fit the nearby **CUV 100 nF non-polar capacitor** exactly as the hole map shows. The cutoff is not a charging interlock: a held START button can bypass the latch cutoff until released. Verify cutoff behavior on the first prototype.

## Charging with the whole device off

Shut the whole device down before connecting USB to the UMLIFE charger. Setting all LED channels to black leaves the controller powered and is not shutdown. Leave the device off throughout charging, then unplug charger USB before switching it on. This build has no automatic USB interlock or qualified simultaneous charging and operation. Follow the [charger checks](CHARGER_REVIEW.md) before charging the first prototype.

## Battery connector and enclosure

The main pack is the protected **67 × 36 × 10 mm 1S battery**; the optional insert supports the smaller **42 × 25 × 10 mm** pack. Preserve the pack's protection and replace its factory connector only **one insulated conductor at a time**. Finish and insulate the first contact before exposing the second; use recessed battery-side contacts and verify polarity with a meter. Follow the complete connector procedure in the [carrier guide](CARRIER_GUIDE.md).

The kit is labeled XH 2.54 mm; its exact fit and current rating remain unmeasured. Use matched parts from that kit and do not assume another XH-style kit intermates. The current printed case and module mounts are R6 prototype geometry. Measure your actual battery, modules, plugs and diffuser, then confirm fit and electrical checks before closing the case.

[Inspect the complete R6 assembly](index.html?mode=exploded#explore) · [Return to the exact-hole workbench](perfboard.html?board=carrier#workbench)

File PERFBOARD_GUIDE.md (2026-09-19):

# Earlier perfboard layouts

**Historical R5 layouts — do not build these as R6.** Their circuit, modules, button wiring and firmware differ from the current device. Use the [R6 carrier workbench](perfboard.html?board=carrier#workbench), [current assembly overview](PCB_GUIDE.md), and [carrier instructions](CARRIER_GUIDE.md). These older maps are retained only to identify earlier prototypes.

For the **18 × 24 carrier with ESP, charger and boost mounted on it**, use [the carrier guide](CARRIER_GUIDE.md). The layouts below keep those modules separate and have different hole coordinates.

# Dark Moth — fewer wires, one shared perfboard

The **combined board** puts the nine power/button-latch parts and fifteen LED-driver parts on one blank green board. The latch uses **13 existing component leads as connections**. The complete combined board needs **15 insulated links and one ground-bus wire**, plus the external cables to the other modules.

The layout keeps the existing circuit, resistor values and GPIO assignments. It does not combine resistors that do different jobs. The ESP, charger, boost converter, battery, LED strip and remote button remain separate modules.

**Layout revision: compact-2026-09.** These latch coordinates replace the previous 70 × 50 mm reference. Do not mix the old latch drawing with these instructions. Build one unpowered prototype first; the existing electrical limits in [the review](PERFBOARD_REVIEW.md) still need qualification before powered batch building.

## 1. Choose a board and mark its holes

[Combined board in 3D](perfboard.html?board=combined#workbench) · [Component list](electronics/perfboard-components.csv) · [Connection checklist](electronics/perfboard-connections.csv) · [Layout data](electronics/perfboard-layout.json)

| Layout | Hole grid | Component side | Solder side |
| --- | --- | --- | --- |
| **Combined latch + driver** | 24 columns, rows A–J | [Top drawing](electronics/perfboard-combined-top.svg) | [Bottom drawing](electronics/perfboard-combined-bottom.svg) |
| Compact latch only | 11 columns, rows A–J | [Top drawing](electronics/perfboard-latch-top.svg) | [Bottom drawing](electronics/perfboard-latch-bottom.svg) |
| Separate LED driver | 13 columns, rows A–E; previous driver coordinates | [Top drawing](electronics/perfboard-driver-top.svg) | [Bottom drawing](electronics/perfboard-driver-bottom.svg) |

Older project notes describe **10 × 24 hole blanks**. The combined reference uses that grid with the long edge horizontal: **A–J are rows; 1–24 are columns**. This is a documented starting assumption, not a measurement of the board in your hand. At 2.54 mm pitch, the outer hole centers span 58.42 × 22.86 mm; the actual board needs its own edge margins. The latch alone spans 25.40 × 22.86 mm between outer hole centers. Case mounting remains unverified.

1. Disconnect battery, USB and every supply. Check the blank with a meter: neighboring pads must be separate. Connected strips or groups need a different layout.
2. On the component face, mark **A1 at the upper-left hole**. Letters run downward; numbers run rightward. Mark that same physical corner underneath.
3. Flip the board like a book, keeping row A at the top. A1 is now **upper-right**. Never renumber from the back; use the solder-side drawing.
4. Choose one layout throughout. The combined board contains both circuits; do not also build the two separate boards. Combined latch holes match the compact latch; combined driver columns are the separate driver's columns **plus 11**.
5. Dry-fit the actual bodies and identify transistor pin roles before soldering. The models use nominal package dimensions and formed leads; they do not establish your manufacturer's left/middle/right pin order.

## 2. Gather the parts and keep the useful leads

| Circuit | Parts |
| --- | --- |
| Latch | QP: SS8550 PNP; QL: BS170; Db: 1N4148; Rb: 330 Ω; Rbtn: 1 kΩ; Rbe/Rgl/Rs1/Rs2: four 100 kΩ resistors |
| Five LED channels | Q1–Q5: five BS170s; Rg1–Rg5: five 100 Ω resistors; Rp1–Rp5: five 10 kΩ resistors |
| Remote button | One normally-open momentary switch, small insulating board, matched two-pin plug/socket and two-wire cable |
| Other modules | Protected TP4056 charger, MT3608 boost, ESP32-C3 SuperMini or supported S3 alternate, specified 12 V common-positive RGBWW strip and suitable 1S LiPo |

That is **six BS170s, one SS8550, one diode and sixteen resistors**, plus the switch and modules. The reference resistor bodies are ¼ W. Measure their values. Leave optional battery-sense resistors and ESP GPIO1 unconnected.

**Do not trim the 13 source leads listed in section 3.** Each becomes a connection underneath the board. Every inserted leg still gets its own hole; a shared joint is made by laying one retained lead against another lead/pad and soldering them together. Do not force multiple inserted legs into a small hole.

The longest retained-lead route is 7.62 mm. Allow approximately another 2 mm of usable tail below the seated board for forming and solder overlap; this is a design allowance, not a measured lead guarantee. If a lead is too short or too stiff, use a short insulated link on the same named route. Do not stretch a lead or repeatedly bend it at the package.

## 3. Build the compact latch with direct lead joints

These coordinates are the same on the compact latch and combined board. Identify E/B/C or D/G/S from the actual manufacturer's diagram. Form and insulate any crossed package leads above the board.

| Part | Exact holes and electrical roles | Mounting |
| --- | --- | --- |
| QP, SS8550  | E: **B2** OUT+; B: **B3** PB; C: **B4** VSW | Formed TO-92 leads  |
| QL, BS170 | D: **B7** LDRV; G: **B8** GATE; S: **B9** GND | Formed TO-92 leads  |
| Rbe, 100 kΩ | D1 OUT+ → D2 PB | Upright, body at D1 |
| Rb, 330 Ω | D3 PB → D7 LDRV | Horizontal |
| Rgl, 100 kΩ | D8 GATE → D9 GND | Upright, body at D8 |
| Rbtn, 1 kΩ  | F8 GATE → F4 BTN_DIO | Horizontal |
| Db, 1N4148  | **Striped K: H5 BTN_DIO**; unbanded A: H1 BTN_N | Horizontal |
| Rs1, 100 kΩ | J1 BTN_N → J5 SENSE | Horizontal |
| Rs2, 100 kΩ | J7 SENSE → J11 GND | Horizontal |

Horizontal parts use a 10.16 mm hole spacing. Upright Rbe and Rgl use adjacent holes; sleeve their long folded return leads above the board. Check actual body clearance, especially around adjacent parts, before soldering.

Place and solder the parts while retaining the source leads below. Then flip to the solder-side view. Bend **one existing leg per row** and solder at **every named pad** along its route. These are bare-metal connections; all traversed pads are deliberately assigned to the same net.

| Retain this existing lead | Solder-side route | Net |
| --- | --- | --- |
| Rbe end 1, at D1 | D1 → C1 → C2 → B2 | OUT+ |
| QP emitter, at B2 | B2 → A2 → A1 | OUT+ |
| Rbe end 2, at D2 | D2 → D3 | PB |
| QP base, at B3 | B3 → C3 → D3 | PB |
| QP collector, at B4 | B4 → A4 → A5 | VSW |
| Rb end 2, at D7 | D7 → C7 → B7 | LDRV |
| QL gate, at B8 | B8 → C8 → D8 | GATE |
| Rbtn end 1, at F8 | F8 → E8 → D8 | GATE |
| QL source, at B9 | B9 → C9 → D9 | GND |
| Rgl end 2, at D9 | D9 → D10 → D11 | GND |
| Rbtn end 2, at F4 | F4 → G4 → G5 → H5 | BTN_DIO |
| Db anode, at H1 | H1 → I1 → J1 | BTN_N |
| Rs1 end 2, at J5 | J5 → J6 → J7 | SENSE |

For example, **D3 joins three legs**: Rb end 1 is inserted there; QP base and Rbe end 2 bend to it underneath. **D8 joins Rgl end 1, QL gate and Rbtn end 1.** These are intended shared junctions. The resistors themselves still sit between different nets; never add a bridge across a resistor body.

Add one dedicated ground conductor:

- **Combined:** route one insulated wire J11 → C11 → C24. Strip solder windows only at **J11, H11, G11, F11, E11, D11, C13, C15, C17, C19, C21 and C24**. The five driver sources join at C13/C15/C17/C19/C21. Keep the span at I11, the corner at C11 and all other intervening pads insulated; those are not joints.
- **Latch alone:** route one insulated wire D11 → J11. Strip solder windows at **D11, E11, F11, G11, H11, I11 and J11**. I11 is the outgoing ground connection to the separate driver.

Use the selected drawing's ground-bus route and soldered taps. The bus carries the system return current; size its conductor for the measured load. Do not send boost/LED return current through a thin resistor lead. Insulate the other wires where they cross the bus. The 13 lead joints replace the previous latch's 23 individually cut jumpers; the bus remains a separate conductor.

## 4. Build the green LED channel

The combined layout moves the existing driver eleven columns to the right. The following table shows both choices explicitly:

| Component leg | Combined board  | Separate driver |
| --- | --- | --- |
| Q1 drain / gate / source  | A13 / B13 / C13 | A2 / B2 / C2 |
| Rg1, 100 Ω: body / return | D13 / D14 | D2 / D3 |
| Rp1, 10 kΩ: body / return | E14 / E13 | E3 / E2 |

Stand both resistors upright and sleeve their folded return leads. For the **combined** board:

1. The ESP green PWM wire attaches at **D13**. Its signal passes **through Rg1 to D14**.
2. Add an insulated link **D14 → B13** to Q1 gate.
3. Add an insulated link **D14 → E14** to Rp1's gate-side end.
4. Add an insulated link **E13 → C13** from Rp1's other end to Q1 source.
5. Q1 source at C13 joins the shared ground bus. Attach the strip's **G** return to **A13**, the drain.

Use the separate driver's corresponding holes if you chose that board. Keep these three links insulated: the gate path crosses the ground-bus row, and the source-to-pulldown path passes the PWM pad. Replacing them with bare straight leads would create shorts.

The circuit is `GPIO → 100 Ω → gate`, with `gate → 10 kΩ → source → GND`. The strip's common positive connects to +12 V; its channel return connects to the drain.

## 5. Repeat the other four channels

| Channel | Combined Q drain / gate / source | Combined 100 Ω body / return | Combined 10 kΩ body / return | Separate Q drain / gate / source |
| --- | --- | --- | --- | --- |
| Green, Q1 | A13 / B13 / C13 | D13 / D14 | E14 / E13 | A2 / B2 / C2 |
| Red, Q2 | A15 / B15 / C15 | D15 / D16 | E16 / E15 | A4 / B4 / C4 |
| Blue, Q3 | A17 / B17 / C17 | D17 / D18 | E18 / E17 | A6 / B6 / C6 |
| Warm white, Q4 | A19 / B19 / C19 | D19 / D20 | E20 / E19 | A8 / B8 / C8 |
| Cool white, Q5 | A21 / B21 / C21 | D21 / D22 | E22 / E21 | A10 / B10 / C10 |

Each channel gets the same three insulated links. That makes **15 separate links for five channels**. On the separate driver, one ground wire visits C2/C4/C6/C8/C10/C13; its five drawn segments are **one physical wire**. On the combined board, use the shared row-C bus from section 3 instead.

**Share the ground network, not the channel resistors.** Each channel keeps its own gate, drain, 100 Ω resistor and 10 kΩ pulldown. One shared resistor would join signals that the ESP needs to control independently. These are MOSFET control resistors, not LED current-limiting resistors.

## 6. Make the remote button cable

The button connects **OUT+ to BTN_N while pressed**. Neither button wire is ground.

1. Use a meter to find two contacts open when released and connected when pressed. Four-leg switches have permanently joined pairs; do not select one of those pairs.
2. Mount the switch on its small board. Connect those contacts through the matched two-pin plug/socket and two insulated wires.
3. Connect the board end to **A2 (OUT+)** and **H1 (BTN_N)** on either compact latch or combined board. Secure and insulate the cable so unplugging it cannot pull a solder joint.
4. Test the unplugged cable again, then check the switch's travel and height in the case.

## 7. Connect every module

Use the selected layout's **external wire table** for all holes. The combined board has no cable between a latch board and driver board: its shared bus makes that connection internally. Battery and boost-to-strip wires still bypass the perfboard as listed below.

| From | To | Purpose |
| --- | --- | --- |
| Battery positive | CHG.BAT+ | Cell charging connection |
| Battery negative | CHG.BAT− | Cell charging connection |
| CHG.OUT+ | A1 OUT+ | Protected supply into latch |
| CHG.OUT− | E11 GND | Protected system return |
| A4 VSW | BOOST.VIN+ | Switched boost power |
| A5 VSW | ESP.5V/VIN | Switched controller power |
| F11 GND | ESP.GND | Controller return |
| G11 GND | BOOST.VIN− | Boost input return |
| H11 GND | BOOST.VOUT− | Boost output reference; normally common with VIN− on this module |
| BOOST.VOUT+ | Strip +12V | Regulated LED supply, separate from the latch |
| B8 GATE | ESP latch GPIO below | Firmware keeps power on |
| J7 SENSE | ESP button ADC GPIO below | Button sensing |
| A2 OUT+ | Button plug → contact A | Remote switch supply |
| H1 BTN_N | Button plug → contact B | Remote switch return signal |
| Combined A13/A15/A17/A19/A21 | Strip G/R/B/WW/CW | Five independent switched returns |
| Latch-only I11 | Separate driver C13 | Needed only when using two separate boards |

**CHG.BAT− and CHG.OUT− must stay separate on the protected charger.** System ground begins at OUT−. Bridging it directly to battery negative bypasses protection switching.

Use one matching ESP column for the entire build:

| Signal | ESP32-C3 GPIO | ESP32-S3 GPIO | Combined hole | Separate-board hole |
| --- | --- | --- | --- | --- |
| Latch hold | 3 | 9 | B8 | Latch B8 |
| Button ADC | 4 | 8 | J7 | Latch J7 |
| Green PWM | 5 | 5 | D13 | Driver D2 |
| Red PWM | 6 | 4 | D15 | Driver D4 |
| Blue PWM | 7 | 6 | D17 | Driver D6 |
| Warm-white PWM | 10 | 10 | D19 | Driver D8 |
| Cool-white PWM | 20 | 11 | D21 | Driver D10 |

Keep power wiring short and sized for the actual measured load. Keep 12 V away from ESP and latch terminals. Do not carry LED current through the button cable or a resistor lead. Never connect the cell directly to ESP.3V3; identify the actual regulator before approving VSW at its VIN input.

## 8. Check one build before making copies

1. **Unpowered, check every named joint.** Probe every pad listed for each retained lead or bus: they must have direct continuity. For insulated links, probe both ends. Inspect neighboring pads and crossings for accidental solder bridges.
2. Check all driver sources and pulldown ground ends reach the dedicated ground bus and CHG.OUT−. Check each gate stays on its own channel. No drain should have a soldered bypass to ground. Through a resistor, use resistance mode rather than assuming a continuity beeper means a direct wire.
3. Confirm Db's stripe, transistor roles, retained-lead lengths, shared joints D3/D8/D9, the remote switch and the two separate charger negative connections. Photograph both sides with all joints visible.
4. Flash the [supplied firmware](electronics/dark-moth-r5-firmware.zip) for the chosen ESP with the external power harness disconnected. It uses ADC button sensing and leaves battery telemetry disabled.
5. Qualify **one powered prototype** using the [measurement sequence](PERFBOARD_REVIEW.md#qualify-one-prototype): latch/controller first, then boost set to 12.0 V, then individual LED channels and total load. Hold the button through cold boot; shutdown finishes after a long hold is released.
6. Copy the build only after its actual parts, cold start, current and temperatures pass that review. Measure the finished board and insulate its underside before deciding how to mount it in the case.

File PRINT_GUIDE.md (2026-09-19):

# Print the Dark Moth R6 case

**Body, button and carrier tray require supports.** Keep every supplied print
orientation. The portable 3MF contains geometry only; it does not enable supports.

[Download the R6 print pack](dark-moth-r6-print-pack.zip) ·
[Inspect the assembly](index.html?mode=inside#explore) ·
[Review all 17 printable parts](PRINTABILITY.md)

This is a nominal prototype. Confirm the actual perfboard outside dimensions,
charger, connector housings, battery and acrylic before printing fitted fixtures.
An 18 × 24 hole count does not establish the blank's outside size.

## 1. Open the reference projects

Support-bearing Bambu reference projects are provided for:

- [Body](profiles/body-p1s-petg.3mf)
- [Button](profiles/button-p1s-petg.3mf)
- [Carrier tray](profiles/carrier_tray-p1s-petg.3mf)

Open each **as a project**, keeping its settings. These unsliced references use
P1S, a 0.4 mm nozzle, Generic PETG and Textured PEI. Select your actual printer,
nozzle, plate and filament before slicing, then recheck the support settings.
Each project was reopened in an isolated slicer and generated real supports
from its embedded settings. No sliced machine G-code is included.

For another slicer, import the individual STLs in their supplied orientations
and use these reference process settings:

| Setting | Value |
| --- | --- |
| Layer / first layer | 0.20 / 0.20 mm |
| Wall loops | 4 |
| Top / bottom shell layers | 6 / 6 |
| Infill | 20%, gyroid |
| Supports on body, button, carrier tray | On |
| Support type | Normal (auto)  |
| On build plate only | Off |
| Critical regions only | Off |
| Threshold angle | 30° |
| Don't support bridges | Off |

Use the filament manufacturer's temperatures. Enable Advanced controls if a
setting is hidden. After changing presets, inspect Preview with support/line-
type colouring. Check actual support paths under the charger-window roof, LED
wire passages, side-button cradle, button flange and tray's retaining lips.
A disappearing warning alone does not prove that support material exists.
Supports must remain accessible for removal before electronics are installed.

## 2. Print the coupon first

[Coupon](prints/coupon.stl) prints **moth-down, slot banks up**, matching the lid's
0.5 mm bed-facing recess. Leave its supports off. Use the intended lid material,
plate and layer settings, then inspect the underside after cooling. Fine webs
between the original 44 facets can merge with a 0.4 mm nozzle; inspect the sliced
first layers and the real coupon before printing the full lid.

With the slot banks nearest you, viewed from above, their widths are
**3.2 / 3.4 / 3.6 mm**, left to right. Test a deburred corner of the actual
3 mm acrylic. The case uses a 3.4 mm channel, giving 0.4 mm total nominal
clearance. Confirm sliding fit before cutting the 104 × 28 × 3 mm smoked sheet.

## 3. Print each part in its supplied orientation

<!-- markdownlint-disable MD013 -->

| Part | Bed face | Supports / first-print check |
| --- | --- | --- |
| [Body](prints/body.stl) | Exterior floor; cavity up | **Required.** Clear window, cradle and internal roofs. |
| [Lid](prints/lid.stl) | Moth / outside face down  | Off. Inspect coupon and fine moth details. |
| [Front rail](prints/rail.stl) | Outside face down | Off. Inspect long footprint and acrylic keeper. |
| [Button](prints/button.stl) | Visible key face down | **Required.** Clean the flange and check free return. |
| [Switch carrier](prints/switch_carrier.stl) | Flat back down | Off. Check daughterboard retaining lips. |
| [Coupon](prints/coupon.stl) | Moth down; slot banks up  | Off. Check real acrylic thickness. |
| [Diffuser template](prints/diffuser.stl) | Broad face down | Off. Optional template; use smoked acrylic for the diffuser. |
| [Carrier tray](prints/carrier_tray.stl) | Broad underside down | **Required.** Clean the board ledges, wire ports and retaining lips. |
| [Carrier keeper](prints/carrier_keeper.stl) | Flat keeper face down | Off. Check screw bores and rear board capture. |
| [Module tier](prints/module_tier.stl) | Open frame underside down | Off. Inspect rims, keepers and small pilot bores. |
| [ESP clamp](prints/clamp_esp.stl) | Broad underside down | Off. Preserve the USB clearance notch. |
| [Charger clamp](prints/clamp_charger.stl) | Broad underside down | Off. Fits the nominal 18 × 14 mm UMLIFE seat. |
| [5 V clamp](prints/clamp_reg5.stl) | Broad underside down | Off. Check small holes without splitting the plastic. |
| [12 V clamp](prints/clamp_reg12.stl) | Broad underside down | Off. Keep distinct from the other module fixtures. |
| [Connector saddles](prints/connector_saddles.stl) | Broad underside down | Off. Clear strap slots and pack-lead notches. |
| [Battery bridge](prints/battery_bridge.stl) | Roof down; legs up | Off. Keep this orientation so its bores print vertically. |
| [Small-pack insert](prints/battery_insert.stl) | Broad underside down | Off. Optional; remove for the 67 × 36 × 10 mm battery. |

<!-- markdownlint-enable MD013 -->

The black portable plate contains 16 separate objects, including the coupon and
optional small-pack insert. The diffuser template has its own plate. Enable
supports per object on **body, button and carrier tray only**. Printing parts
separately is the clearest first-build workflow. Avoid automatic reorientation.

## 4. Remove supports and dry-fit

Let the parts cool, then remove supports before installing electronics. Access
the body through its cavity, the single charging-USB opening and the side-button
cradle. Clean the tray's lips and wire passages from its open sides. Avoid
levering against thin ribs, acrylic channels or screw posts.

Clear debris from grooves and pilots. Reject cracked posts or distorted slots.
Test button press and complete release, the daughterboard capture, and acrylic
removal with the front rail off. Fit the tray to the actual blank before soldering.
Inspect module edge lands for pads or components where the clamps will bear.
Do not compress the battery pouch with its bridge or screws.

Follow [Build in this order](README.md#build-in-this-order) and the
[current carrier guide](CARRIER_GUIDE.md). Fit the side-button carrier before the
rear connector saddles. The case's left port is charging USB; ESP programming
USB is accessed with the lid removed and the service shunt removed.

The UMLIFE charger is used with the **complete device off while charging**.
Turning LEDs black is not the same as switching the device off. Follow the
[current charging procedure](README.md#charge-with-the-device-off).

## What has been checked

All 17 meshes have one connected solid, a connected first layer and warning-free
reference slices. The three native support projects were also round-trip sliced.
[Printability](PRINTABILITY.md) and [Verification](VERIFICATION.md) record the
scope. These checks do not establish support removal, surface finish, screw grip,
acrylic fit, button feel, operating temperature or electrical safety of actual
stock. No physical print has been performed or printer contacted.

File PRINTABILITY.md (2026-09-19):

# Dark Moth R6 — printability review

All 17 exports were checked in their supplied print orientations and actually
sliced with Bambu Studio 02.08.02.61. **Body, button and carrier tray require
normal automatic supports everywhere, including bridges.** The other fourteen
exports sliced without supports and without warnings.

The portable `black-parts.3mf` contains 16 arranged objects and no printer,
filament or process presets. The separate diffuser plate is an optional cutting/
fit template. Use the [print guide](PRINT_GUIDE.md), keep the supplied orientation,
and inspect real support extrusion in slicer Preview before printing.

## Current reference results

The isolated reference process uses bundled P1S / 0.4 mm / Generic PETG profiles,
0.20 mm layers, four walls, six top/bottom layers and 20% gyroid infill. Supports
are not restricted to the bed, critical-regions-only is off, the threshold is
30°, and bridges receive support. All 17 slices completed without slicing
warnings or effective-setting mismatches.

| Supported part | Support toolpath sections | Support extrusion moves |
| --- | ---: | ---: |
| Body | 201 | 5,884 |
| Button | 11 | 503 |
| Carrier tray | 118 | 2,733 |

These are sections/moves in the current reference toolpath, not counts of
separate support towers. They confirm support was actually generated. A slicer
can suppress an overhang warning merely because supports are enabled; check the
paths themselves. All three delivered native reference projects were reopened
and sliced successfully using their embedded support settings. They contain no
sliced G-code. See `build/slice/report.json` and `profiles/manifest.json`.

## Features requiring inspection

The body has one 16 × 9 mm charging-USB opening in its left wall. Its roof,
the two low LED-wire passages, and the side-button cradle/opening require
support. The open cavity and ports provide removal access before electronics
are fitted. The front light aperture remains open at the top during printing;
the separate rail supplies its lintel and retains the removable acrylic.

The tray has raised board-capture lips and side wire passages. Remove support
from these features before sliding in the actual carrier. The fitted capture
assumes a 47.78 × 63.02 × 1.6 mm blank with an 18 × 24 hole grid. The purchased
blank's outside dimensions and hole offsets remain unmeasured.

The button's flange needs support even if an unsupported preview looks
connected. Clean it completely and check free return. Its nominal travel remains
0.35 mm with a 0.10 mm initial switch gap; actual tactile-switch force and stroke
require a physical trial.

The lid and coupon share the original 44 bed-facing moth recesses, exactly
0.5 mm deep. Some fine webs are about 0.30 mm wide, so a 0.4 mm nozzle can merge
or omit detail. The coupon's actual mesh sections match the delivered lid's
recess and print orientation. Its upright 3.2 / 3.4 / 3.6 mm stock slots remain
open at the top. Inspect the coupon before cutting the 104 × 28 × 3 mm acrylic.

The module tier is one connected open frame. Four separate clamps secure the
C3, compact UMLIFE charger, and two regulator PCBs. Inspect the small pilot bores,
edge keepers and ESP USB notch. PCB edge copper, solder projections and actual
module thickness remain unverified; do not clamp an occupied solder land.

The connector saddles include removable-strap paths and two pack-lead notches.
Their housing reservations are nominal for the user's kit, not an approved
JST footprint. The battery bridge prints roof-down with legs upward and screw
bores vertical. Its former side-on orientation produced a cantilever warning;
the delivered orientation slices cleanly without support. The optional small-
pack insert is removed for the selected 67 × 36 × 10 mm pack.

## Coverage and limits

All 17 STLs are watertight, single connected solids and begin at Z=0. Actual
cross-sections at Z=0.1 show one connected first-layer region per part. Geometry
checks also cover installed-part clearances, button and diffuser motion,
carrier capture/removal, nominal module boards, screw access and plate bounds.
The [mechanical plan](PRODUCT_MECHANICAL_PLAN.md) lists exact placements and
[design review](REVIEW.md) describes the complete R6 assembly.

Passing mesh and slicing checks do not certify printed surfaces, shrinkage,
support release, screw grip, wire bend radii, purchased-part fit, battery
restraint, thermal behavior or light quality. No physical print was performed.
Print the coupon, measure actual stock and dry-fit before wiring the closed case.

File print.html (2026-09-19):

Skip to print instructions

 Dark Moth Print the case

Before you print

Keep the supplied orientation. Verify actual support paths in Preview before printing.

# Print the Dark Moth R6 case

Body, button and carrier tray require supports. Keep every supplied print orientation. The portable 3MF contains geometry only; it does not enable supports.

Download the R6 print pack · Inspect the assembly · Review all 17 printable parts

This is a nominal prototype. Confirm the actual perfboard outside dimensions, charger, connector housings, battery and acrylic before printing fitted fixtures. An 18 × 24 hole count does not establish the blank's outside size.

## 1. Open the reference projects

Support-bearing Bambu reference projects are provided for:

- Body
- Button
- Carrier tray

Open each as a project, keeping its settings. These unsliced references use P1S, a 0.4 mm nozzle, Generic PETG and Textured PEI. Select your actual printer, nozzle, plate and filament before slicing, then recheck the support settings. Each project was reopened in an isolated slicer and generated real supports from its embedded settings. No sliced machine G-code is included.

For another slicer, import the individual STLs in their supplied orientations and use these reference process settings:

Setting | Value
Layer / first layer | 0.20 / 0.20 mm
Wall loops | 4
Top / bottom shell layers | 6 / 6
Infill | 20%, gyroid
Supports on body, button, carrier tray | On
Support type | Normal (auto)
On build plate only | Off
Critical regions only | Off
Threshold angle | 30°
Don't support bridges | Off

Use the filament manufacturer's temperatures. Enable Advanced controls if a setting is hidden. After changing presets, inspect Preview with support/line- type colouring. Check actual support paths under the charger-window roof, LED wire passages, side-button cradle, button flange and tray's retaining lips. A disappearing warning alone does not prove that support material exists. Supports must remain accessible for removal before electronics are installed.

## 2. Print the coupon first

Coupon prints moth-down, slot banks up, matching the lid's 0.5 mm bed-facing recess. Leave its supports off. Use the intended lid material, plate and layer settings, then inspect the underside after cooling. Fine webs between the original 44 facets can merge with a 0.4 mm nozzle; inspect the sliced first layers and the real coupon before printing the full lid.

With the slot banks nearest you, viewed from above, their widths are 3.2 / 3.4 / 3.6 mm, left to right. Test a deburred corner of the actual 3 mm acrylic. The case uses a 3.4 mm channel, giving 0.4 mm total nominal clearance. Confirm sliding fit before cutting the 104 × 28 × 3 mm smoked sheet.

## 3. Print each part in its supplied orientation

Part | Bed face | Supports / first-print check
Body | Exterior floor; cavity up | Required. Clear window, cradle and internal roofs.
Lid | Moth / outside face down | Off. Inspect coupon and fine moth details.
Front rail | Outside face down | Off. Inspect long footprint and acrylic keeper.
Button | Visible key face down | Required. Clean the flange and check free return.
Switch carrier | Flat back down | Off. Check daughterboard retaining lips.
Coupon | Moth down; slot banks up | Off. Check real acrylic thickness.
Diffuser template | Broad face down | Off. Optional template; use smoked acrylic for the diffuser.
Carrier tray | Broad underside down | Required. Clean the board ledges, wire ports and retaining lips.
Carrier keeper | Flat keeper face down | Off. Check screw bores and rear board capture.
Module tier | Open frame underside down | Off. Inspect rims, keepers and small pilot bores.
ESP clamp | Broad underside down | Off. Preserve the USB clearance notch.
Charger clamp | Broad underside down | Off. Fits the nominal 18 × 14 mm UMLIFE seat.
5 V clamp | Broad underside down | Off. Check small holes without splitting the plastic.
12 V clamp | Broad underside down | Off. Keep distinct from the other module fixtures.
Connector saddles | Broad underside down | Off. Clear strap slots and pack-lead notches.
Battery bridge | Roof down; legs up | Off. Keep this orientation so its bores print vertically.
Small-pack insert | Broad underside down | Off. Optional; remove for the 67 × 36 × 10 mm battery.

The black portable plate contains 16 separate objects, including the coupon and optional small-pack insert. The diffuser template has its own plate. Enable supports per object on body, button and carrier tray only. Printing parts separately is the clearest first-build workflow. Avoid automatic reorientation.

## 4. Remove supports and dry-fit

Let the parts cool, then remove supports before installing electronics. Access the body through its cavity, the single charging-USB opening and the side-button cradle. Clean the tray's lips and wire passages from its open sides. Avoid levering against thin ribs, acrylic channels or screw posts.

Clear debris from grooves and pilots. Reject cracked posts or distorted slots. Test button press and complete release, the daughterboard capture, and acrylic removal with the front rail off. Fit the tray to the actual blank before soldering. Inspect module edge lands for pads or components where the clamps will bear. Do not compress the battery pouch with its bridge or screws.

Follow Build in this order and the current carrier guide. Fit the side-button carrier before the rear connector saddles. The case's left port is charging USB; ESP programming USB is accessed with the lid removed and the service shunt removed.

The UMLIFE charger is used with the complete device off while charging. Turning LEDs black is not the same as switching the device off. Follow the current charging procedure.

## What has been checked

All 17 meshes have one connected solid, a connected first layer and warning-free reference slices. The three native support projects were also round-trip sliced. Printability and Verification record the scope. These checks do not establish support removal, surface finish, screw grip, acrylic fit, button feel, operating temperature or electrical safety of actual stock. No physical print has been performed or printer contacted.

Dark Moth · R6Print files and CAD

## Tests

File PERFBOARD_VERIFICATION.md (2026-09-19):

# R6 carrier instruction verification

The current build is the **ESP32-C3 SuperMini R6 carrier**: an 18-column × 24-row isolated-pad board, 33 component assemblies, four raised purchased modules and three detachable external plugs. [CARRIER_GUIDE.md](CARRIER_GUIDE.md) gives the assembly sequence; [PRODUCT_ELECTRICAL_PLAN.md](PRODUCT_ELECTRICAL_PLAN.md) records circuit decisions and outstanding physical qualification.

The earlier latch, driver and combined-board views remain historical circuit references. They do not define the R6 build. In particular, R5 battery-negative routing, TP4056/MT3608 modules, BS170 drivers and direct battery-level button sensing must not be mixed with R6.

## One source for every hole

[electronics/perfboard-layout.json](electronics/perfboard-layout.json) records component pins, nets, modules, adapter footprints and external contacts. The interactive carrier, top/bottom worksheets and CSV exports derive from it. Hole names stay fixed when the solder-side view is mirrored.

The five MOSFET driver groups form repeated rows. Each has its own 100 Ω gate resistor and 10 kΩ pulldown. Their source legs share ground; the five drain returns remain separate. The regulated 5 V and 12 V positives remain separate. The six-pin lights plug carries +12 V, G, R, B, WW and CW. LED return contacts are switched outputs, not ground contacts.

The SOT23 devices use seven Adafruit1230 adapter boards. The power adapter holds two MOSFETs; each of the five LED adapters holds one. A separate adapter carries the TLV803EA30DBZR voltage supervisor, whose GND/RESET/VDD pins differ from MOSFET G/S/D pins. The published adapter pad map determines lead placement. Two retail packs supply the seven boards needed for one device. The remaining through-hole transistors retain explicit role labels; check the purchased manufacturer's pin order before bending their legs.

The firmware uses HOLD GPIO3, isolated active-LOW BUTTON GPIO4, and G/R/B/WW/CW GPIO5/6/7/10/20. The first power-on press is consumed. A later two-second hold arms shutdown, which occurs on release. [FIRMWARE_GUIDE.md](FIRMWARE_GUIDE.md) covers upload isolation and operation.

## Independent checks

[The electrical report](electronics/verification.json) is generated by `tools/verify_r6_electronics.py`. It checks exact component values and roles, occupied-hole ownership, net continuity, independent supply and signal nets, C3 GPIO assignments, service-shunt isolation, adapter pad mapping, nominal body clearances, module height, voltage-supervisor routing and external connector connections. Deliberate-fault tests prove that swapped adapter pins, missing returns, bridged supplies, bypassed service isolation and missing or miswired voltage supervision fail verification.

Python worksheet tests compare every leg, solder junction and terminal with canonical data. Node tests use the vendored Three.js geometry to check lead endpoints, adapter contacts, carrier state, module placement and viewer controls. They do not establish real solder clearance or supplier dimensions.

The browser test starts its own temporary HTTP server and exercises the actual GLB, repeated vertical rotation, drag release, fixed top/bottom views, component selection, cumulative assembly steps, module choices, load-error recovery, desktop/mobile layout and downloads. [The browser record](preview/site/perfboard/browser-checks.json) includes source hashes and the individual results. [R6 product evidence](preview/site/r6/browser-checks.json) covers the complete case and print guide.

## Inspect the board

- [Component side](preview/site/perfboard/carrier-top.png)
- [Solder side](preview/site/perfboard/carrier-bottom.png)
- [Angled carrier with all modules](preview/site/perfboard/carrier-angle.png)
- [Interactive workbench](perfboard.html?board=carrier#workbench)
- [Printable top worksheet](electronics/perfboard-carrier-top.svg)
- [Printable bottom worksheet](electronics/perfboard-carrier-bottom.svg)
- [Module connections](electronics/perfboard-carrier-modules.svg)

## Physical checks still required

The reports explicitly record **physical validation false**. The nominal blank is 47.78 × 63.02 mm with 2.54 mm hole pitch; an 18 × 24 hole count alone does not establish outside dimensions or edge margins. Measure the actual board before printing its fitted holder.

The C3 clone, Pololu modules, connector kit, formed leads and solder envelopes remain unmeasured. Source-derived adapter pad coordinates are distinguished from illustrative purchased-part geometry. The generic charger’s actual pad assignments and dimensions need confirmation on the purchased board. Unverified physical module pads are not assigned guessed signal names. Follow the module silkscreen and published pinout, then verify continuity before power.

The battery keeps its built-in protection. Its factory 1.25 mm plug may be replaced with the available two-pin XH-style plug one insulated conductor at a time. Project contact numbers and measured polarity define the connection; wire colors and similar-looking housings do not prove polarity or compatibility. No rating is inferred for the generic kit.

Charging uses complete manual shutdown before connecting USB; there is no automatic USB lockout or simultaneous operation. B− remains separate from OUT− system ground.

The first build requires an unpowered continuity check, current-limited rail bring-up, latch/button tests, full-load voltage and temperature measurements, standby-current measurement and an actual case fit trial. Charging is limited to the supervised open-case test conditions in the electrical guide until the pack's limits, charge current and thermal behavior are qualified. No batch-production, unattended-charge or battery-runtime claim is made by the digital checks.

## Reproduce

From the enclosure directory, using the dependencies in [README.md](README.md#reproduce):

```sh
python tools/build_perfboard_layout.py
python tools/build_perfboard_worksheets.py
python tools/verify_r6_electronics.py
python tools/build_guide.py
python -m unittest discover -s tests -p 'test_perfboard_*.py' -v
python -m unittest discover -s tests -p 'test_r6_electronics.py' -v
node --test tests/test_perfboard_carrier.mjs tests/test_perfboard_adapters.mjs tests/test_perfboard_state.mjs tests/test_perfboard_geometry.mjs tests/test_perfboard_connections.mjs tests/test_perfboard_controls.mjs tests/test_electronics_overview.mjs
node tests/test_perfboard_browser.mjs
```

The browser test requires Playwright and Chromium; `PLAYWRIGHT_MODULE` may identify an existing installation. It does not use the development or production server and does not contact hardware.

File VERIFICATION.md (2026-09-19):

# Dark Moth R6 — digital verification

R6 is a digitally checked **prototype**, built around the ESP32-C3 SuperMini, an integrated 18 × 24-hole carrier, protected 67 × 36 × 10 mm battery, removable side-button cable and six-pin LED cable. Physical fit, electrical load performance, charging and optical output are not certified by these checks.

[verification-summary.json](verification-summary.json) is the release record. It contains the geometry, parameter-variant, printability, slicing, electrical, firmware, browser and full-model results with their source hashes. Packaging refuses failed, missing or stale evidence. The exact current counts belong to that machine-readable record.

## What is checked

### Printable geometry and assembly

The canonical inventory is [cad/parts.json](cad/parts.json): 17 printable exports, including the optional small-battery insert and fit coupon. The diffuser STL is a template for the removable purchased acrylic sheet. All installed printed solids in the complete model come from the exported assembly STLs.

Geometry checks require watertight, consistently wound, positive-volume, single-component meshes and bed-aligned print orientations. Solid intersections check the printed assembly, module envelopes, battery, holder, screws, button travel and diffuser access. The original 44-facet moth is retained at 44 mm width and 0.5 mm recess depth. Sheet-thickness variants are generated separately, so their tests cannot overwrite the delivered default parts.

The case is nominally 111 × 115 × 40 mm. [The mechanical plan](PRODUCT_MECHANICAL_PLAN.md) records coordinates, fixture clearances, retention, screw locations and the remaining purchased-part measurements. In particular, the assumed carrier outline is not established by its hole count. Measure the actual blank and hole offsets before printing its fitted cassette.

### Actual slicing

Every delivered STL is sliced independently using the stated Bambu P1S / 0.4 mm / Generic PETG reference process. The report reads effective settings back from generated G-code and rejects geometry warnings. Support-required parts must generate positive support toolpaths and extrusion; merely enabling a support checkbox does not pass.

[PRINT_GUIDE.md](PRINT_GUIDE.md) gives supplied orientations and support settings. [PRINTABILITY.md](PRINTABILITY.md) describes the actual checks. [profiles/manifest.json](profiles/manifest.json) records unsliced native reference projects and isolated round-trip slices. No executable printer G-code is distributed. Reference slicing does not establish surface finish, support removal or dimensional fit on the user's printer.

### Complete 3D product

[The part catalog](preview/assembly-parts.json) identifies the printed parts, carrier, all canonical discrete assemblies, four purchased modules, battery, LED strip, side switch, external plug halves, insulation, screws, straps and routed conductors. Each item carries source and confidence information. Unmeasured module packages and connector envelopes are identified as nominal; they are not a supplier-certified inventory of every internal SMD.

Full-model tests decode the exported GLB buffers and compare them with the canonical inventory, actual printed meshes, drilled carrier grid, module placement and logical wiring. [The collision audit](tests/audit_full_assembly.py) checks solid GLB geometry against installed printed obstacles. Its record explicitly lists non-solid surfaces excluded from Boolean testing. It does not prove clearance between every pair of wires or purchased components, and it does not establish cable cut lengths or bend radii.

[The six-view render manifest](preview/render_manifest.json) hashes the actual CAD, model generators, electronics layout, GLBs, catalog and studio images. The website uses these same assets for assembled, exploded, internal and service views.

### Electrical consistency and firmware

[electronics/verification.json](electronics/verification.json) records independent checks of the R6 carrier. Tests cover exact roles and values, hole ownership, connected nets, separate regulated supplies, service-link isolation, adapter pin mapping, C3 pins, connector schedules, low-voltage supervision and nominal spacing. Deliberate-fault tests demonstrate rejection of wiring shorts and missing or misassigned connections. [PERFBOARD_VERIFICATION.md](PERFBOARD_VERIFICATION.md) describes the instruction and worksheet checks.

The R6 build uses the user-selected UMLIFE mini charger with complete shutdown during charging, separate regulated supplies and a voltage-supervised MOSFET latch. [PRODUCT_ELECTRICAL_PLAN.md](PRODUCT_ELECTRICAL_PLAN.md) identifies required parts and the reasons for the change. Older KiCad and historical perfboard drawings are retained as source history and do not define this build.

[electronics/firmware-builds.json](electronics/firmware-builds.json) records actual ESP32-C3 and optional ESP32-S3 compilations with Arduino-ESP32 3.3.8. Native C++ tests execute the real button/power code for cold-start release, debounce, short and long gestures, timer wraparound, shutdown on release, LED feedback, idle behavior and permanent HOLD-low shutdown. No board was flashed or bench-tested by these tools. The selected product is the C3.

The firmware ZIP contains the exact compiled source. Packaging requires the complete core source inventory and rejects missing, extra or changed source files, including nested sketch sources. Battery telemetry remains unavailable because R6 has no validated battery-sense circuit. Nominal white-channel blending is not a measured optical calibration.

### Website and delivery

[The browser record](preview/site/r6/browser-checks.json) covers actual WebGL rendering on a temporary test server, desktop/mobile layouts, whole-product modes, independent part inspection, carrier placement, drag-release stability, full vertical rotation, hole/pin instructions, module choices, load recovery and downloads. The matching [perfboard record](preview/site/perfboard/browser-checks.json) contains the same final run. Every check is tied to the tested source hashes.

Publication uses an explicit file allowlist, rejects missing or unsafe files, resolves local links, and writes a deployment manifest containing every served asset's SHA-256. The live-delivery check compares fetched bytes with that manifest. A passing deployment check proves delivery of the reviewed bytes, not hardware function.

## Reproduce

Use the dependencies in [README.md](README.md#reproduce). From the enclosure directory:

```sh
python tools/build_perfboard_layout.py
python tools/build_perfboard_worksheets.py
python tools/verify_r6_electronics.py
python tools/build_firmware.py
python tools/build.py
python tests/verify.py
python tests/verify_variants.py
python tests/test_printability.py
python tools/slice_check.py
python tools/build_print_project.py
python tools/build_guide.py
/Applications/Blender.app/Contents/MacOS/Blender --background --python tools/render.py
python tests/test_full_assembly.py
python tests/audit_full_assembly.py
node tests/test_perfboard_browser.mjs
python tools/package.py
python -m unittest discover -s tests -p 'test_*.py' -v
```

The build tools never upload firmware to a board or send a print job. Browser and deployment tests use their own temporary server and staging directory. Physical first-build checks, charging restrictions and outstanding component measurements remain in the assembly guides.

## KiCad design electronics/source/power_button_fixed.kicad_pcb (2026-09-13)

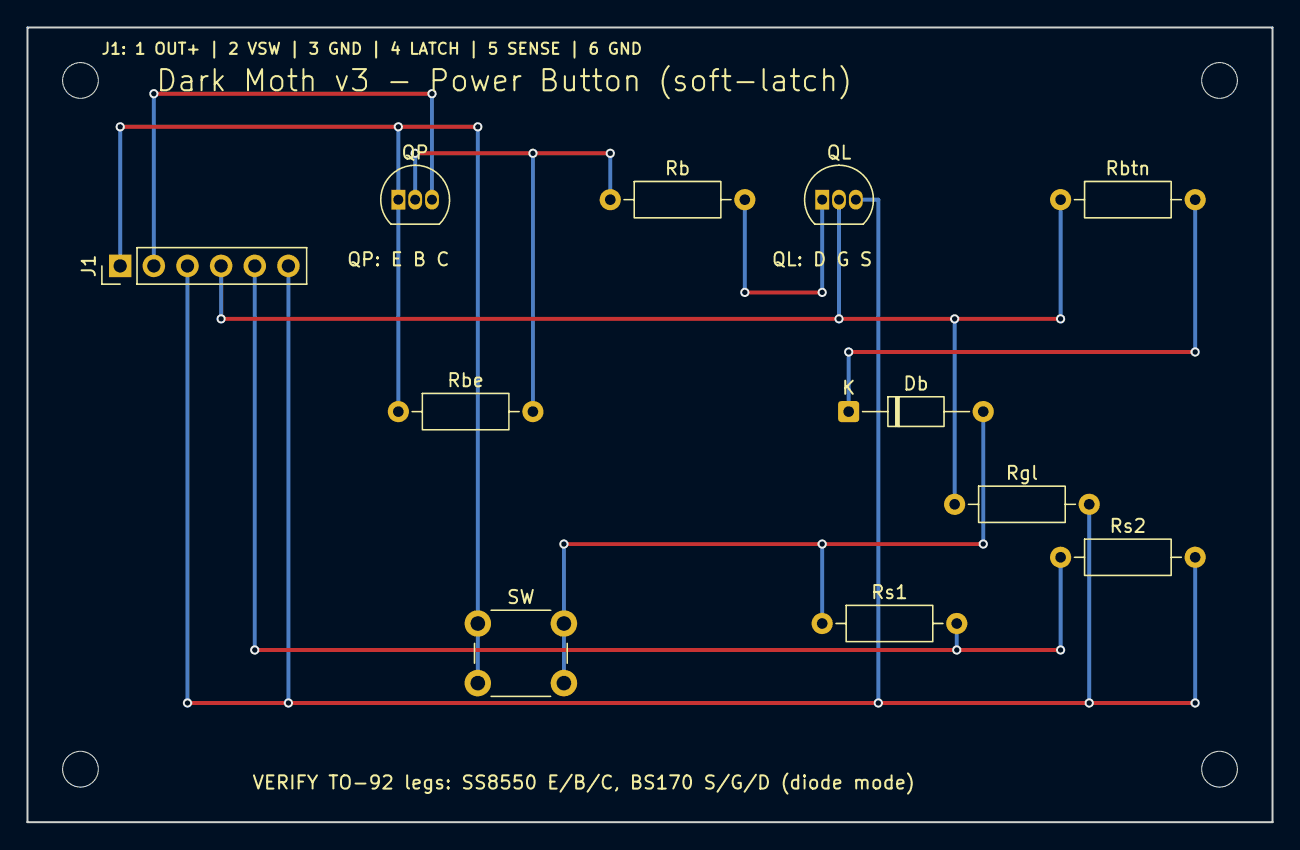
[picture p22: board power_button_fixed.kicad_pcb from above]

Board: 2 copper layers, 94.0 x 60.0 mm, 15 parts (0 on the bottom side), 9 nets.

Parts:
Db: 1N4148; D_DO-35_SOD27_P10.16mm_Horizontal
H1, H2, H3, H4: M2.5; MountingHole_2.7mm
J1: OUT+/VSW/GND/LATCH/SENSE/GND; PinHeader_1x06_P2.54mm_Vertical
QL: BS170; TO-92_Inline
QP: SS8550; TO-92_Inline
Rb: 330; R_Axial_DIN0207_L6.3mm_D2.5mm_P10.16mm_Horizontal
Rbe: 100k; R_Axial_DIN0207_L6.3mm_D2.5mm_P10.16mm_Horizontal
Rbtn: 1k; R_Axial_DIN0207_L6.3mm_D2.5mm_P10.16mm_Horizontal
Rgl: 100k; R_Axial_DIN0207_L6.3mm_D2.5mm_P10.16mm_Horizontal
Rs1, Rs2: 100k; R_Axial_DIN0207_L6.3mm_D2.5mm_P10.16mm_Horizontal
SW: PWR; SW_PUSH_6mm

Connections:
BTN_DIO: Db.1, Rbtn.2
BTN_N: Db.2, Rs1.1, SW.1, SW.2
GATE: J1.4, QL.2, Rbtn.1, Rgl.1
GND: J1.3, J1.6, QL.3, Rgl.2, Rs2.2
LDRV: QL.1, Rb.2
OUT+: J1.1, QP.1, Rbe.1, SW.1, SW.2
PB: QP.2, Rb.1, Rbe.2
SENSE: J1.5, Rs1.2, Rs2.1
VSW: J1.2, QP.3

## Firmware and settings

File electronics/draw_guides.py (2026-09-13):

#!/usr/bin/env python3
"""Draw diagrams from the reviewed manifest; no CAD or purchased-part measurements implied."""

import html
import json
from pathlib import Path

ROOT = Path(__file__).resolve().parent
assembly = json.loads((ROOT / "assembly.json").read_text())
pad_rows = json.loads((ROOT / "pcb-pads.json").read_text())["pads"]
wiring = json.loads((ROOT / "interconnects.json").read_text())
COLORS = {
    "OUT+": "#b74623",
    "VSW": "#ae5811",
    "GND": "#254854",
    "GATE": "#824ab4",
    "SENSE": "#007c9e",
    "BTN_N": "#bc3458",
}


def text(x, y, label, size=16, color="#223840", anchor="start"):
    return f'<text x="{x}" y="{y}" fill="{color}" font-size="{size}" text-anchor="{anchor}">{html.escape(str(label))}</text>'


def rect(x, y, w, h, fill="#fff", stroke="#c2cecf", radius=8):
    return f'<rect x="{x}" y="{y}" width="{w}" height="{h}" rx="{radius}" fill="{fill}" stroke="{stroke}" stroke-width="2"/>'


def line(points, color="#60757c", width=3):
    return f'<polyline points="{points}" fill="none" stroke="{color}" stroke-width="{width}"/>'


def save(name, width, height, content, title):
    svg = f'<svg xmlns="http://www.w3.org/2000/svg" viewBox="0 0 {width} {height}" role="img" aria-labelledby="title"><title id="title">{html.escape(title)}</title><g font-family="Arial,Helvetica,sans-serif">{rect(0, 0, width, height, "#f5f3eb", "#f5f3eb", 0)}{"".join(content)}</g></svg>\n'
    (ROOT / name).write_text(svg)


def placement():
    parts = [
        text(50, 48, "R5 · CORRECTED POWER-LATCH PCB", 27),
        text(
            50,
            78,
            "Component side • 94 × 60 mm • coordinates from upper-left board edge",
            17,
        ),
    ]
    x0, y0, scale = 50, 120, 9
    parts += [rect(x0, y0, 94 * scale, 60 * scale, "#dae6d8", "#77957a", 6)]
    for comp in assembly["components"]:
        ref = comp["ref"]
        cx, cy = comp["center_mm"]
        x, y = x0 + scale * cx, y0 + scale * cy
        if ref.startswith("H"):
            parts += [
                f'<circle cx="{x}" cy="{y}" r="12" fill="#f5f3eb" stroke="#587361"/>',
                text(x, y - 19, ref, 12, anchor="middle"),
            ]
            continue
        if ref.startswith("R") or ref == "Db":
            rows = [p for p in pad_rows if p[0] == ref]
            parts += [
                line(
                    f"{x0 + scale * rows[0][3]},{y} {x0 + scale * rows[1][3]},{y}",
                    "#657875",
                    4,
                )
            ]
            w = 56 if ref.startswith("R") else 36
            parts += [
                rect(
                    x - w / 2,
                    y - 10,
                    w,
                    20,
                    "#86b8c7" if ref.startswith("R") else "#d59b70",
                    "#55737a",
                    4,
                )
            ]
            if ref == "Db":
                parts += [rect(x - w / 2 + 4, y - 10, 5, 20, "#2b3336", "#2b3336", 0)]
        elif ref in ("QL", "QP"):
            parts += [rect(x - 22, y - 28, 44, 31, "#333d43", "#24323c", 10)]
        elif ref == "J1":
            parts += [rect(x - 74, y - 11, 148, 22, "#374850", "#293b40", 2)]
        else:
            parts += [rect(x - 32, y - 29, 64, 58, "#fff1ec", "#bc3458", 2)]
        value = "OMIT SWITCH" if ref == "SW" else comp["value"]
        if ref == "J1":
            value = ""
        parts += [
            text(x, y - 36, ref, 17, anchor="middle"),
            text(x, y + 38, value, 14, anchor="middle"),
        ]
        if ref in ("QP", "QL"):
            parts += [
                text(
                    x,
                    y + 61,
                    "1E 2B 3C" if ref == "QP" else "1D 2G 3S",
                    13,
                    anchor="middle",
                )
            ]
    for ref, num, net, px, py, drill in pad_rows:
        if not net:
            continue
        x, y = x0 + px * scale, y0 + py * scale
        color = COLORS.get(net, "#7a673a")
        parts += [
            f'<circle cx="{x}" cy="{y}" r="6.5" fill="{color}" stroke="#fff" stroke-width="1.5"/>'
        ]
        if ref == "J1":
            parts += [text(x, y + 38, num, 14, anchor="middle")]
        if ref == "SW":
            parts += [
                text(
                    x + (-10 if net == "OUT+" else 10),
                    y - 7,
                    net,
                    12,
                    color,
                    "end" if net == "OUT+" else "start",
                )
            ]
    parts += [text(935, 146, "J1 · left to right", 22)]
    j1 = [r for r in pad_rows if r[0] == "J1"]
    for i, r in enumerate(j1):
        parts += [
            text(940, 187 + i * 34, f"{r[1]}   {r[2]}", 19, COLORS.get(r[2], "#223840"))
        ]
    notes = [
        "QP pads: E / B / C",
        "QL pads: D / G / S",
        "Verify actual transistor leads.",
        "Db stripe → pad 1 / BTN_DIO",
        "Resistors have no polarity.",
        "Rbtn is 1k in this PCB.",
    ]
    for i, note in enumerate(notes):
        parts += [text(935, 440 + i * 29, note, 16)]
    parts += [text(50, 710, "REMOTE BUTTON · two wires to existing SW holes", 22)]
    for i, s in enumerate(
        [
            "OUT+ → upper-left SW hole: local (34.0, 45.0); KiCad (38.0, 49.0)",
            "BTN_N → upper-right SW hole: local (40.5, 45.0); KiCad (44.5, 49.0)",
            "These are both numbered 1 in the footprint. Select by coordinate + net, not number alone.",
            "Leave the four-leg PCB switch unpopulated. Its repeated pad-number groups conflict with these nets.",
            "Fitted remote switch must be open released, closed only when pressed; connect through an inline 2-pin plug.",
        ]
    ):
        parts += [text(50, 749 + i * 28, s, 17)]
    parts += [
        text(
            50,
            928,
            "DRC-clean copper layout ≠ tested electronics. Nominal component bodies are illustrative.",
            16,
            "#655c4d",
        )
    ]
    save(
        "pcb-placement.svg",
        1310,
        960,
        parts,
        "R5 PCB placement and exact detachable button solder pads",
    )


def overview():
    p = [
        text(45, 48, "R5 · MODULE WIRING", 28),
        text(
            45,
            80,
            "Use C3 pin numbers throughout, or S3 throughout. Module pad positions vary; match printed labels.",
            17,
        ),
    ]
    boxes = [
        (45, 140, 210, 180, "BATT · 1S LiPo"),
        (310, 140, 250, 250, "CHG · protected TP4056"),
        (650, 140, 280, 390, "PCB · J1 + SW holes"),
        (1030, 140, 255, 250, "BOOST · MT3608"),
        (650, 575, 280, 225, "ESP · SuperMini"),
        (45, 520, 510, 210, "REMOTE BUTTON · detachable"),
    ]
    for x, y, w, h, title in boxes:
        p += [rect(x, y, w, h), text(x + 18, y + 33, title, 18)]
    p += [
        text(65, 215, "+  → BAT+", 18, "#b74623"),
        text(65, 270, "−  → BAT− ONLY", 18, "#254854"),
    ]
    p += [line("255,210 310,210", "#b74623"), line("255,265 310,265", "#254854")]
    for i, t in enumerate(
        [
            "BAT+     OUT+",
            "BAT−     OUT−",
            "Keep BAT− and OUT− separate",
            "Verify protection is fitted",
        ]
    ):
        p += [text(330, 210 + i * 48, t, 15)]
    p += [
        line("560,210 650,210", "#b74623"),
        line("560,258 610,258 610,320 650,320", "#254854"),
    ]
    for i, t in enumerate(
        [
            "1 OUT+ ← CHG.OUT+",
            "2 VSW → BOOST.VIN+ + ESP.5V",
            "3 GND ← CHG.OUT−",
            "4 GATE → latch GPIO",
            "5 SENSE → button ADC GPIO",
            "6 GND → common load return",
        ]
    ):
        p += [text(668, 212 + i * 47, t, 15)]
    p += [
        line("930,258 1030,258", "#ae5811"),
        line("930,447 985,447 985,307 1030,307", "#254854"),
    ]
    for i, t in enumerate(
        [
            "VIN+ ← VSW",
            "VIN− / VOUT− → GND",
            "VOUT+ → LED +12V",
            "Set 12.0 V before LED connection",
        ]
    ):
        p += [text(1048, 210 + i * 45, t, 15)]
    p += [
        text(668, 507, "SW holes: OUT+ / BTN_N", 16, "#bc3458"),
        line("790,530 790,575", "#824ab4"),
        text(808, 558, "J1 harness", 14),
    ]
    for i, row in enumerate(
        [("Role", "C3", "S3"), ("Latch", "3", "9"), ("Button ADC", "4", "8")]
    ):
        p += [
            text(669, 632 + i * 33, row[0], 16),
            text(820, 632 + i * 33, row[1], 16),
            text(875, 632 + i * 33, row[2], 16),
        ]
    p += [
        text(669, 731, "5V ← VSW · GND ← OUT−", 16),
        text(669, 764, "Battery ADC omitted by default", 16),
    ]
    for i, t in enumerate(
        [
            "SW left upper hole → OUT+ lead",
            "SW right upper hole → BTN_N lead",
            "PCB ── keyed inline 2-pin plug ── remote NO contacts",
            "Press closes OUT+ to BTN_N. No GND button wire.",
            "PCB four-leg switch remains unpopulated.",
        ]
    ):
        p += [text(65, 580 + i * 29, t, 16)]
    p += [line("555,645 592,645 592,507 650,507", "#bc3458")]
    p += [rect(1030, 510, 255, 290), text(1050, 548, "LED / DRIVER", 20)]
    for i, t in enumerate(
        [
            "+12V common → strip +12V",
            "Strip R/G/B/WW/CW returns",
            "→ corresponding Q drains",
            "All Q sources → GND",
            "GPIO → 100Ω → Q gate",
            "Q gate → 10k → GND",
        ]
    ):
        p += [text(1048, 591 + i * 32, t, 15)]
    p += [
        text(
            45,
            855,
            "SYSTEM GND = CHG.OUT−, J1.3/J1.6, ESP.GND, BOOST.VIN−/VOUT− and all driver sources.",
            18,
        )
    ]
    p += [
        text(
            45,
            891,
            "CELL− = battery negative and CHG.BAT− only. Do not bridge it to system GND.",
            18,
            "#b74623",
        )
    ]
    p += [
        text(
            45,
            937,
            "GPIO pads are not 12 V tolerant. Disconnect external power harness before USB firmware flashing.",
            16,
        )
    ]
    save(
        "wiring.svg",
        1330,
        970,
        p,
        "R5 protected charger, latch PCB, detachable button and module wiring",
    )


def channels():
    p = [
        text(40, 45, "R5 · FIVE IDENTICAL LED CHANNELS", 27),
        text(
            40,
            78,
            "Separate hand-wired perfboard; these are circuit references, not pads on the 94 × 60 latch PCB.",
            17,
        ),
    ]
    for i, c in enumerate(wiring["channels"]):
        y = 150 + i * 145
        p += [
            rect(35, y - 32, 1210, 125),
            text(55, y, c["channel"], 22),
            text(55, y + 31, f"C3 GPIO{c['C3_GPIO']} / S3 GPIO{c['S3_GPIO']}", 15),
        ]
        p += [
            text(295, y, f"{c['series']} · 100Ω", 18),
            text(660, y, f"{c['Q']} · BS170", 19),
            text(985, y, f"LED {c['channel']} return", 18),
        ]
        p += [
            line(f"245,{y + 25} 310,{y + 25}"),
            rect(310, y + 15, 88, 20, "#8bb8cb"),
            line(f"398,{y + 25} 668,{y + 25}"),
            text(638, y + 17, "G", 16),
        ]
        p += [
            rect(670, y + 9, 48, 43, "#33434c"),
            text(730, y + 21, "D", 15),
            text(730, y + 50, "S", 15),
        ]
        p += [
            line(f"751,{y + 18} 975,{y + 18}"),
            line(f"751,{y + 48} 840,{y + 48} 840,{y + 75}"),
            text(850, y + 81, "GND", 15),
        ]
        p += [
            line(f"525,{y + 25} 525,{y + 64} 800,{y + 64} 800,{y + 75} 840,{y + 75}"),
            rect(555, y + 55, 70, 18, "#8bb8cb"),
            text(525, y + 88, f"{c['pulldown']} · 10k", 14),
        ]
    p += [
        text(
            40,
            910,
            "Keep each Q/Rg/Rp group together. Verify MOSFET D/G/S with the actual manufacturer datasheet.",
            17,
        ),
        text(
            40,
            942,
            "Proposed 35 × 15 mm isolated-pad placement is in driver-perfboard.svg; physical assembly remains unverified.",
            17,
        ),
    ]
    save(
        "led-driver.svg",
        1280,
        970,
        p,
        "Exact five-channel MOSFET resistor and GPIO wiring",
    )


if __name__ == "__main__":
    placement()
    overview()
    channels()
    print("Wrote PCB placement, module wiring and LED driver SVGs")

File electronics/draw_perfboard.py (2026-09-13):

#!/usr/bin/env python3
"""Draw the exact proposed isolated-pad driver layout from its manifest."""

import json
from pathlib import Path

from draw_guides import line, rect, save, text

ROOT = Path(__file__).resolve().parent
layout = json.loads((ROOT / "driver-layout.json").read_text())


def pos(hole):
    row, col = ord(hole[0]) - 65, int(hole[1:]) - 1
    return 115 + col * 65, 165 + row * 65


def make():
    content = [
        text(45, 45, "R5 · DRIVER PERFBOARD HOLE MAP", 27),
        text(
            45,
            78,
            "Component side • isolated pads • 35 × 15 mm • 2.54 mm pitch • nominal bodies, unmeasured",
            17,
        ),
    ]
    content += [rect(55, 105, 945, 380, "#e5d6b3", "#a39065")]
    for col in range(1, 14):
        content += [text(pos(f"A{col}")[0], 128, col, 15, anchor="middle")]
    for row in "ABCDE":
        content += [text(74, pos(row + "1")[1] + 5, row, 16)]
        for col in range(1, 14):
            x, y = pos(f"{row}{col}")
            content += [
                f'<circle cx="{x}" cy="{y}" r="8" fill="#ba9650" stroke="#fff0cd" stroke-width="2"/>'
            ]
    colors = ["#27764c", "#b74645", "#2968a3", "#967129", "#61559f"]
    for i, g in enumerate(layout["groups"]):
        color = colors[i]
        dx, dy = pos(g["Q_holes"]["D"])
        gx, gy = pos(g["Q_holes"]["G"])
        sx, sy = pos(g["Q_holes"]["S"])
        content += [
            rect(gx - 28, gy - 37, 56, 74, "#34434a", "#223139", 9),
            text(gx, gy + 5, g["Q"], 16, "#fff", "middle"),
        ]
        content += [
            line(f"{dx},{dy} {gx},{gy - 37}", color),
            line(f"{sx},{sy} {gx},{gy + 37}", color),
            text(dx - 16, dy + 5, "D", 13),
            text(gx - 43, gy + 5, "G", 13),
            text(sx - 16, sy + 5, "S", 13),
        ]
        for prefix, name in [("Rg", g["Rg"]), ("Rp", g["Rp"])]:
            a = pos(g[f"{prefix}_holes"]["a_body"])
            b = pos(g[f"{prefix}_holes"]["b_return"])
            content += [
                line(f"{a[0]},{a[1]} {b[0]},{b[1]}", color),
                f'<circle cx="{a[0]}" cy="{a[1]}" r="20" fill="#9ec8d0" stroke="{color}" stroke-width="3"/>',
                text(a[0], a[1] + 5, name, 13, "#203c45", "middle"),
            ]
        content += [text(gx, 510, g["channel"], 18, color, "middle")]
    gx, gy = pos("C13")
    content += [text(gx + 12, gy + 6, "GND", 16)]
    content += [
        text(
            45,
            563,
            "Underside: insulated jumpers for each column c = 2, 4, 6, 8, 10",
            20,
        )
    ]
    notes = [
        "Gate: B[c] → D[c+1] → E[c+1]. Source: C[c] → E[c].",
        "Common return: C2 → C4 → C6 → C8 → C10 → C13 → system GND.",
        "GPIO input wires: D2/D4/D6/D8/D10. Strip G/R/B/WW/CW returns: A2/A4/A6/A8/A10.",
        "Rg = 100Ω, body at D[c]. Rp = 10k, body at E[c+1]. Both resistors stand upright.",
        "Do not join entire rows or columns. Insulate upright return leads and all underside crossovers.",
        "Nominal assembled height 9.2 mm; actual part body size, bent leads and wire clearance need dry-fit.",
    ]
    for i, note in enumerate(notes):
        content += [text(45, 603 + i * 31, note, 17)]
    save(
        "driver-perfboard.svg",
        1090,
        810,
        content,
        "Exact proposed R5 isolated-pad driver perfboard hole and wiring layout",
    )


if __name__ == "__main__":
    make()

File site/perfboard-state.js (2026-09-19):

/* Pure assembly navigation, shared by the browser and Node tests. */
(function (scope) {
  const joinedHoles = (connection) => [
    ...(connection.joined_holes || [connection.from, connection.to]),
  ];
  const conductorId = (connection) =>
    connection.conductor_id ||
    (connection.connection_style === "continuous_ground_bus"
      ? `ground-bus:${connection.net}`
      : connection.id);
  const sourceName = (connection) =>
    `${connection.source_pin.component}.${connection.source_pin.role}`;
  function connections(board) {
    const groups = new Map();
    for (const edge of board.jumpers) {
      const id = conductorId(edge),
        existing = groups.get(id);
      if (existing) {
        existing.ids.push(edge.id);
        existing.joined_holes = [
          ...new Set([...existing.joined_holes, ...joinedHoles(edge)]),
        ];
        existing.to = edge.to;
      } else
        groups.set(id, {
          ...edge,
          conductor_id: id,
          ids: [edge.id],
          joined_holes: joinedHoles(edge),
        });
    }
    return [...groups.values()];
  }
  function jointInstruction(board, joint) {
    const depth = (
      -Math.min(...joint.points_mm.map((point) => point[2])) - board.size_mm[2]
    ).toFixed(1);
    return joint.formation === "retained_component_lead"
      ? `Do not trim ${joint.component_ref} leg ${joint.pin_role} at ${joint.hole} yet: retain it to the ${joint.net} wire window ${depth} mm below the board underside. Solder there, then trim only excess.`
      : `Fit one added solid-wire riser at ${joint.hole}. Join its lower end to the ${joint.net} wire window ${depth} mm below the board underside; lap-solder the module/button cable at the pad, without adding a second wire through that hole.`;
  }
  function connectionInfo(board, connection) {
    connection =
      connections(board).find(
        (item) => item.conductor_id === conductorId(connection),
      ) || connection;
    const holes = joinedHoles(connection),
      route = holes.join(" → "),
      reusedLead = connection.connection_style === "component_lead_bridge",
      groundBus = connection.connection_style === "continuous_ground_bus";
    let kind = "Insulated wire",
      label = `Wire ${connection.from} → ${connection.to}`,
      text = `On the solder side, add an insulated wire between ${connection.from} and ${connection.to} for ${connection.net}. Solder only the named pads or their component legs. A crossing is not a connection. Check continuity between the two endpoints.`;
    if (holes.length > 2 && !reusedLead && !groundBus) {
      kind = "Insulated net conductor";
      label = `Wire all ${connection.net} joints`;
      text = `Use one insulated conductor along ${route}. Make a stripped solder window at every named joint; keep all other spans and crossings insulated. These ${holes.length} joints share ${connection.net}. A drawn crossing does not join another net. Check continuity to every listed joint, not just the first and last. ${connection.instructions || ""}`;
    }
    if (reusedLead) {
      const source = sourceName(connection),
        length = connection.retained_lead_mm;
      kind = "Retained component leg";
      label = `Bend ${source}: ${connection.from} → ${connection.to}`;
      text = `Use the existing ${source} leg, not an additional wire. Keep at least ${length} mm of usable leg below the seated board. Bend it along ${route}; solder at every named hole for ${connection.net}. These are deliberate same-net joints. Trim only excess beyond the final joint after soldering. Check continuity at every named hole and check neighboring unlike-net pads for bridges. If the actual lead is too short or stiff, use an insulated link along this route instead; do not pull on the component body.`;
    } else if (groundBus) {
      const fullRoute = [
        ...new Set(
          board.jumpers
            .filter((item) => conductorId(item) === conductorId(connection))
            .flatMap(joinedHoles),
        ),
      ].join(" → ");
      kind = "Dedicated ground bus";
      label = `Ground bus ${connection.from} → ${connection.to}`;
      text =
        connection.insulated === false
          ? `Use one dedicated ground-bus conductor along ${fullRoute}. Solder every named tap. Size this conductor for the measured module and LED return current; a resistor leg must not carry that load. Insulate any crossing that is not a declared joint. ${board.hardware_revision === "R6" ? "Check continuity from every named tap to the specified supply ground. Keep the LED power-return conductor separate from the controller ground lead until their supply junction." : "Check continuity from every named tap to protected CHG.OUT−; keep BAT− separate."}`
          : `Run one dedicated insulated ground-bus wire from ${connection.from} to ${connection.to}. The complete bus visits ${fullRoute}. Strip a small window only at each named pad, solder the tap, and keep spans insulated. Size the conductor for the measured return current. Check continuity at every named tap.`;
    }
    for (const joint of connection.solder_joints || [])
      text += " " + jointInstruction(board, joint);
    return {
      kind,
      label,
      text,
      joinedHoles: holes,
      sourcePin: connection.source_pin ? { ...connection.source_pin } : null,
      retainedLeadMm: connection.retained_lead_mm ?? null,
      conductorId: conductorId(connection),
    };
  }
  function connectionCounts(board) {
    const unique = connections(board);
    const counts = {
      retainedLeads: 0,
      insulatedWires: 0,
      busWires: 0,
      addedWires: 0,
      connections: unique.length,
    };
    for (const connection of unique) {
      if (connection.connection_style === "component_lead_bridge")
        counts.retainedLeads++;
      else {
        counts.addedWires++;
        if (connection.connection_style === "continuous_ground_bus")
          counts.busWires++;
        else counts.insulatedWires++;
      }
    }
    const joints = unique.flatMap((wire) => wire.solder_joints || []);
    if (joints.length) {
      counts.retainedRisers = joints.filter(
        (joint) => joint.formation === "retained_component_lead",
      ).length;
      counts.riserWires = joints.filter(
        (joint) => joint.formation === "single_riser_wire",
      ).length;
      counts.retainedLeads += counts.retainedRisers;
      counts.addedWires += counts.riserWires;
    }
    return counts;
  }
  function componentInstructions(board, part) {
    const notes = [...(part.notes || [])];
    if (part.adapter)
      notes.push(
        `${part.adapter.product}: ${part.adapter.face}. ${part.adapter.packages.length} SOT23 package(s) on this adapter. The carrier pin roles below refer to this adapter, not a TO92 package.`,
      );
    if (part.adapter?.instructions) notes.push(part.adapter.instructions);
    for (const connection of board.jumpers.filter(
      (item) =>
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

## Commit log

2026-09-13 Publish Dark Moth website from a9768599db2d
    Source revision: a9768599db2dd0405eba8cd72361c9d59a1481ea
    [black-parts.3mf, body.stl, button.stl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]
2026-09-13 Publish Dark Moth website from eca8f828c764
    Source revision: eca8f828c764bc166dcc9b390f74bd7243348704
    [black-parts.3mf, body-p1s-petg.3mf, button-p1s-petg.3mf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]
2026-09-18 Publish Dark Moth website from b3df1463f619
    Source revision: b3df1463f619a3631e34b9617324f55b05701965
    [perfboard-components.csv, perfboard-connections.csv]
2026-09-18 Publish Dark Moth website from c9bca377fbbe
    Source revision: c9bca377fbbe6a8d4fb76ce6853ad011bacc084a
    [perfboard-components.csv, perfboard-connections.csv]
2026-09-18 Publish Dark Moth website from d710838105e2
    Source revision: d710838105e22b5c7c6039b7c42889dddbfa452d
    [perfboard-components.csv, perfboard-connections.csv]
2026-09-19 Publish Dark Moth website from c60f05d5d25c
    Source revision: c60f05d5d25c6b02b084e1e4e6a8073355db4247
    [battery_bridge.stl, battery_insert.stl, black-parts.3mf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]
